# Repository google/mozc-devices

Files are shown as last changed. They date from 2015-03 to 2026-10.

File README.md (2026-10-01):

Circuit diagrams and firmware source code for Gboard DIY keyboards, previously
known as Google Japanese Input / Gboard April Fools.

This is not an officially supported Google product.

# Products

Please refer to the README in each directory for more details.

<table>
<tr>
<td>

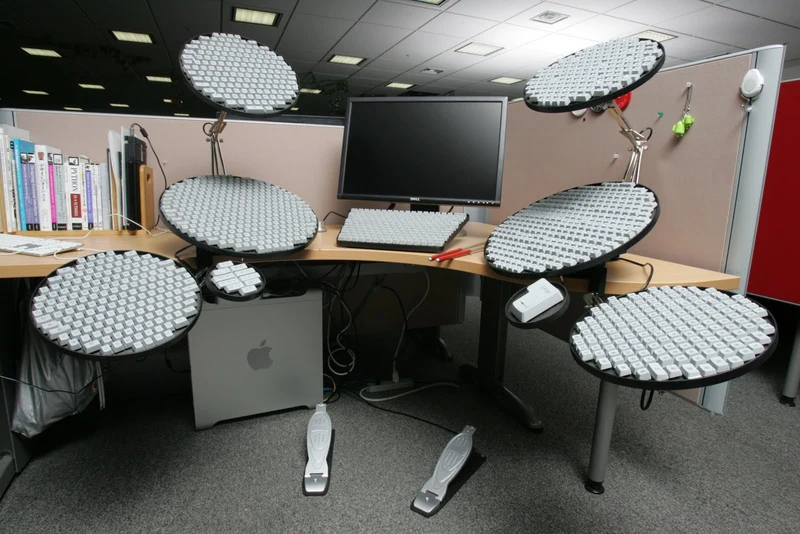
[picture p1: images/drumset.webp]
drumset


[Google 日本語入力 ドラムセットバージョン](https://archive.google/drumsetkeyboard/)<br>
[Google Japanese Input Drum set version](https://archive.google/drumsetkeyboard/)

変換の煩わしさを感じさせない思いどおりの日本語入力を提供します。

- [Announce](https://blog.google/intl/ja-jp/products/android-chrome-play/2010_04_google/)
- Release date: Apr 1, 2010
- Source: Not open source

</td>
<td>

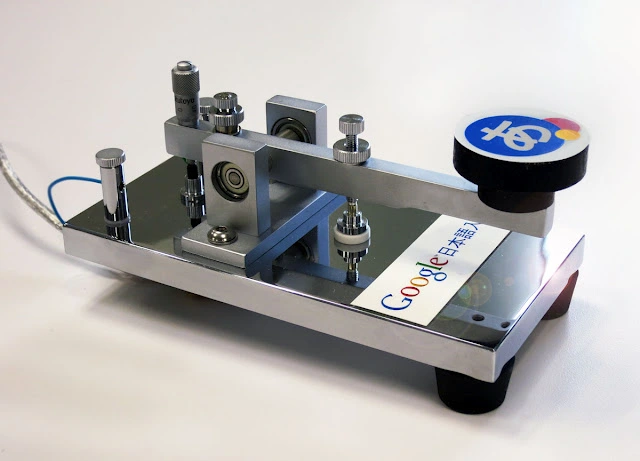
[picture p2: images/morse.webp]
morse


[Google 日本語入力 モールスバージョン](http://www.google.co.jp/ime/-.-.html)<br>
[Google Japanese Input Morse version](http://www.google.co.jp/ime/-.-.html)

モールス符号で思いどおりの日本語入力

- [Promotional video](https://www.youtube.com/watch?v=u5AYb778pwA)
- [Announce](https://japan.googleblog.com/2012/04/google.html)
- [Technical details](http://googledevjp.blogspot.jp/2012/06/google.html)
- Release date: Apr 1, 2012
- Source: [/third_party/mozc-morse](./third_party/mozc-morse)

</td>
</tr>
<tr>
<td>

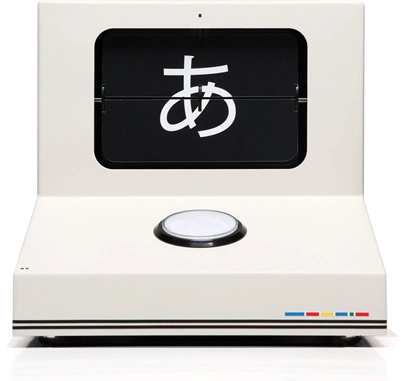
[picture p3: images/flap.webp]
flap


[Google 日本語入力 パタパタバージョン](http://www.google.co.jp/ime/patapata/)<br>
[Google Japanese Input Patapata version](http://www.google.co.jp/ime/patapata/)

もう、なにも覚える必要はありません。
押して離すだけの日本語入力。

- [Promotional video](https://www.youtube.com/watch?v=HzUDAaYMNsA)
- [Announce](https://japan.googleblog.com/2013/04/google-patapata.html)
- [Technical details](http://googledevjp.blogspot.jp/2013/10/google.html)
- Release date: Apr 1, 2013
- Source: [/third_party/mozc-flap](./third_party/mozc-flap)

</td>
<td>

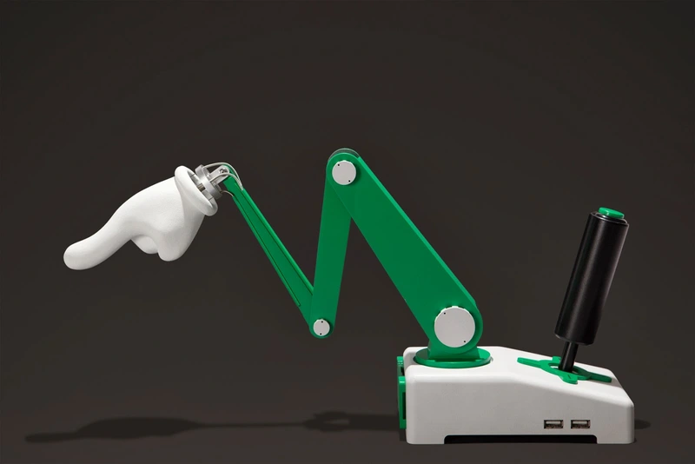
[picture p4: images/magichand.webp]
magichand


[Google 日本語入力 マジックハンドバージョン](https://archive.google/ime/m9/)<br>
[Google Japanese Input Magic hand version](https://archive.google/ime/m9/)

マジックハンドでらくらく入力

- [Promotional video](https://www.youtube.com/watch?v=0u1zoaJYAmw)
- [Announce](https://blog.google/intl/ja-jp/products/android-chrome-play/2014_04_m9/)
- Release date: Apr 1, 2014
- Source: Not open source

</td>
</tr>
<tr>
<td>

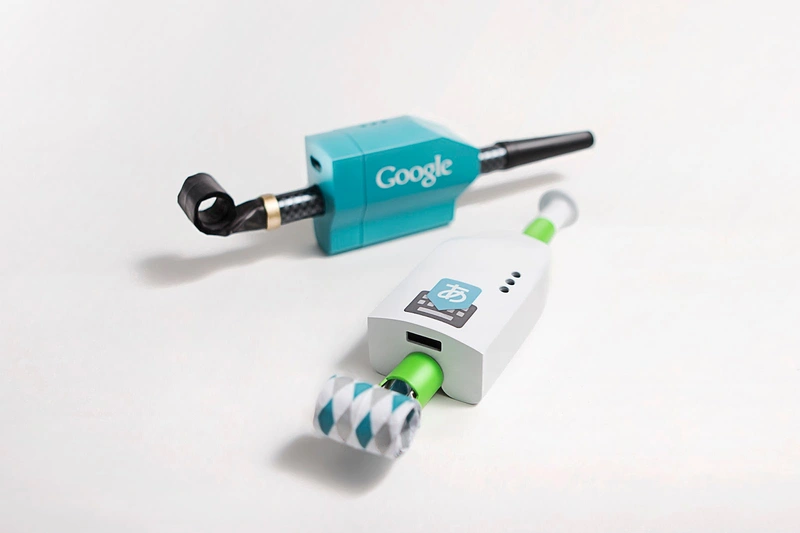
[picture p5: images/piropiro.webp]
piropiro


[Google 日本語入力 ピロピロバージョン](https://www.google.co.jp/ime/___o/)<br>
[Google Japanese Input Piropiro version](https://www.google.co.jp/ime/___o/)

もうキーはいらない

- [Promotional video](https://www.youtube.com/watch?v=gAgOnQqyDz0)
- [Announce](https://japan.googleblog.com/2015/04/piropiro.html)
- Release date: Apr 1, 2015
- Source: [/mozc-piropiro](./mozc-piropiro)

</td>
<td>

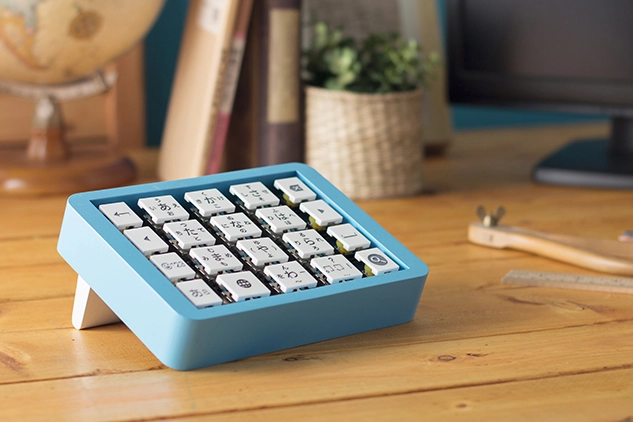
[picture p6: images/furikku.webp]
furikku


[Google 日本語入力 物理フリックバージョン](https://www.google.co.jp/ime/furikku/)<br>
[Google Japanese Input Physical Flick version](https://www.google.co.jp/ime/furikku/)

さわれるフリック

- [Promotional video](https://www.youtube.com/watch?v=5LI1PysAlkU)
- [Announce](https://japan.googleblog.com/2016/04/furikku.html)
- Release date: Apr 1, 2016
- Source: [/mozc-furikku](./mozc-furikku)

</td>
</tr>
<tr>
<td>

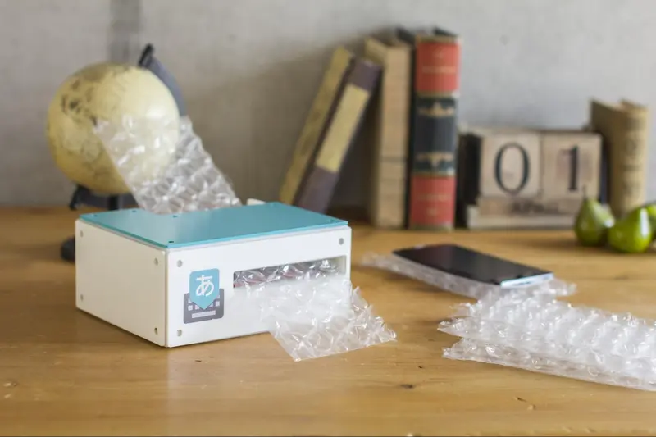
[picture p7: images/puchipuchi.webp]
puchipuchi


[日本語入力 プチプチバージョン](https://landing.google.co.jp/ime/ooooo/)<br>
[Google Japanese Input Puchi Puchi version](https://landing.google.co.jp/ime/ooooo/)

空気のように、軽やかな入力。

- [Promotional video](https://www.youtube.com/watch?v=RkJZDvHMyTA)
- [Announce](https://japan.googleblog.com/2017/04/ooooo.html)
- Release date: Apr 1, 2017
- Source: [/third_party/mozc-puchi](./third_party/mozc-puchi)

</td>
<td>

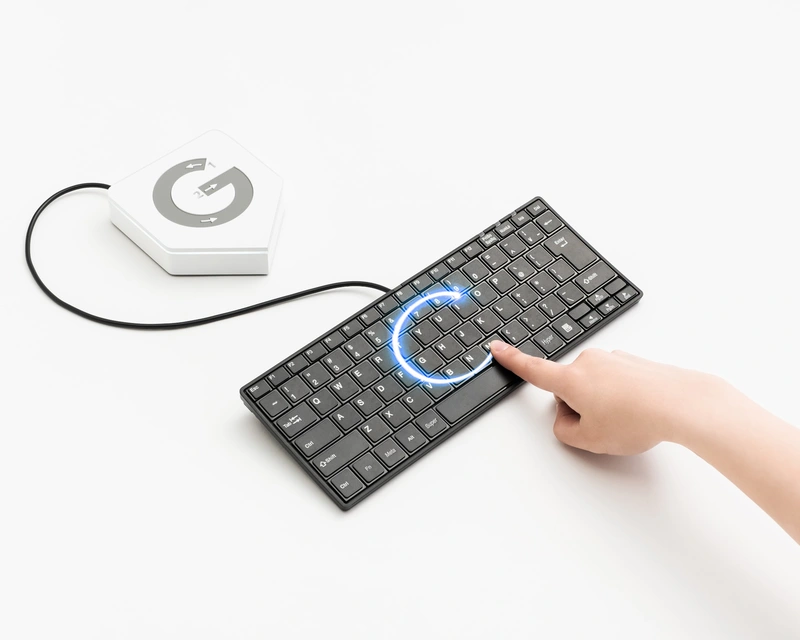
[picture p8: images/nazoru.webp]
nazoru


[Gboard 物理手書きバージョン](https://landing.google.co.jp/tegaki/)<br>
[Gboard Physical Handwriting version](https://landing.google.co.jp/tegaki/)

新しいタイプの手書き入力。

- [Promotional video](https://www.youtube.com/watch?v=guJnFY1R4I0)
- [Announce](https://japan.googleblog.com/2018/04/tegaki.html)
- [Technical details](https://developers-jp.googleblog.com/2018/04/tegaki.html)
- Release date: Apr 1, 2018
- Source: [/mozc-nazoru](./mozc-nazoru)

</td>
</tr>
<tr>
<td>

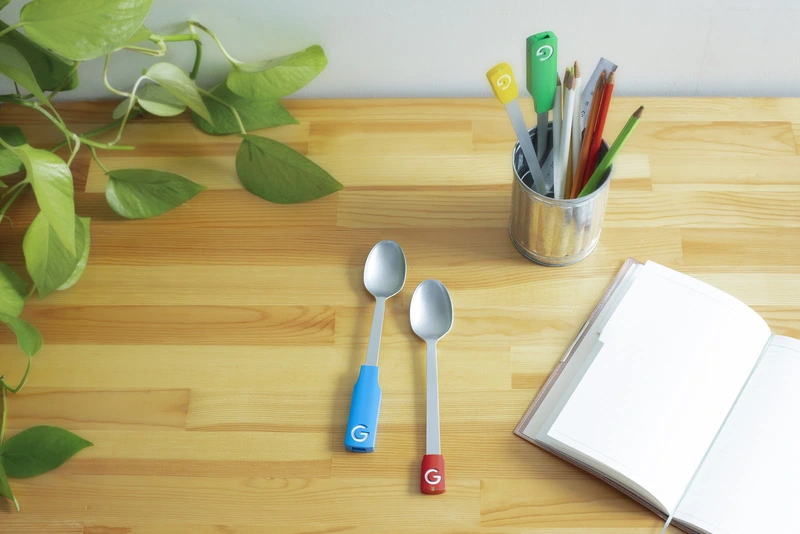
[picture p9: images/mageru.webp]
mageru


[Gboard スプーン曲げバージョン](https://landing.google.co.jp/---o/)<br>
[Gboard Spoon Bending version](https://landing.google.co.jp/---o/)

タネも仕掛けもない、柔軟な入力。

- [Promotional video](https://www.youtube.com/watch?v=DeJY5d14qKs)
- [Announce](https://japan.googleblog.com/2019/04/mageru.html)
- Release date: Apr 1, 2019
- Source:
  - [/mozc-mageru](./mozc-mageru) for firmware, schematics, and PCB layout.
  - [/third_party/mozc-mageru](./third_party/mozc-mageru) for 3D model.

</td>
<td>

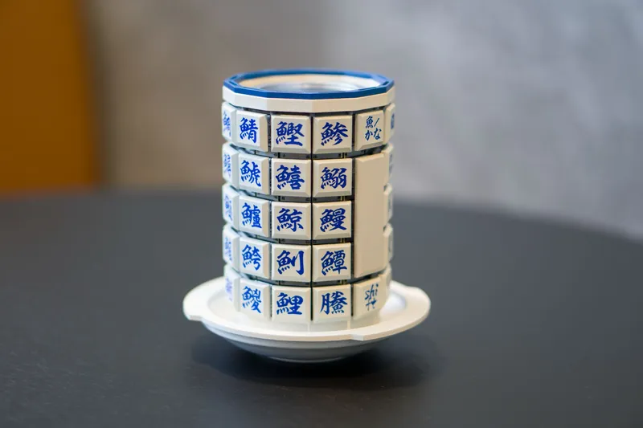
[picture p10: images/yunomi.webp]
yunomi


[Gboard 湯呑みバージョン](https://g.co/yunomi/)<br>
[Gboard yunomi version](https://g.co/yunomi/)

もう、おすしかない。

- [Promotional video](https://www.youtube.com/watch?v=20pC05yisRM)
- [Announce](https://japan.googleblog.com/2021/10/gboard.html)
- Release date: Oct 1, 2021
- Source: [/mozc-yunomi](./mozc-yunomi)

</td>
</tr>
<tr>
<td>

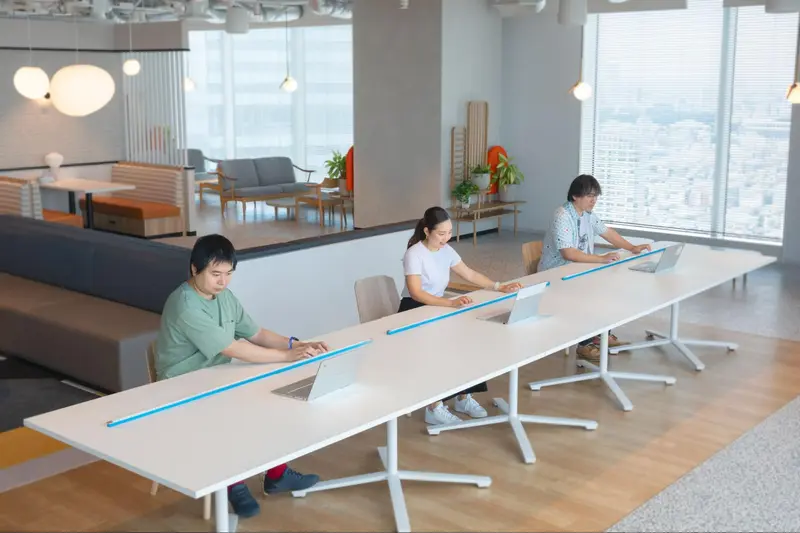
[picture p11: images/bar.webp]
bar


[Gboard 棒バージョン](https://g.co/____)<br>
[Gboard bar version](https://g.co/____)

キーの次はボーです。

- [Promotional video](https://www.youtube.com/watch?v=9G3DWHf1xX0)
- [Announce](https://japan.googleblog.com/2022/10/gboard-2022.html)
- Release date: Oct 1, 2022
- Source: [/mozc-bar](./mozc-bar)

</td>
<td>

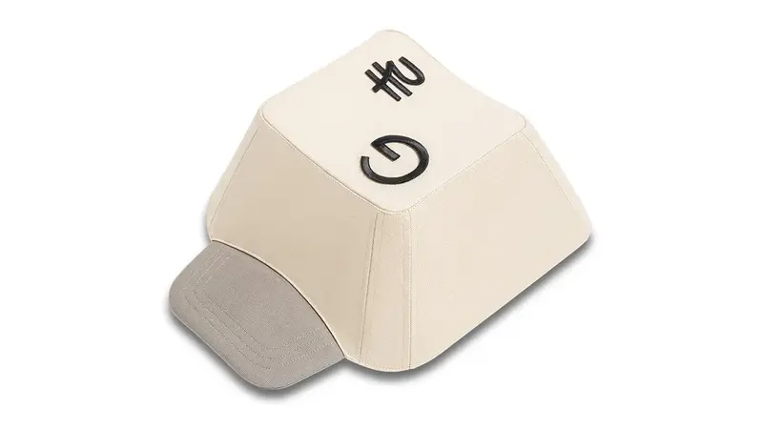
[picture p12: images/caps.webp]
caps


[Gboard 帽バージョン](https://g.co/CAPS)<br>
[Gboard CAPS version](https://g.co/CAPS)

入力は、帽険だ。

- [Promotional video](https://www.youtube.com/watch?v=6vib77CUxNM)
- [Announce](https://japan.googleblog.com/2023/10/caps.html)
- Release date: Oct 1, 2023
- Source: [/mozc-caps](./mozc-caps)

</td>
</tr>
<tr>
<td>

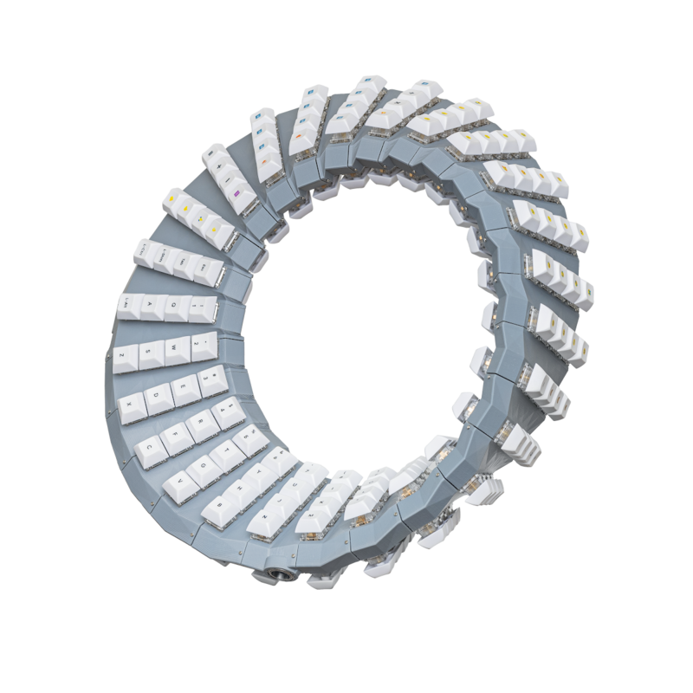
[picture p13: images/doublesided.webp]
double sided


[Gboard 両面バージョン](https://g.co/double-sided)<br>
[Gboard double sided version](https://g.co/double-sided)

表面かと思ったら裏面でした。

- [Promotional video](https://www.youtube.com/watch?v=EHqPrHTN1dU)
- [Announce](https://blog.google/intl/ja-jp/products/android-chrome-play/gboard-2024)
- Release date: Oct 1, 2024
- Source: [/mozc-doublesided](./mozc-doublesided)

</td>
<td>

dial

[Gboard ダイヤルバージョン](./mozc-dial/README_ja.md)<br>
[Gboard Dial Version](./mozc-dial)

まるくおさめました。

- [Promotional video](https://youtu.be/BgdWyD0cBx4)
- [Announce](https://blog.google/intl/ja-jp/products/android-chrome-play/gboard-2025)
- Release date: Oct 1, 2025
- Source: [/mozc-dial](./mozc-dial)

</td>
</tr>
<tr>
<td>

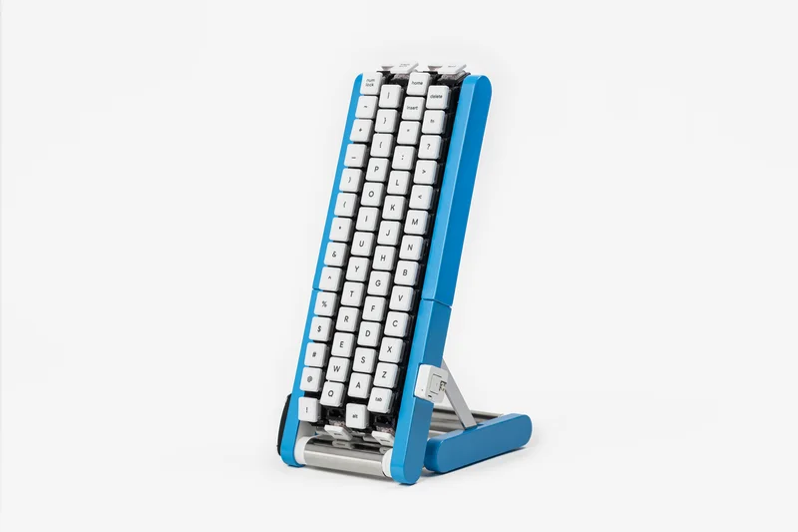
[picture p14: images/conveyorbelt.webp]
conveyorbelt


[Gboard くるくる バージョン](./mozc-conveyorbelt/README_ja.md)<br>
[Gboard Conveyor Belt version](./mozc-conveyorbelt)

流れるような文字入力を

- [Promotional video](https://www.youtube.com/watch?v=DAn34l_YrUM)
- [Announce](https://blog.google/intl/ja-jp/products/android-chrome-play/gboard-2026/)
- Release date: Oct 1, 2026
- Source: [/mozc-conveyorbelt](./mozc-conveyorbelt)

</td>
<td>
</td>
</tr>
</table>

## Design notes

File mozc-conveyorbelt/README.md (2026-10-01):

[Japanese version](./README_ja.md) is available.

# Gboard Conveyor Belt Version

This directory contains the design data and firmware for the Gboard Conveyor Belt Version, released on October 1, 2026.
The Gboard Conveyor Belt Version is not an official Google product.

Gboard conveyor belt version

## Contents

The directory structure is as follows:

- board/ : KiCad schematics and PCB layouts.
- firmware/ : Firmware source code and projects.
- stls/ : 3D printable STL files for the case and mechanisms.

## Let's build it

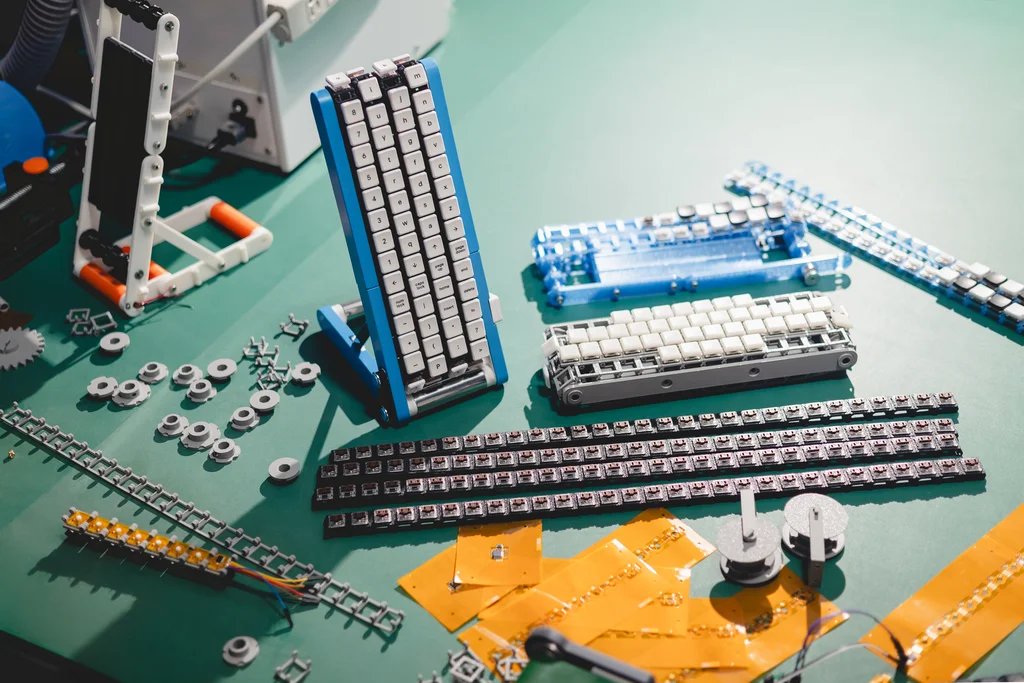
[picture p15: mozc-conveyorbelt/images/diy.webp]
Gboard DIY


This year again, we are releasing 3D printing model data, board data, and firmware.

[Click here for the build guide](./buildguide.md)

## There's also a Gboard that doesn't come to you

For those who are accustomed to moving their hands for text input, we also offer the standard version of Gboard.

It provides a comfortable input experience in conjunction with various Google services such as voice input and translation functions.

[Available on Google Play](https://play.google.com/store/apps/details?id=com.google.android.inputmethod.latin)<br>
[Available on the App Store](https://apps.apple.com/us/app/gboard-the-google-keyboard/id1091700242)

## [Other versions](https://github.com/google/mozc-devices)

## License

See [LICENSE](../LICENSE) file in this directory.

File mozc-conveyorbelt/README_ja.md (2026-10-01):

[English version](./README.md) is available.

# Gboard くるくる バージョン

このディレクトリは 2026 年 10 月 1 日にリリースされた Gboard くるくる バージョンの設計データとファームウェアを含んでいます。
Gboard くるくる バージョンは正式な Google 製品ではありません。

Gboard conveyor belt version

## 構成

ディレクトリ構成は以下の通りです：

- board/ : KiCad 回路図と基板レイアウトデータ
- firmware/ : ファームウェアのソースコードおよびプロジェクト
- stls/ : ケースや機構部品の 3D プリント用 STL ファイル

## 作ってみよう

Gboard DIY

今年も 3D プリント用モデルデータ、基板データ、ファームウェアを公開しています。

[ビルドガイドはこちら](./buildguide_ja.md)

## こないGboardもあります

いままでの手を動かす文字入力に慣れ親しんだ方には、通常版の Gboard もご用意しております。

音声入力や翻訳機能など Google の各種サービスと連携した快適な入力体験を提供します。

[Google Play で公開中](https://play.google.com/store/apps/details?id=com.google.android.inputmethod.latin&hl=ja)<br>
[App Store で公開中](https://apps.apple.com/jp/app/id1091700242)

## [その他のバージョン](https://github.com/google/mozc-devices)

## ライセンス

このディレクトリに置かれた [LICENSE](../LICENSE) ファイルを参照してください。

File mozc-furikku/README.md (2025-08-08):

Copyright 2016 Google Inc.

Licensed under the Apache License, Version 2.0 (the "License");
you may not use this file except in compliance with the License.
You may obtain a copy of the License at

    http://www.apache.org/licenses/LICENSE-2.0

Unless required by applicable law or agreed to in writing, software
distributed under the License is distributed on an "AS IS" BASIS,
WITHOUT WARRANTIES OR CONDITIONS OF ANY KIND, either express or implied.
See the License for the specific language governing permissions and
limitations under the License.

Summary
=====================================

Circuit diagram and firmware of Google Japanese Input physical flick version.

Files
=====================================

* README.md  -- this file
* arduino/flick/*  -- firmware source code (Arduino sketch)
* circuit.png  -- circuit diagram
* photo/*  -- for reference

Building your device
=====================================

## Electronic parts

* Arduino Nano * 1
* RN-42-I/RM * 1
* SJoys 2-axis joystick module (Sainsmart) * 12
* MCP3208 * 3
* 0.1uF ceramic capacitor * 4
* 470 ohm resistor * 1
* 1k ohm resistor * 1
* Connectors

## RN42 configuration

This step is required for the first time, or when changing the device's name.
See Microchip's documents for detail.

1. Run a terminal emulator and open the serial port for Arduino.
2. Type '!' to enter pass-through mode.
3. Type '$$$'.
4. Configure the module by these commands:

* * * * * *
    SU,115k
    SM,6
    SA,2
    S~,6
    SH,0000
    SN,MY_PHYSICAL_FLICK_KEYBOARD
    R,1
* * * * * *
MY\_PHYSICAL\_FLICK\_KEYBOARD is a device name that will appear when you scan
Bluetooth devices, and can be replaced by your preferred name.

The commands will configure the module as follows:

* 115200bps
* Pairing mode
* SSP "just works" mode
* SPP profile
* HID flag register = 0 (keyboard)

Using flick input
=====================================

## Power supply

When operating the device, supply power by USB cables to Arduino Nano.

## Bluetooth pairing

Using your device (e.g. Android phone), scan Bluetooth devices and you will
find MY\_PHYSICAL\_FLICK\_KEYBOARD (or the name you set up) in the available
device list.

After pairing, find the device in the "physical keyboard" section and choose
"English - U.S." keyboard layout for it.

## How to input

Switch the Japanese IME on the paired device to romaji input mode.
Characters will be input as flick or press a key.

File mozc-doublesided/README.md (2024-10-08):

# Gboard double sided version

This directory contains the firmware and hardware design for Gboard double sided
version, which was released on **Oct 1, 2024**.

This is not an officially supported Google product.

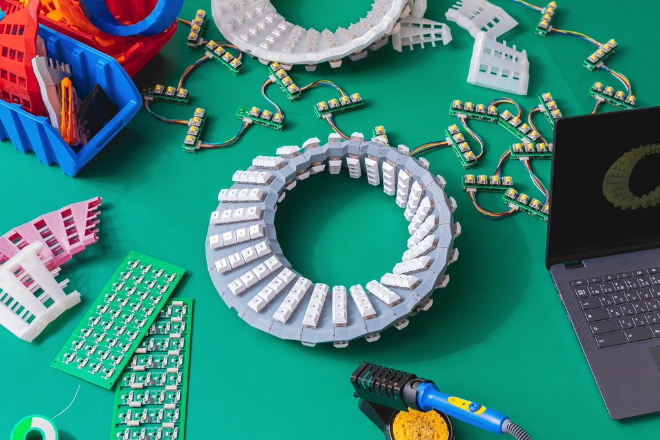
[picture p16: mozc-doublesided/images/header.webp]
Gboard double sided version


## Contents

The directory structure is as follows:

-   case/ : STL files for case
-   board/ : KiCad schematics and PCB layouts
-   firmware/ : Firmware resources for STM32CubeIDE
-   gerber/ : Gerber data for PCB production and assembly

## Building Gboard double-sided Version

### Parts

-   Assembled A Type Board: 26 boards (incl. 1 primary board) - See BOM below
-   Assembled B Type Board: 26 boards (incl. 1 primary board) - See BOM below
-   USB Board: 1 board - See BOM below
-   Cable A; JST ZH 1.5mm pitch 8pin 100mm forward double head: 25 units
-   Cable B; JST ZH 1.5mm pitch 7pin 100mm forward double head: 1 units
-   Pin Header; 1x4 pin 2.54mm pitch 12+mm height,
    ([sample](https://akizukidenshi.com/catalog/g/g101382/)): 52 headers.
-   3D printed case: 26 pcs
-   Self tapping screw (M2 10mm): 52 pcs
-   Key switch (Cherry MX or compatible): 208 pcs.
-   Key caps (For Cherry MX switch): 208 pcs.

#### A Type Board BOM

| Reference | Description | Qty | Note |
| --- | --- | --- | --- |
| R1-R2 | 0402(metric: 1005) Resistor 510 ohm | 2 | |
| R3-R4 | 0603(metric: 1608) Resistor 1K ohm  | 2 | Primary board only |
| J2-J3 | JST S8B-ZR | 2 | |
| J4 | JST S7B-ZR | 1 | Primary board only |
| U1 | STMicro STM32F042F4P6 | 1 | |
| SW1-SW4 | Kailh CPG151101S11-1 | 4 | |
| D1-D4 | OPSCO Optoelectronics SK6812MINI-E  | 4 | |
| D5-D8 | 0805(metric: 2012) Small Signal Switching Diode | 4 | |
| C1 | 0402(metric: 1005) Capacitor 0.1uF  | 1 | |

The parts that are only on the primary board are not included in the BOM file
(in `gerber/` directory), so make sure that you choose one board to be the
primary board and solder in the primary board specific parts.

#### B Type Board BOM

Reference | Description                                     | Qty | Note
--------- | ----------------------------------------------- | --- | ----
R2        | 0402(metric: 1005) Resistor 510 ohm             | 1   |
SW1-SW4   | Kailh CPG151101S11-1                            | 4   |
D1-D4     | OPSCO Optoelectronics SK6812MINI-E              | 4   |
D5-D8     | 0805(metric: 2012) Small Signal Switching Diode | 4   |

#### USB Board BOM

Reference | Description                          | Qty | Note
--------- | ------------------------------------ | --- | ----
U1        | 1A/3.3V Regulator AMS1117-3.3        | 1   |
R1-R2     | 0402(metric: 1005) Resistor 5.1K ohm | 2   |
R3-R4     | 0402(metric: 1005) Resistor 22 ohm   | 2   |
R5        | 0402(metric: 1005) Resistor 1.5K ohm | 1   |
J1        | JST S7B-ZR                           | 1   |
J2        | USB Type-C 16pin connector           | 1   |
C1        | 0402(metric: 1005) Capacitor 10uF    | 1   |
C2        | 0402(metric: 1005) Capacitor 2.2uF   | 1   |
C3-C4     | 0402(metric: 1005) Capacitor 47pF    | 2   |

### Hardware

#### Step 1: Prepare 3d printed parts

The `case/` directory of this repository has STL files for the case. The case
consists of 26 parts (case00.stl - case25.stl). Each part has a number engraved
on the inside. For example, when assembling, you will insert the protrusion of
case 0 into the hole of case 1.

We also provide a jig (`case/jig.stl`) for soldering between the A type boards
and B type boards. Please print this too.

#### Step 2: Prepare PCB

**PCB Production and Assembly**

First, you need to build 26 A type boards and 26 B type boards, and one USB
board. You may be able to use existing gerber data, BOM, and CPL (positions)
from `gerber/` directory.

Board Type | Gerber         | BOM                | CPL
---------- | -------------- | ------------------ | ------------------------
A          | main_panel.zip | main_panel_bom.csv | main_panel_positions.csv
B          | sub_panel.zip  | sub_panel_bom.csv  | sub_panel_positions.csv
USB        | usb.zip        | usb_bom.csv        | usb_positions.csv

Prepared board data for the A type board and the B type board contains 9 boards
in a panel. So, you need to produce 3 panels to build 27 (26 required + 1 spare)
boards. You also need one USB board.

**Firmware upload**

Next, let's burn the prebuilt firmware.

Connect the following 4 pads, SWDIO, SWCLK, GND, and +3.3V with ST-LINK. You can
use
[STM32CubeProgrammer](https://www.st.com/ja/development-tools/stm32cubeprog.html)
to configure the device and to burn the prebuilt firmware. There's no connector,
just holes in the PCB so make sure you keep a secure connection while
programming the device.

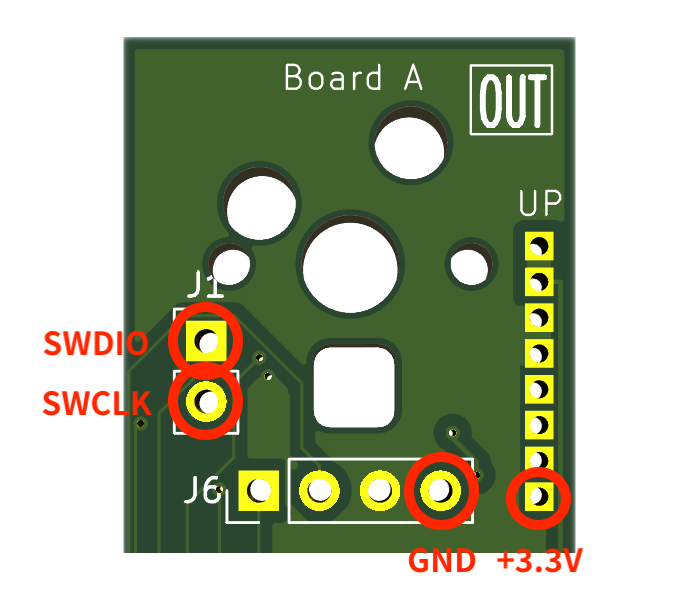
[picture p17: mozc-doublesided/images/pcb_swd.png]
Required SWD and power pins


Once the programmer establishes the connection with the A type board, you need
to write the `Option bytes`. Under the `User Configuration` section, you will
see the `BOOT_SEL` bit. You need to ensure the bit is unchecked before pushing
the `Apply` button.

Next, you will go to the `Erasing & Programming` section to burn the prebuilt
firmware, `firmware/prebuilt/mozc.elf`. Select the binary from the `Browse`
button, put `0x08000000` for the `Start address`, then press the `Start
Programming` button.

You need to burn the same settings and firmware into all the Boards A.

**Primary A Type Board Specific Modifications**

You need to choose one of the A type boards to be the primary A type board and
add three parts to it.

1.  J4 JST S7B-ZR connector header
2.  R3 0603 Resistor 1K ohm
3.  R4 0603 Resistor 1K ohm

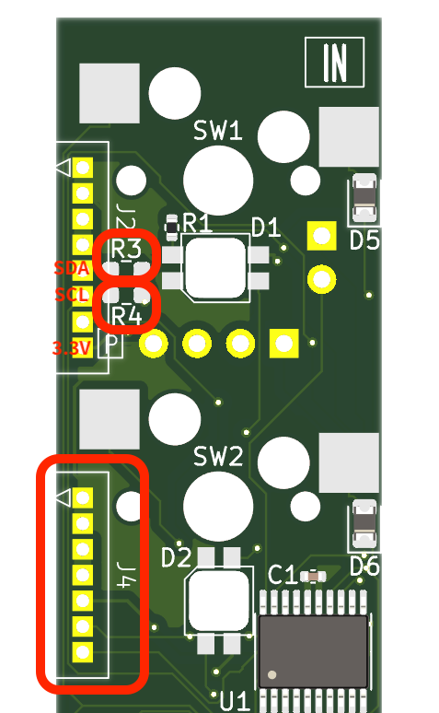
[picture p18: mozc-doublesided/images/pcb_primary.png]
Primary A Type Board Modifications Points


**Construct the A/B Type Board Pair Modules**

You need to prepare 26 pairs of the A type board and B type board. They should
be paired as the following picture shows. Each `P Connector` and each `S
connector` should be connected using the 1x4 pin headers respectively.

Make sure that the `IN` side of the A type board and B type board face each
other.

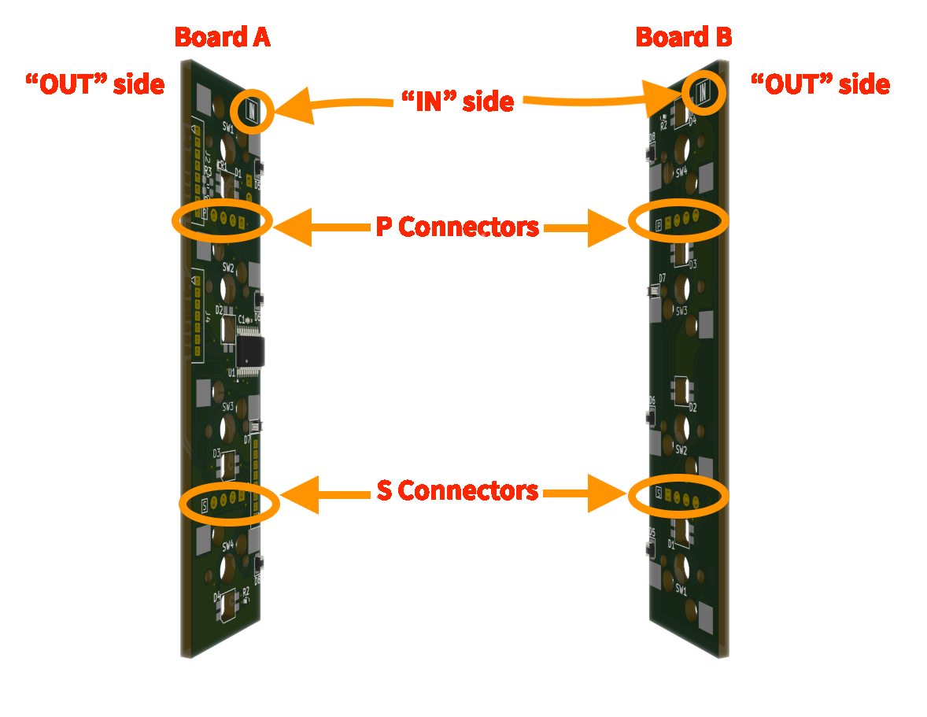
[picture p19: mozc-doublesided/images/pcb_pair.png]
Pairing A type board and B type boards


Also, the distance should be adjusted to fit the case. It will help to print the
included jig STL to hold both boards while soldering the pin headers.

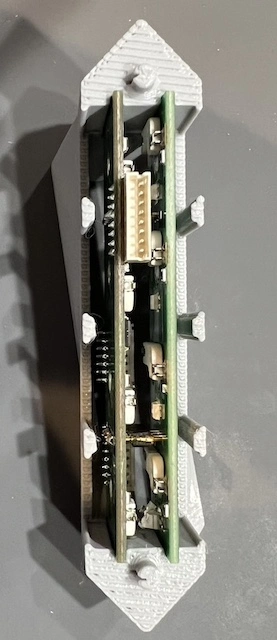
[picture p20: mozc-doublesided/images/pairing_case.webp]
Pairing with actual case

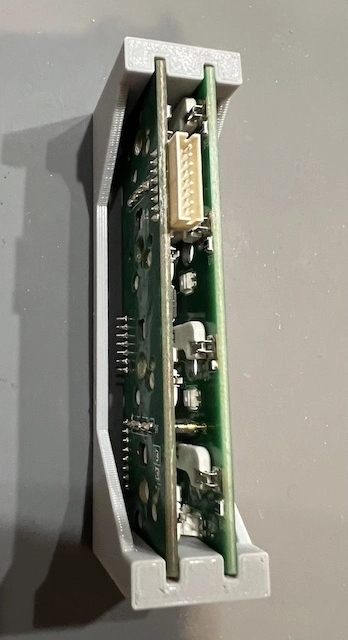
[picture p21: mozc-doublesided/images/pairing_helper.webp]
Pairing with helper case


#### Step 3: Insert PCB to case

**Primary A/B Pair Module**

Connect the primary module and the USB board.

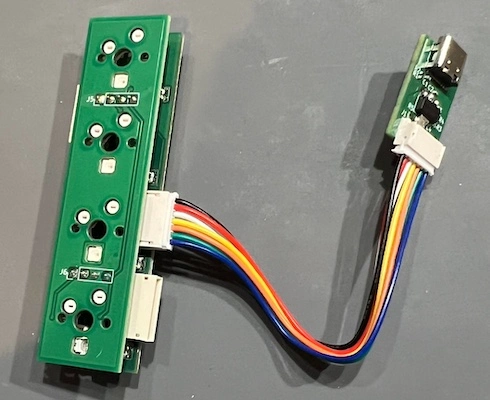
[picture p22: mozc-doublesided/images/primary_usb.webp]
Connect Primary and USB board


Insert the USB board into case 0.

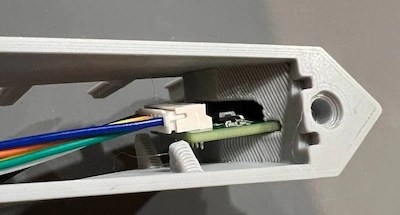
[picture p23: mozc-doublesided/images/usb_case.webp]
Insert USB board to the case


**All Pair Modules**

Insert each paired module into a case. You need to ensure the A type board is
always placed on the bottom side.

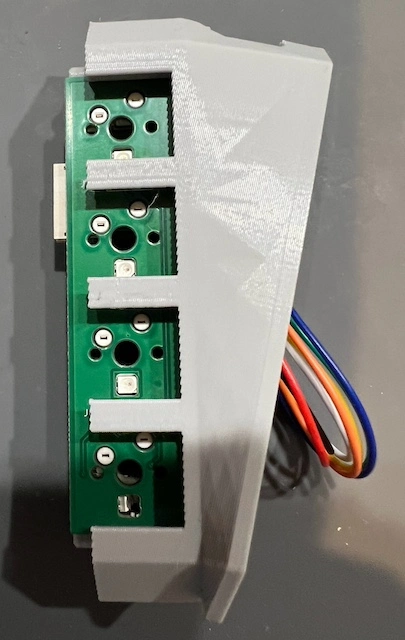
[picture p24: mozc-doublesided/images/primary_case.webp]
Insert the pair board into the case


#### Step 4: Connect the cases together

You need to connect all the `UP` socket and `DOWN` socket pairs. Please be
careful not to connect the same type of socket, i.e. `UP` and `UP`, or `DOWN`
and `DOWN` together. It will cause a short circuit and destroy the chips when
powered on. If you notice a smell or see smoke, disconnect the power
immediately. This may prevent damage to the boards.

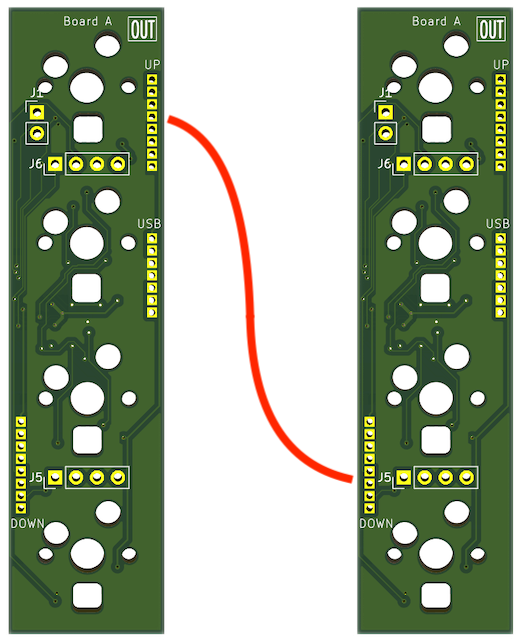
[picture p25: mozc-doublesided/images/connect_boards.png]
Connect boards


The below picture shows the connections. Please make sure that module 0 and
module 25 are not connected to each other.

Note that this picture is simplified and doesn't reflect the 3d structure of the
keyboard. So, module 25 will be placed upside down.

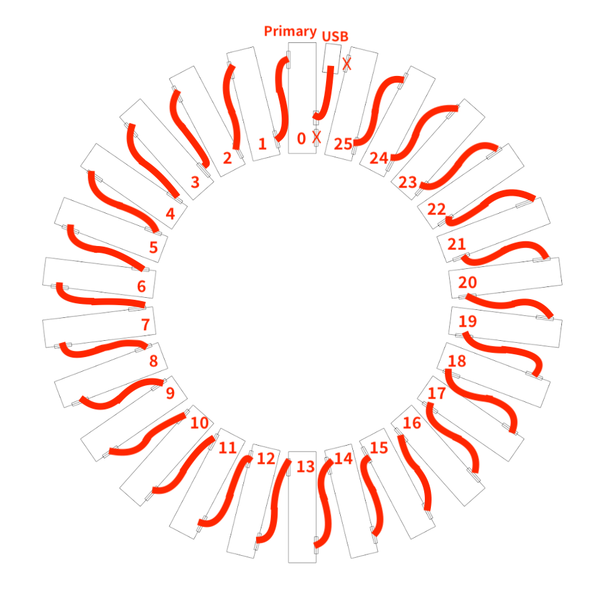
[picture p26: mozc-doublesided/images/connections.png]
Connections


You can use screws to keep the boards tightly connected.

### Firmware

#### Step 1: Environment setup

You need to install STMicroelectronics's official tools to develop STM32.

-   [STM32CubeIDE](https://www.st.com/en/development-tools/stm32cubeide.html) -
    Confirmed with 1.16.1.
-   [STM32CubeMX](https://www.st.com/en/development-tools/stm32cubemx.html) -
    Confirmed with 6.12.1.

Alternatively, you can use Visual Studio Code with the STM32 VS Code Extension,
STM32CubeMX, and STM32CubeCLT if your development environment is not on Windows.

-   [Visual Studio Code](https://code.visualstudio.com/) - Confirmed with
    1.93.0.
-   [STM32 VS Code Extension](https://marketplace.visualstudio.com/items?itemName=stmicroelectronics.stm32-vscode-extension) -
    Confirmed with 2.1.0.
-   [STM32CubeCLT](https://www.st.com/en/development-tools/stm32cubeclt.html) -
    Confirmed with 1.16.1. You will be asked to specify the path to the VS Code
    Extension. You may add `{ "STM32VSCodeExtension.cubeCLT.path":
    "/opt/ST/STM32CubeCLT_1.16.1" }` to `.vscode/settings.json`.

    You will need the
    [ST-LINK](https://www.st.com/ja/development-tools/st-link-v2.html) or
    something equivalent to upload the firmware.

#### Step 2: Compile and upload

**Steps for the STM32CubeIDE:**

1.  Launch STM32CubeIDE with `mozc-doublesided` directory as `workspace`.
2.  Start a project via `Start new project from STM32CubeMX file (.ioc)` to open
    a configuration dialog.
3.  Select `firmware/mozc-doublesided.ioc` as `STM32CubeMX .ioc file` and push
    `Finish` button to generated required resources.
4.  Apply patches. (See the following instructions)
5.  Set `Release` as the active project, from `Project > Build Configurations >
    Set Active > 2 Release`. `Debug` doesn't fit the available memory size.
6.  Build, from `Project > Build All`.

The built binary will be produced at `firmware/Release/firmware.elf`.

**Steps for the Visual Studio Code:**

1.  Open `firmware/mozc-doublesided.ioc` by STM32CubeMX and push the `GENERATE
    CODE` button. You may need to follow instructions if you are asked to
    install something required in the process.
2.  Launch VSCode and open the folder `firmware`.
3.  Apply patches. (See the following instructions)
4.  Select `Release` or `RelWithDebInfo` from the build presets. `Debug` doesn't
    fit the available memory size.
5.  `Build` from the status bar, or other user interfaces.

The built binary will be produced at `build/Release/firmware.elf`.

If you saw errors on linking the binary involving `STM32F042F6Px_FLASH.ld`, you
may need a patch to make it work with your installed toolchain.

Try `patch < STM32F042F6Px_FLASH.ld.diff`.

**Steps to apply patches:**

In the `firmware` directory, apply the `firmware.diff` patch to the generate
resources via the following command.

`$ patch -p1 < firmware.diff`

## License

See [LICENSE](../LICENSE) file in this directory.

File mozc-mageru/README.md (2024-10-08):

# Gboard Spoon Bending Version

This contains programs, schematics and board layouts for Gboard Spoon Bending Version, which was released on **Apr 1, 2019**.

This is not an officially supported Google product.

# Contents

Directory structure is as follows.

- wireless/
  - firmware/
    - Firmware for the wireless version. (coming soon)
  - board/
    - Schematic and PCB layout made by EAGLE.
- wired/
  - firmware/
    - Arduino sketch for the wired version.
- ../third_party/mozc-mageru/spoon_stl/
   - Spoon shape data for 3D printing.

# Wired Version

## The spoon

Print the spoon under /third_party/mozc-mageru/spoon_stl/ using a 3D printer.
This is an example design of a flexible spoon that has a slot to embed a
flex sensor into.
We have tried it with PLA, but it will probably work with ABS as well.

## Electronic circuit

- Arduino Micro
- 22k-ohm resistor
- Flex sensor: FS-L-0055-253-ST (Spectra Symbol)

```
    Arduino Micro

         5V ---[22k ohm]-------+
                               |
         A5 -------------------+
                               |
        GND ---[Flex sensor]---+
```

## How to use the firmware

1. Open the sketch on Arduino IDE.
2. Choose "Arduino/Genuino Micro" in the [Tools]-[Board] menu.
3. If you are making Japanse-hiragana version, add ```#define JAPANESE_``` to the first line of the sketch
4. Upload to board.

## Sensor calibration

1. Open Serial Monitor.
2. Send '!' once to disable key output.
3. (the home position, which decides when to commit a character)
   Bend the sensor slightly and send '0'. Make sure the LED turns off when the spoon is not bent by external force.
4. (the position for the first letter)
   Bend the sensor slightly a bit more and send '1'.
5. (the position for the last letter)
   Bend the sensor to the end and send '2'.
6. Send 'w' to save the configuration to EEPROM.
7. Send '!' again to enable key output, or reset the device.

# Wireless Version

Coming soon.

# License

```
Licensed under the Apache License, Version 2.0 (the "License"); you may
not use this file except in compliance with the License. You may obtain
a copy of the License at

    http://www.apache.org/licenses/LICENSE-2.0

Unless required by applicable law or agreed to in writing, software
distributed under the License is distributed on an "AS IS" BASIS,
WITHOUT WARRANTIES OR CONDITIONS OF ANY KIND, either express or implied.
See the License for the specific language governing permissions and
limitations under the License.
```

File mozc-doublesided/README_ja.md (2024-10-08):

# Gboard 両面バージョン

このディレクトリは 2024 年 10 月 1 日にリリースされた Gboard 両面バージョンの設計データとファームウエアを含んでいます。

Gboard 両面バージョンは正式な Google 製品ではありません。

Gboard double sided version

## 内容

このディレクトリには以下の物が含まれています。

-   case/ : ケース用のSTLファイル
-   board/ : KiCad用の回路図と基板のレイアウトデータ
-   firmware/ : STM32CubeIDE向けファームウェア開発リソース一式
-   gerber/ : 基板製造用ガーバーデータと組み立て用の配置情報

## Gboard 両面バージョンの制作

### 部品

-   組み立て済みAタイプ基板: 26個（プライマリ基板1枚を含む） - 下記の部品表を参照
-   組み立て済みBタイプ基板: 26個（プライマリ基板1枚を含む） - 下記の部品表を参照
-   USB基板: 1個 - 下記の部品表を参照
-   ケーブルA（JST ZH 1.5mmピッチ 8ピン 100mm長 ストレート結線 両面メス）: 25個
-   ケーブルB（JST ZH 1.5mmピッチ 7ピン 100mm長 ストレート結線 両面メス）: 1個
-   ピンヘッダ（2.54mmピッチ 1x4ピン 12mm以上の高さ,
    [参考](https://akizukidenshi.com/catalog/g/g101382/)): 52個
-   3D プリントしたケース部品 : 26種類1つずつ
-   セルフタッピングビス(M2): 52本
-   キースイッチ(Cherry MXもしくは相当品): 208個
-   キーキャップ(Cherry MXスイッチ用): 208個

#### Aタイプ基板 部品表

参照名     | 内容                                 | 数   | 備考
------- | ---------------------------------- | --- | ---------
R1-R2   | 0402(1005) 抵抗 510 Ω                | 2   |
R3-R4   | 0603(1608) 抵抗 1K Ω                 | 2   | プライマリ基板のみ
J2-J3   | JST S8B-ZR                         | 2   |
J4      | JST S7B-ZR                         | 1   | プライマリ基板のみ
U1      | STMicro STM32F042F4P6              | 1   |
SW1-SW4 | Kailh CPG151101S11-1               | 4   |
D1-D4   | OPSCO Optoelectronics SK6812MINI-E | 4   |
D5-D8   | 0805(2012) 小信号用スイッチングダイオード         | 4   |
C1      | 0402(1005) コンデンサ 0.1uF             | 1   |

プライマリ基板のみの部品は基板組立データには含まれていないため、別途手作業で組み立てるために調達して下さい。

#### Bタイプ基板 部品表

参照名     | 内容                                 | 数   | 備考
------- | ---------------------------------- | --- | ---
R2      | 0402(1005) 抵抗 510 Ω                | 1   |
SW1-SW4 | Kailh CPG151101S11-1               | 4   |
D1-D4   | OPSCO Optoelectronics SK6812MINI-E | 4   |
D5-D8   | 0805(2012) 小信号用スイッチングダイオード         | 4   |

#### USB基板 部品表

参照名   | 内容                         | 数   | 備考
----- | -------------------------- | --- | ---
U1    | 1A/3.3V レギュレータ AMS1117-3.3 | 1   |
R1-R2 | 0402(1005) 抵抗 5.1K Ω       | 2   |
R3-R4 | 0402(1005) 抵抗 22 Ω         | 2   |
R5    | 0402(1005) 抵抗 1.5K Ω       | 1   |
J1    | JST S7B-ZR                 | 1   |
J2    | USB Type-C 16ピン コネクタ       | 1   |
C1    | 0402(1005) コンデンサ 10uF      | 1   |
C2    | 0402(1005) コンデンサ 2.2uF     | 1   |
C3-C4 | 0402(1005) コンデンサ 47pF      | 2   |

### ハードウェア

#### ステップ1: 3Dプリント用パーツの準備

`case/` ディレクトリにはケース用のSTLファイルがあります。 ケースは26個のパーツからなります (parts00.stl -
parts25.stl)。 それぞれのパーツの内側にはパーツ番号が刻印されています。 例えばパーツ0の突起をパーツ1に差し込む形で組み立てる事になります。

また、基板AタイプとBタイプをはんだ付けするための治具が `case/jig.stl` も用意してありますので、これも印刷しておきます。

#### ステップ2: 基板の準備

**基板の製造と組立**

まず、Aタイプ、Bタイプそれぞれの基板を26枚ずつ、USB基板を1枚作る必要があります。 `gerber/`
ディレクトリにあるガーバーデータ、BOMデータ、CPLデータを参考にして下さい。

基板タイプ | ガーバー           | BOM                | CPL
----- | -------------- | ------------------ | ------------------------
Aタイプ  | main_panel.zip | main_panel_bom.csv | main_panel_positions.csv
Bタイプ  | sub_panel.zip  | sub_panel_bom.csv  | sub_panel_positions.csv
USB   | usb.zip        | usb_bom.csv        | usb_positions.csv

Aタイプ、Bタイプ基板向けのデータは9個の基板がパネル化されたデータになっています。
このパネル化されたデータで3枚製造すると、27枚（必要な26枚と予備1枚）の基板が得られます。 USB基板は単体で1枚だけ必要です。

**ファームウェア書き込み**

次にファームウェアを書き込みます。

図のSWDIO、SWCLK、GND、そして+3.3Vの端子をST-LINKと繋ぎます。
[STM32CubeProgrammer](https://www.st.com/ja/development-tools/stm32cubeprog.html)
を使って設定やファームウェアの書き込みを行えます。 コネクタ等は用意されていない生の端子なので、きちんと接触するように注意しながら書き込みます。

必要となるSWDと電源関連のピン

Aタイプ基板との接続が確立したら、まず`Option bytes`を書き込みます。 `User
Configuration`の項に`BOOT_SEL`があるので、そのチェックを外して`Apply`ボタンを押して設定を更新します。

次に`Erasing & Programming`の項からファームウェアを書き込みます。
`Browse`ボタンを押して`firmware/prebuilt/mozc.elf`を選びます。 `Start
address`には`0x08000000`を指定し、`Start Programming`ボタンを押します。

同様にして全てのAタイプ基板に設定とファームウェアを書き込みます。

**プライマリAタイプ基板固有の実装**

以下の3つの部品をプライマリ基板にのみ実装します。

1.  J4 JST S7B-ZR コネクタ ヘッダ端子
2.  R3 0603(1608) 抵抗 1K Ω
3.  R4 0603(1608) 抵抗 1K o

プライマリAタイプ基板変更箇所

**A/Bボードペアモジュールの作成**

26対のAタイプ基板、Bタイプ基板のペアモジュールを作成する必要があります。 下図のように、`P Connector`と`S
connector`それぞれ同じコネクタ同士を1x4のピンヘッダで連結します。

この最、`IN`と書かれた基板面がそれぞれ内側を向くように注意しましょう。

AタイプとBタイプの基板を連結する

また、基板の距離がケースにフィットするよう適切に調整されている必要があります。 この作業用の特別なケースを3Dプリントして用いると効率的に作業できます。
実際のケースを使って確認しながら作業する事も可能です。

実際のケースを使って
作業用ケースを使って

#### ステップ3: 基板をケースに入れる

**プライマリモジュール固有の作業**

まず、プライマリモジュールとUSB基板をケーブルで接続します。

プライマリモジュールとUSB基板の接続

次にUSB基板を0番のケースに格納します。

USB基板をケースに格納

**全てのモジュール共通の作業**

全てのペアモジュールを0から25番のケースにそれぞれ格納します。 Aタイプ基板が常に下側になるよう気をつけます。

ペアモジュールをケースに格納

#### ステップ4: ケース同士を連結する

`UP`端子と`DOWN`端子の対をケーブルで接続していきます。 同じ端子同士を誤って接続しないよう注意して下さい。
電源を入れた時にショートによりチップが焼け焦げる事になります。 （匂いや煙に気づいたら直ぐに電源を抜けば壊れずに済むことも多いです）

基板の接続

次の全体図を参考にしてください。 最初のモジュール0と最後のモジュール25は接続されていない事に注意します。

また、この図は簡単のために本来発生する「ねじれ」を考慮した図になっていません。 実際に組み立てた際にはモジュール25は上下逆さの向きになります。

連結

ネジを使って各ボード間をしっかり固定してください。

### ファームウェア

#### ステップ1: 開発環境の構築

STMicroelectronics社公式のSTM32開発ツールが必要になるので、以下からインストールします。

-   [STM32CubeIDE](https://www.st.com/en/development-tools/stm32cubeide.html) -
    1.16.1にて確認
-   [STM32CubeMX](https://www.st.com/en/development-tools/stm32cubemx.html) -
    6.12.1にて確認

また、Windows以外の環境では、Visual Studio CodeにSTM32 VS Code Extensionをインストールする事でも開発できます。
STM32CubeMXとSTM32CubeCLTを別途公式からインストールする必要があります。

-   [Visual Studio Code](https://code.visualstudio.com/) - 1.93.0にて確認
-   [STM32 VS Code Extension](https://marketplace.visualstudio.com/items?itemName=stmicroelectronics.stm32-vscode-extension) -
    2.1.0にて確認
-   [STM32CubeCLT](https://www.st.com/en/development-tools/stm32cubeclt.html) -
    1.16.1にて確認 VS Code ExtensionではCLTのパスを設定するよう指示がでるかもしれません。
    その際には以下を参考に`.vscode/settings.json`へ設定を書いて下さい。 `{
    "STM32VSCodeExtension.cubeCLT.path": "/opt/ST/STM32CubeCLT_1.16.1" }`

また、書き込みには[ST-LINK](https://www.st.com/ja/development-tools/st-link-v2.html)などのデバイスが必要になります。

#### ステップ2: コンパイルと書き込み

**STM32CubeIDEの場合**

1.  STM32CubeIDEを起動し、`mozc-doublesided`ディレクトリを`workspace`として指定します。
2.  `Start new project from STM32CubeMX file (.ioc)`から設定ダイアログを開きます。
3.  `STM32CubeMX .ioc
    file`として`firmware/mozc-doublesided.ioc`を選び、`Finish`ボタンを押して必要なリソースを生成します。
4.  パッチをあてます（後述）
5.  `Project > Build Configurations > Set Active > 2 Release`から
    アクティブプロジェクトを`Release`に指定します。 `Debug`ではプログラムが大きくなりメモリに入り切りません。
6.  `Project > Build All`からビルドします。

ファームウェアは`firmware/Release/firmware.elf`として生成されます。

**Visual Studio Codeの場合**

1.  STM32CubeMXから`firmware/mozc-doublesided.ioc`を開き、`GENERATE CODE`を押します。
    追加で何かインストールを促された場合には指示に従ってください。
2.  Codeを起動し、`firmware`を開きます。
3.  パッチをあてます（後述）
4.  ビルドプリセット設定から`Release`か`RelWithDebInfo`を選びます。
    `Debug`ではプログラムが大きくなりメモリに入り切りません。
5.  ステータスバーから`Build`を押します。他のUIからビルドする方法もありますが、ここでは触れません。

ファームウェアは`build/Release/firmware.elf`として生成されます。

もしリンク時に`STM32F042F6Px_FLASH.ld`が原因でエラーが出ていたら、該当ファイルに修正を加える必要があります。

パッチを用意したので`patch < STM32F042F6Px_FLASH.ld.diff`をお試し下さい。

**パッチ手順**

`firmware`ディレクトリにて、以下のコマンドで生成されたファイルに`firmware.diff`をパッチとして適用して下さい。

`$ patch -p1 < firmware.diff`

## ライセンス

このディレクトリに置かれた[LICENSE](../LICENSE)ファイルを参照してください。

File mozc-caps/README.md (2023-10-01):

# Gboard CAPS version

This directory contains the firmware and hardware design for Gboard CAPS
version, which was released on **Oct 1, 2023**.

This is not an officially supported Google product.

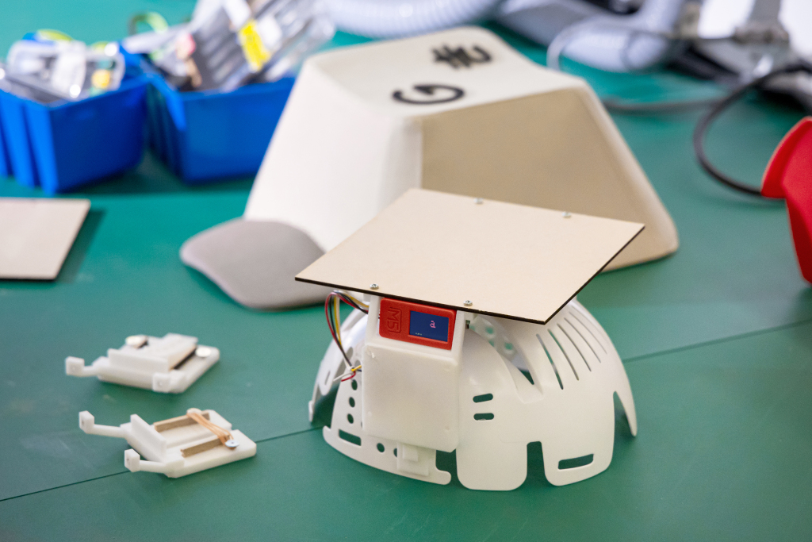
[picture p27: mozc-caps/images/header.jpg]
Gboard CAPS version


## Contents

The directory structure is as follows:

- hardware/ : STL files for mechanical parts.
- firmware/ : Arduino sketch.

## Building Gboard CAPS Version

### Parts

- M5StickC Plus
- SS-10GL13 micro switch
- [INC-100 bump cap insert](https://www.midori-helmet.jp/pickup/inc-100/)
- [Grove connector cable](https://akizukidenshi.com/catalog/g/gC-16938/)
- M3x10mm screw x 8
- M2x8mm screw x 2
- rubber band x 4
- hot glue
- heat shrink tubing
- 160mm x 160mm x T2.5mm MDF board (or substitute a 3D printed part; see next
  section)

### Hardware

#### Step 1: Prepare required parts

3D printed parts:

- [bump cap insert mount](./hardware/bump_cap_insert_mount.stl) x 2
  \
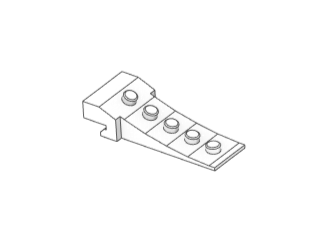
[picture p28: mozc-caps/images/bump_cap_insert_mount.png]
bump cap insert mount
  
- [sliding plate](./hardware/sliding_plate.stl) x 2
  \
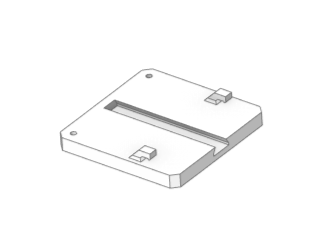
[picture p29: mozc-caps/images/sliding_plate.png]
sliding plate
  
- [top plate angle bracket mount](./hardware/top_plate_angle_bracket_mount.stl)
  x 2
  \
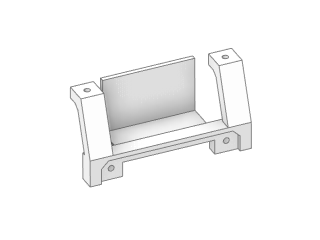
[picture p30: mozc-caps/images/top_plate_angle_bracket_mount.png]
top plate angle bracket mount
  
- [switch mount](./hardware/switch_mount.stl) x 1
  \
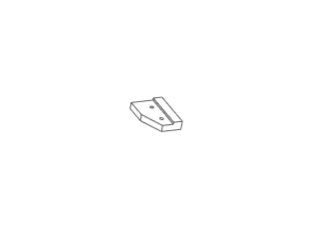
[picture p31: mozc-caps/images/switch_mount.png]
switch mount
  

Other parts:

- top plate: made of 160mm x 160mm x T2.5mm MDF board
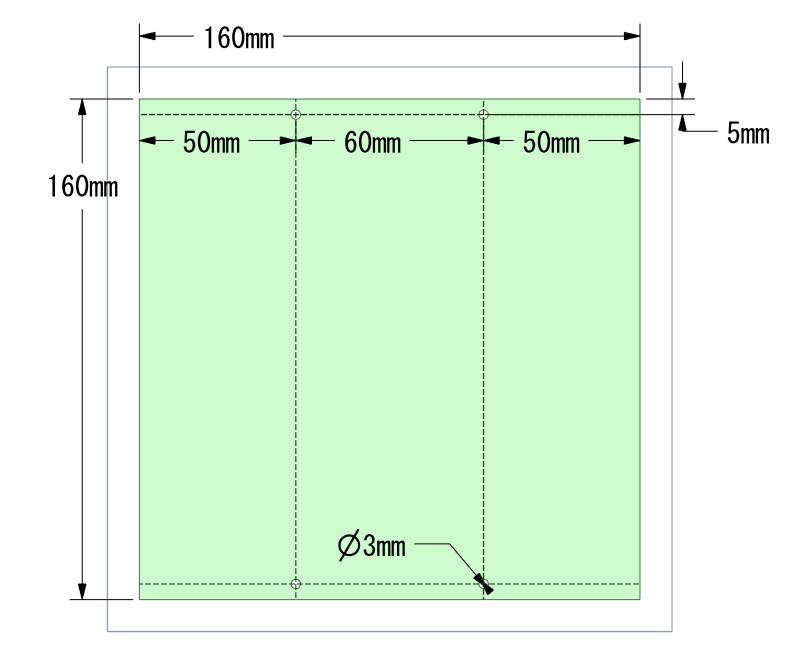
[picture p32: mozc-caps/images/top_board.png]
top plate
   \
  Alternatively, you can 3D print this
  part ([top_plate.stl](./hardware/top_plate.stl))

#### Step 2: Wiring

Connect the NO and the C terminals of the micro switch to the black and yellow
wires of the Grove cable, in any order. (These will be connected to port G33 and
GND of M5StickC Plus.)
\
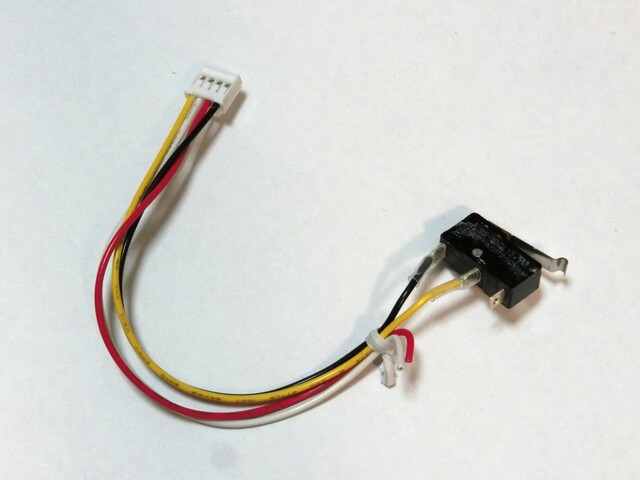
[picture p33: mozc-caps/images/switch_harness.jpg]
switch with wire harness


#### Step 3: Build

1. Put 2 rubber bands across the two latches on the sliding plates.
   \
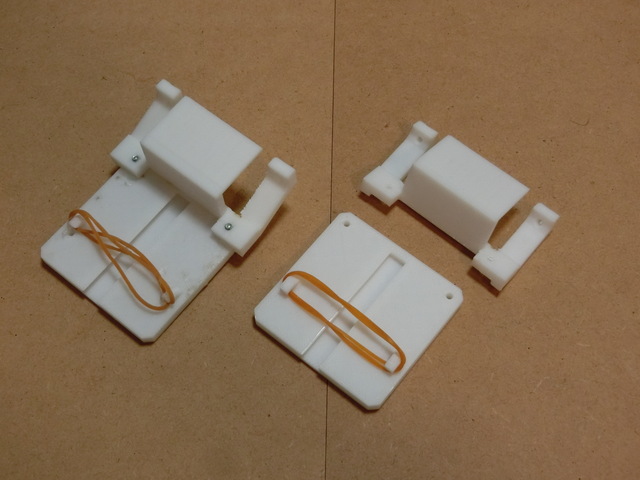
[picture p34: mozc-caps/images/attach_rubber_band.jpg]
   

1. Attach one of the top plate angle bracket mounts to one of the sliding plates
   and fasten using M3 screws. Repeat for the other set.
   \
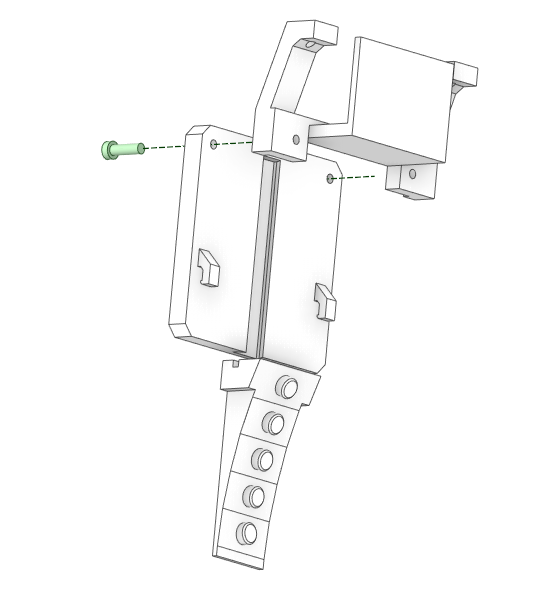
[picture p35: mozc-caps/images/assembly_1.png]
outer_rail to top_plate_holder
   

1. Fasten the angle bracket mount and sliding plate assemblies to the top plate
   using M3 screws \
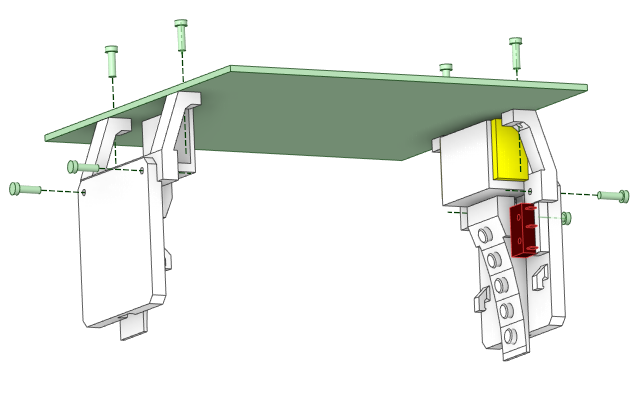
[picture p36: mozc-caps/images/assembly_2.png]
top_plate_holder to top_plate 1
   
   \
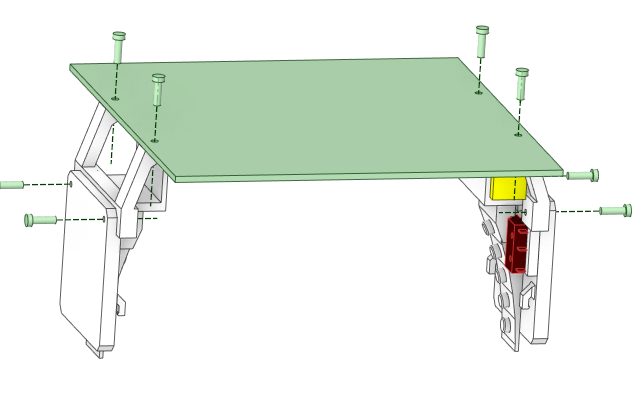
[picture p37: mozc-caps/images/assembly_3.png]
top_plate_holder to top_plate 2
   

1. Screw the micro switch to the switch mount.
   \
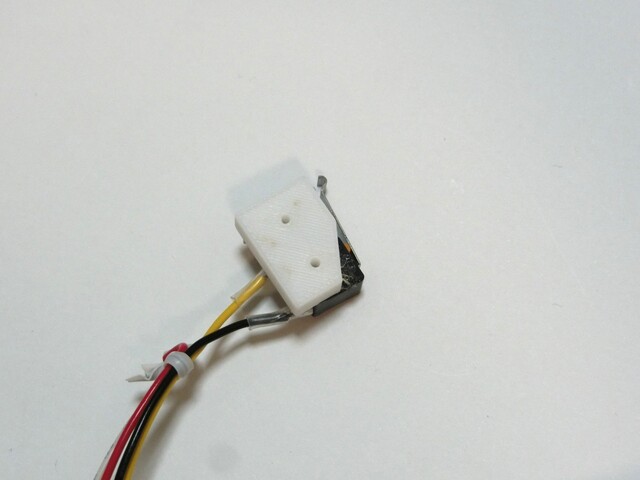
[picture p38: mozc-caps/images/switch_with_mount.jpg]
micro switch screwed on to a mount
   

1. Glue the switch mount to one of the sliding plates. Check that the switch can
   be pressed by testing using one of the bump cap insert mounts.
   \
   a

1. Attach the mounts to the left and right side of the cap, and adhere using hot
   glue. \
   a

1. Combine the two parts by attaching the sliding plates to the rails on the
   bump cap insert mounts.

1. Attach M5StickC Plus and connect the other side of the Grove connector that
   is attached to the micro switch.

### Firmware

#### Step 1: Environment setup

- Arduino IDE
- Libraries
  - [Madgwick library](https://github.com/arduino-libraries/MadgwickAHRS)
    - You can install from Arduino IDE's Library Manager.
  - [ESP32 BLE Keyboard library](https://github.com/T-vK/ESP32-BLE-Keyboard)
    - You can download zip file from github and install from Sketch -> Include
      Library -> Add .ZIP Library menu in Arduino IDE.
  - [IMU Library](https://github.com/yamaguchi-am/m5stack-examples)
    - Download
      [imu.h](https://github.com/yamaguchi-am/m5stack-examples/blob/main/imu/imu.h)
      and
      [imu.cpp](https://github.com/yamaguchi-am/m5stack-examples/blob/main/imu/imu.cpp)
      from this repository and put them into firmware/ directory.

#### Step 2: Compile and upload

- Compile and upload the mozc-caps.ino firmware to the M5StickC Plus using
  Arduino IDE.

#### Step 3: Calibration

- IMU (gyro sensor) calibration
  - After powering on the M5StickC Plus, the firmware will run calibration for
    the IMU.
  - While the display shows "calibrating" message, keep the device still.
  - You can also trigger the calibration process by long-pressing Button A.
- Setting the origin direction
  - When Button A is pressed, the origin direction is set to the current
    orientation of the device.

#### Step 4: Connect

Connect the keyboard via Bluetooth to a PC or other device that has Google
Japanese Input/Gboard installed.

Note: This keyboard keeps sending keycodes even before you press the key. It is
for showing a preview of the selected character to be input on the connected
device.

## License

```
Licensed under the Apache License, Version 2.0 (the "License"); you may
not use this file except in compliance with the License. You may obtain
a copy of the License at

    http://www.apache.org/licenses/LICENSE-2.0

Unless required by applicable law or agreed to in writing, software
distributed under the License is distributed on an "AS IS" BASIS,
WITHOUT WARRANTIES OR CONDITIONS OF ANY KIND, either express or implied.
See the License for the specific language governing permissions and
limitations under the License.
```

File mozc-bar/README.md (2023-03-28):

# Gboard Bar version

This directory contains programs, schematics and board layouts for Gboard Bar version,
which was released on **Oct 1, 2022**.

This is not an officially supported Google product.

Gboard Bar version

## Contents

The directory structure is as follows:

- board/ : KiCad schematics and PCB layouts.
- case/ : STL file for case.
- firmware/ : Arduino sketch.

## Building Gboard Bar Version

### Parts

- [Cherry MX (or compatible) key](https://shop.yushakobo.jp/collections/all-switches/cherry-mx-%E4%BA%92%E6%8F%9B-%E3%82%B9%E3%82%A4%E3%83%83%E3%83%81) x 101
- [Stabilizer](https://shop.yushakobo.jp/collections/all-keyboard-parts/products/a0500st?variant=37665699463329) 2u x 7
- [Stabilizer](https://shop.yushakobo.jp/collections/all-keyboard-parts/products/a0500st?variant=37665699463329) 6.25u x 1
- [74HC165](https://akizukidenshi.com/catalog/g/gI-14679/) x 16
- [Resistor 100kOhm](https://akizukidenshi.com/catalog/g/gR-25104/) x 16
- [Resistor network 100kOhm](https://akizukidenshi.com/catalog/g/gR-14228/) x 16
- [Capacitor 0.1uF](https://akizukidenshi.com/catalog/g/gP-10147/) x 16
- 2 row 3 column right angle 2.54mm pin headers x 16 ([Cut from this](https://akizukidenshi.com/catalog/g/gC-10903/))
- 2 row 3 column right angle 2.54mm pin header sockets x 16 ([Cut from this](https://akizukidenshi.com/catalog/g/gC-05756/))
- 20 mm width x 10 mm height extruded aluminium frame 2313.75mm in length (needed length may vary slightly based on 3D printing size variance)
- [M3 6mm slim head screw](https://jp.misumi-ec.com/vona2/detail/221000546066) x 16
- [M3 5mm Spacer](https://akizukidenshi.com/catalog/g/gP-07471/) x 16
- [M3 nut](https://akizukidenshi.com/catalog/g/gP-07468/) x 16
- Keycap (US) x 1set
- If building the wired version.
  - ProMicro x 1
  - Pin header 12pin x 2
- If building the wireless version.
  - M5StickC (or M5StickC PLUS) x 1
  - Right angle pin header 8pin x 1

#### Aluminium Frame

These for making frame:

- [HFSFIN5-1020](https://jp.misumi-ec.com/vona2/detail/110302374340/)
  - Multiple extruded aluminium frames can be connected together using [straight line connectors](https://jp.misumi-ec.com/vona2/detail/110302248430). For example, you may choose to order three 0.8m-ish frames instead of a single 2.4m frame.
  - However, the bottom holes of the cases cannot be used for fastening them to the frame. Additional machining would be needed. (e.g. dig some hole to the frame, or use glue instead, etc.)
- [AFS-1020-4](https://jp.misumi-ec.com/vona2/detail/221005476984/)
  - [NHG-04-3 square nuts](https://jp.misumi-ec.com/vona2/detail/221005480709/) and M3 flat-headed screws can be used for fastening each module to the frame.
  - However, parts for connecting these frames are not available. Purchasing a 2.4m-length frame may be problematic.
  - We have not actually tried this yet.

### PCBs

We need the following quantities of each kind of PCB:

PCBs

- Controller x 1
- Key switch Type A x 8
- Key switch Type B x 3
- Key switch Type C x 1
- Key switch Type D x 1
- Key switch Type E x 1
- Key switch Type F x 1
- Key switch Type G x 1

### Case

The following quantities of each type of 3D print case:

- case/left-tip.stl x 1
- case/typeA.stl x 8
- case/typeB.stl x 3
- case/typeC.stl x 1
- case/typeD.stl x 1
- case/typeE.stl x 1
- case/typeF.stl x 1
- case/typeG.stl x 1
- case/controller.stl x 1
- case/right-tip.stl x 1

### Steps to build

#### Step 1

Solder 74HC165, resistors, resistor networks, capacitors, connectors and keyswitches to keyswitch PCBs.

#### Step 2

Add stabilizer and keycaps.

Here is the default keymap:

keymap

#### Step 3

Solder pin header and/or pro micro to controller PCB.

Wired version (Use ProMicro):

promicro

Wireless version (Use M5StickC):

stickc before
stickc after

#### Step 4

Attach each PCB to 3D printed case using M3 bolt and spacer.

add spacer to PCB

attach PCB to case

#### Step 5

Thread the aluminium frame through the square holes of the 3D printed cases to join them together.

#### Step 6

Install firmware using the Arduino IDE.

NOTE: For the wireless version (M5Stack), an additional library is needed:
[ESP32 BLE Keyboard library](https://github.com/T-vK/ESP32-BLE-Keyboard)

#### Step 7

Connect the keyboard to a PC or other device that has Google Japanese
Input/Gboard installed.

## License

```
Licensed under the Apache License, Version 2.0 (the "License"); you may
not use this file except in compliance with the License. You may obtain
a copy of the License at

    http://www.apache.org/licenses/LICENSE-2.0

Unless required by applicable law or agreed to in writing, software
distributed under the License is distributed on an "AS IS" BASIS,
WITHOUT WARRANTIES OR CONDITIONS OF ANY KIND, either express or implied.
See the License for the specific language governing permissions and
limitations under the License.
```

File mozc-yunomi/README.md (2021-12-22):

# Gboard Yunomi version

This contains programs, schematics and board layouts for Gboard Yunomi version,
which was released on **Oct 1, 2021**.

This is not an officially supported Google product.

## Contents

The directory structure is as follows:

-   firmware/ : Arduino sketch.
-   board/ : KiCad schematics and PCB layouts.
-   jig.stl : A jig for building the keyboards.
-   ../third_party/mozc-yunomi/keyswitches.pretty : Footprint data for the key
    switches.

## Building Gboard Yunomi Version

device

**We also have the Pro Micro version of the device, which is easier to build. Please refer to [the Pro Micro README](./README_promicro.md) if you want to build one with Pro Micro.**

### Parts

-   Kailh choc key x60
-   Diode (1N4148) x60
-   ATMega32U4-AU (QFP)
-   Resistor 10kOhm
-   Resistor 22Ohm x2
-   Capacitor 0.1uF
-   Capacitor 1uF x2
-   Capacitor 22pF x2
-   Crystal 16MHz (HC-49)
-   USB-C connector breakout (4pin)

### PCBs

We need two types of PCBs to build this project.

pcbs

#### Key-PCB

key-pcb

File location: board/key

Shape: Rectangular.

Components: Diodes and key switches.

Number of PCBs required: 12

#### Base-PCB:

base-pcb

File location: board/base

Shape: Dodecagonal

Component2: ATMega32u4.

### Steps to build

#### Step 1

Solder diodes D1 to D5 onto the twelve Key-PCBs at the silk-screened locations.

*IMPORTANT:* Diodes on six of the Key-PCB should be placed in the opposite
direction.

For six of the PCBs, we can solder diodes as indicated by the silk-screen. For
the other six PCBs, we need to solder the diodes in the opposite direction.

#### Step 2

Solder key-switches to each Key-PCB. Note that the diodes need to be placed on
the opposite side of the Key-PCB to the key-switches, as shown by the
silk-screen.

#### Step 3

Create a cylindrical shape by combining the 12 Key-PCBs.

There are six connection points between each pair of Key-PCBs. Connect adjacent
pairs of boards by soldering the tin-plated wires (see the picture).

However, only connect J11 and J12 between the first and last Key-PCB, instead of
all six locations.

connect

connect2

connect3

If you have a 3D printer, you may print and use jig.stl to help with this step.

#### Step 4

Solder all parts for Base-PCB.

#### Step 5

Connect Base-PCB to the cylinder made in Step 3.

connect4

#### Step 6

Install the
[Arduino caterina bootloader](https://github.com/arduino/ArduinoCore-avr/blob/master/bootloaders/caterina/Caterina-Leonardo.hex)
using AVRISP or other ISP tool.

#### Step 7

Install firmware using the Arduino IDE.

#### Step 8

Connect the keyboard to a PC or other device that has Google Japanese
Input/Gboard installed.

## License

```
Licensed under the Apache License, Version 2.0 (the "License"); you may
not use this file except in compliance with the License. You may obtain
a copy of the License at

    http://www.apache.org/licenses/LICENSE-2.0

Unless required by applicable law or agreed to in writing, software
distributed under the License is distributed on an "AS IS" BASIS,
WITHOUT WARRANTIES OR CONDITIONS OF ANY KIND, either express or implied.
See the License for the specific language governing permissions and
limitations under the License.
```

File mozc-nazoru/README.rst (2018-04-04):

Gboard Physical Handwriting Version
===================================



Gboard Physical Handwriting Version is a device which translates your
scribble on your keyboard into a character. You can make your own Gboard
Physical Handwriting Version by printing your own printed circuit board
(PCB). Also, you can train your own model to recognize a customized set
of characters. This repository provides circuit diagram, the board
layout and software to recognize your stroke over the keyboard as a
character.

Software Usage
--------------

Install and Try
~~~~~~~~~~~~~~~~

Please make sure your local environemnt has packages as follows.

For Ubuntu/Debian:

.. code:: shell

  $ sudo apt install libffi-dev libcairo2 # For Ubuntu/Debian

For macOS:

.. code:: shell

  $ brew install cairo  # For macOS

After that, you can try nazoru-input after installing it from pip.

.. code:: shell

   $ pip install nazoru-input
   $ nazoru-input

Using ``nazoru-input``, You can make your own machine into an
input device which accepts scribbles on the connected keyboard and send
characters via bluetooth. At the beginning, this script scans
connected keyboards and starts listening to inputs from one of the
keyboards. Then it translates a sequence of keydowns into a predicted
character considering pressed timings, and send the character to the
target device paired by bluetooth.

If you want to try it for development, you can download the source from
github and use ``-e`` option.

.. code:: shell

   $ sudo apt install libffi-dev libcairo2 # For Ubuntu/Debian
   $ git clone https://github.com/google/mozc-devices.git
   $ cd mozc-devices/mozc-nazoru
   $ pip install -e .
   $ nazoru-input

Training Model
~~~~~~~~~~~~~~

.. code:: shell

   $ curl -LO https://github.com/google/mozc-devices/raw/master/mozc-nazoru/data/strokes.zip
   $ nazoru-training ./strokes.zip

We have a script to generate a trained model which recognizes input
characters from scribbles. This script renders input stroke data into
images to extract useful features for prediction considering position of
the key and timing of keyboard events. Rendered images are fed into the
neural network model and the optimizer tunes the model to fit the data.
Once the training is done, the script outputs the trained graph, which
you can use for your own device. In the case where you install
``nazoru-training`` from pip, you can find ``strokes.zip`` at here:
https://github.com/google/mozc-devices/blob/master/mozc-nazoru/data/strokes.zip

You can change some configurations by passing command line flags (e.g.
path to the input/output files, hyper-parameters). Run
``nazoru-training --help`` for details.

Hardware Setup
--------------

Printed Circuit Board
~~~~~~~~~~~~~~~~~~~~~
Gboard Physical Handwriting Version uses Raspberry Pi Zero for the
keyboard input recognition and RN42 module for Bluetooth connection to
your laptop. You can check the wiring at ``board/schematic.png``. Also,
the original CAD data in EAGLE format is available
(``board/nazoru-stack.sch`` and ``board/nazoru-stack.brd``). The board
has non-connected pads and connectors for SPI and I2C. The connector
itself should be compatible with other Raspberry Pi, but we tested it
only on Raspberry Pi Zero W.



Raspberry Pi Setup
~~~~~~~~~~~~~~~~~~

**Step 0 - Prepare your Raspberry Pi**

Please prepare your Raspberry Pi, SD card initialized by RASPBIAN
image, and RN42 module. Connect your Raspberry Pi with RN42 as the
schematic shows. Please make sure you can have access to the internet
and also it has enough disk space to install packages on the following
steps.

**Step 1 - Setup UART to RN42**

If you try it on Raspberry Pi Zero W or Raspberry Pi 3, you need to
have additional settings for the serial communication because they
equipped a wireless module connected by the UART. See details at `an
official document
<https://www.raspberrypi.org/documentation/configuration/uart.md>`_.
In short, you need to add ``enable_uart=1`` to ``/boot/config.txt`` on
your Raspberry Pi.

**Step 2 - Initial setup for RN42**

You need to write your initial setup to RN42. At first, install screen
and open ``/dev/serial0`` for configuration.

.. code:: shell

  $ sudo apt install screen
  $ sudo screen /dev/serial0 115200

After that, please type the following commands. Note that you need to
type ENTER after input commands. For example, please type ``$$$``
and ENTER to execute ``$$$`` command.

1. ``$$$`` : Get into the command mode. The green LED will blink
   faster.
2. ``+`` : You can see what you type.
3. ``SD,0540`` : Set the device class to keyboard.
4. ``S~,6`` : Set the profile to HID.
5. ``SH,0200`` : Set the HID flag to keyboard.
6. ``SN,nazoru-input`` : Set the device name as nazoru-input. You
   can name it as you want.
7. ``R,1`` : Reboot RN42.

You can quit the screen by ``C-a k``.

**Step 3 - Download and install nazoru-input**

We provide a service file at ``data/nazoru.service`` to launch
``nazoru-input`` when booting. You can install it by uncomment
``data_files`` entry in ``setup.py``. Also, before installing this
package, We'd strongly recommend you to install some  package from apt
repository as follows, so that you can install pre-built packages.

.. code:: shell

  $ sudo apt install git python-pip python-numpy python-cairocffi \
    python-h5py python-imaging python-scipy libblas-dev liblapack-dev \
    python-dev libatlas-base-dev gfortran python-setuptools \
    python-html5lib
  $ sudo pip install http://ci.tensorflow.org/view/Nightly/job/nightly-pi-zero/219/artifact/output-artifacts/tensorflow-1.6.0-cp27-none-any.whl
  $ git clone https://github.com/google/mozc-devices
  $ cd mozc-devices/mozc-nazoru
  $ vi setup.py  # Remove '#' for data_files to install nazoru.service.
  $ sudo pip install . # If you want to develop nazoru-input, please use 'sudo pip install -e .' instead.

**Step 4 - Enjoy!**

.. code:: shell

  $ sudo nazoru-input # If you miss sudo, nazoru-input may use a DummyBluetooth object.

Training Data Format
--------------------

We are providing the raw training data at ``data/strokes.zip``. Once you
uncompress the zip file, you will get a ``.ndjson`` file which contains
all entries (we call them **strokes**) we have used for training.

Each stroke entry contains the following field:

+----------+-----------+-------------------------------------------+
| Key      | Type      | Description                               |
+==========+===========+===========================================+
| id       | integer   | A unique identifier across all strokes.   |
+----------+-----------+-------------------------------------------+
| writer   | string    | A unique identifier of writer.            |
+----------+-----------+-------------------------------------------+
| kana     | string    | Label of the character drawn.             |
+----------+-----------+-------------------------------------------+
| events   | list      | List of keyboard events.                  |
+----------+-----------+-------------------------------------------+

Each event is a 3-tuple of (``key``, ``event type``, ``time``). ``key``
describes the key on which the event happened. ``event type`` describes
what type of event happened. It should be "down" (keydown) or "up"
(keyup). ``time`` describes the consumed time until the event is fired
in millisecond.

For example, the entry below denotes a stoke of "ほ
(\\u307b)" accompanied with a sequence of keyboard events
starting from the keydown event on "t" and ending at the keyup event on
"l" which was fired 1.005 seconds later after it started recording.

.. code:: json

    {
      "id": 5788999721418752,
      "writer": "ffb0dac6b8be3faa81da320e29a2ba72",
      "kana": "\u307b",
      "events": [
        ["t", "down", 0],
        ["g", "down", 40],
        ...
        ["l", "down", 966],
        ["l", "up", 1005]
      ]
    }

You can also prepare your own dataset in ``.ndjson`` format and rebuild
the model on it. The list of kanas to recognize is in
``src/nazoru/lib.py``. You can update that if you want to modify the set
of characters.

Network Structure
-----------------

Data Preprocessing
~~~~~~~~~~~~~~~~~~

Each stroke entry is rendered to a square image before any training
runs. The script (``nazoru-training``) renders strokes in various ways
to extract useful features. Our default settings extract 10 features
from each stroke entry: 8 directional features and 2 temporal features
on 16x16 square canvas; this means that the input shape is 16x16x10 by
default.

Convolutional Network
~~~~~~~~~~~~~~~~~~~~~

Rendered inputs are fed into a convolutional neural network designed for
this task. Body structure looks like:

-  Convolutional layer (kernel size: 3x3, filter size: 32, stride: 2,
   activation: Relu)
-  Separatable convolutional layer (kernel size: 3x3, filter size: 64,
   stride: 1, activation: Relu)
-  Separatable convolutional layer (kernel size: 3x3, filter size: 128,
   stride: 2, activation: Relu)
-  Separatable convolutional layer (kernel size: 3x3, filter size: 128,
   stride: 1, activation: Relu)

For more details about the separatable convolutional layers, please
refer to `MobileNet <https://arxiv.org/abs/1704.04861>`__ architecture.

Authors
-------

Machine Learning:
Shuhei Iitsuka <tushuhei@google.com>

Hardwares, system setups:
Makoto Shimazu <shimazu@google.com>

License
-------

Licensed under the Apache License, Version 2.0 (the "License"); you may
not use this file except in compliance with the License. You may obtain
a copy of the License at

    http://www.apache.org/licenses/LICENSE-2.0

Unless required by applicable law or agreed to in writing, software
distributed under the License is distributed on an "AS IS" BASIS,
WITHOUT WARRANTIES OR CONDITIONS OF ANY KIND, either express or implied.
See the License for the specific language governing permissions and
limitations under the License.

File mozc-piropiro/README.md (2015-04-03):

Copyright 2015 Google Inc.

Licensed under the Apache License, Version 2.0 (the "License");
you may not use this file except in compliance with the License.
You may obtain a copy of the License at

    http://www.apache.org/licenses/LICENSE-2.0

Unless required by applicable law or agreed to in writing, software
distributed under the License is distributed on an "AS IS" BASIS,
WITHOUT WARRANTIES OR CONDITIONS OF ANY KIND, either express or implied.
See the License for the specific language governing permissions and
limitations under the License.

 Summary
=====================================

Mechanical design, circuit diagram and firmware of Google Japanese Input
piropiro version.

 Files
=====================================

* arduino/piropiro/piropiro.ino -- firmware source code (Arduino sketch)
* stl/* -- 3D shape data of mechanical parts
* README.txt  -- this file
* assembly.png -- mechanical assembly instruction
* circuit.png -- circuit diagram
* example.jpg -- photograph of an example device

 Building your device
=====================================

## Mechanical parts

Output all mechanical parts under stl/ directory with a 3D printer.
Additionally, you need these parts.

* M2x4 scerws  x7
* M2 washer (inside diameter=2.2mm, outside diameter=5.8mm)  x1
* A party horn  x1

## Electronic parts

* Arduino Nano
    Some other models of Arduino (e.g. Arduino Uno) can be used
    if required function is available.
* RN-42-EK or a compatible evaluation kit
    RN-42 can be used instead if wired appropriately.
* GP2Y0E02A distance sensor
* 1/8W Resistors
    * 1k
    * 470
* Breadboard and jump wires

## Assembly

See the circuit diagram and mechanical assembly instruction images.

Also refer the example device in the photo.

## RN42 module configuration

This step is required for the first time, or when changing the device's name.
Note that you should not connect Arduino Nano when you configure RN-42-EK via
USB, because signal from Arduino Nano overrides the TxD signal on RN-42-EK.
See Microchip's documents for detail.

1. Connect RN-42-EK to your PC by USB.
2. Run a terminal emulator and open the serial port for RN-42-EK.
3. Type '$$$'. Make sure 'CMD' is returned from RN-42-EK and the green LED on
   RN-42-EK blinks fast.
4. Configure the module by these commands:

* * * * * *
    SU,115k
    SM,6
    SA,2
    S~,6
    SH,0000
    SN,MY_PIROPIRO_KEYBOARD
    R,1
* * * * * *
MY\_PIROPIRO\_KEYBOARD is a device name that will appear when you scan Bluetooth
devices, and can be replaced by your preferred name.

The commands will configure the module as follows:

* 115200bps
* Pairing mode
* SSP "just works" mode
* SPP profile
* HID flag register = 0 (keyboard)

 Using piropiro input
=====================================

## Power supply

When operating the device, supply power by USB cables to both RN-42-EK and
Arduino Nano. You can alternatively supply 3.3V power to RN-42-EK from Arduino's
3.3V pin, but this requires a modification on RN-42-EK to disconnect the
regulator's output pin on it from the circuit.

## Sensor adjustment

1. Attach the device to your party horn. The sensor should be positioned about
40mm apart from the rolled paper tube.
2. Turn on Arduino Nano and adjust the optical axis of the sensor. The LED on
Arduino board is lit while the sensor is collectly sensing the tip of the
paper tube between 50mm -- 350mm.

## Bluetooth pairing

Using your device (e.g. Android phone), scan Bluetooth devices and you will
find MY\_PIROPIRO\_KEYBOARD (or the name you set up) in the available device
list.

## How to input

Switch the Japanese IME on the paired device to romaji input mode.
Characters will be input as you blow the horn.
The length of the horn chooses the vowel.
In order to switch to the next column (consonant), quickly shrink the horn and blow it again.

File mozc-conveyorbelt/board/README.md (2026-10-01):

# Board Assembly Guide

Coming soon.

PCB

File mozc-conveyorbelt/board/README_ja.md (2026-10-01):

# 基板組立ガイド

今後公開予定。

PCB

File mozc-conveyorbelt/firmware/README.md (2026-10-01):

# Firmware Development Guide

For the entire keyboard assembly, please refer to the
[Build Guide](../buildguide.md).

## File List

-   `prebuilt/` : Pre-built firmware
-   `keymap.h` : Keymap definitions
-   `main.c` : Source file for the main chip
-   `makefile` : Build configuration
-   `switches.h` / `switches.c` : Source files for key switch and shift register
    control
-   `chlib/` : Common library (automatically fetched during build)

## Pre-built Firmware

Pre-built firmware (`mozc.bin`) is located under `prebuilt/`, so you can use it
directly if no modifications are needed.

Press and hold `SW4` (BOOT switch) on the board while connecting the USB cable
to enter bootloader mode, and flash using
[ch559flasher](https://github.com/toyoshim/ch559flasher):

```sh
ch559flasher -w prebuilt/mozc.bin
ch559flasher -b
```

If flashing does not work (e.g. device is not recognized, USB driver setup is
required) or installing the tool is difficult, please flash using the official
WCH development tool
([WCHISPTool](http://www.wch.cn/downloads/WCHISPTool_Setup_exe.html)).

## Guide to Developing Your Own Firmware

### Build Environment Setup

Firmware is compiled with [SDCC](https://sdcc.sourceforge.net/) and flashed with
[ch559flasher](https://github.com/toyoshim/ch559flasher).

-   **Debian / Ubuntu**:

    ```sh
    sudo apt install sdcc binutils
    ```
-   **Windows**:

    ```powershell
    winget install sdcc
    ```

Manual installation of ch559flasher (requires Rust / Cargo):

```sh
cargo install --git https://github.com/toyoshim/ch559flasher.git
```

*   If not installed, `make program` will also attempt to fetch it
    automatically.

### Build and Flash

Running `make` automatically clones the required library (`chlib`) and builds
the firmware. If `ch559flasher` is not installed, running `make program` will
attempt to fetch it automatically.

```sh
# Build
make

# Flash (execute while USB is connected with SW4 held down)
make program

# Flash and run
make run
```

### Standard Output

Debug output is emitted from UART0 (TXD: P0.3) of the CH559L at 115200bps. You
can inspect logs by connecting a serial converter to the `TXD` land on the
board.

### Customizing the Keymap

To modify the key layout, edit the `keymap` array in `keymap.h`. Each key entry
is assigned a HID Usage ID and a Shift flag.

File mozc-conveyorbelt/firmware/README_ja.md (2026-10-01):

# ファームウェア開発ガイド

キーボードの組み立て全体については[ビルドガイド](../buildguide_ja.md)を参照してください。

## ファイル一覧

-   `prebuilt/` : 事前にビルドしたファームウェア
-   `keymap.h` : キーマップ定義
-   `main.c` : メインチップ用のソースファイル
-   `makefile` : ビルド設定
-   `switches.h` / `switches.c` : キースイッチおよびシフトレジスタ制御用ソースファイル
-   `chlib/` : 共通ライブラリ（ビルド時に自動取得）

## 事前にビルドしたファームウェア

`prebuilt/` 以下に事前にビルドしたファームウェア（`mozc.bin`）を収めていますので、変更が不要の場合はこれをそのまま用いることができます。

基板上の `SW4`（BOOT スイッチ）を押しながら USB
ケーブルを接続してブートローダーモードに入り、[ch559flasher](https://github.com/toyoshim/ch559flasher)
を用いて書き込みます。

```sh
ch559flasher -w prebuilt/mozc.bin
ch559flasher -b
```

書き込みがうまくいかない場合（デバイスが認識されない、USB ドライバの設定が必要な場合など）やツールの導入が難しい場合は、WCH
公式の開発ツール（[WCHISPTool](http://www.wch.cn/downloads/WCHISPTool_Setup_exe.html)）を使用して書き込んでください。

## 独自のファームウェア開発の手引き

### ビルド環境の準備

ファームウェアのコンパイルには [SDCC](https://sdcc.sourceforge.net/) を、書き込みには
[ch559flasher](https://github.com/toyoshim/ch559flasher) を使用します。

-   **Debian / Ubuntu**:

    ```sh
    sudo apt install sdcc binutils
    ```
-   **Windows**:

    ```powershell
    winget install sdcc
    ```

ch559flasher の手動インストール（要 Rust / Cargo）：

```sh
cargo install --git https://github.com/toyoshim/ch559flasher.git
```

※ 未インストールの場合は `make program` 実行時にも自動取得を試みます。

### ビルドと書き込み

`make` を実行すると、必要なライブラリ（`chlib`）が自動的にクローンされ、ビルドが行われます。`ch559flasher` が未インストールの場合は
`make program` 実行時に自動取得を試みます。

```sh
# ビルド
make

# 書き込み（SW4 を押しながら USB を接続した状態で実行）
make program

# 書き込みと実行
make run
```

### 標準出力について

CH559L の UART0（TXD: P0.3）から、速度 115200bps でデバッグ用の標準出力が出力されています。基板上の `TXD`
ランドにシリアル変換器を接続することでログを確認できます。

### キーマップの変更について

キーマップを変更したい場合は、`keymap.h` 内の `keymap` 配列を編集してください。各キーには HID Usage ID と Shift
フラグが割り当てられています。

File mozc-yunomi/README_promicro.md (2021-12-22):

# Gboard Yunomi version with Pro Micro

This is an instruction to build the Gboard Yunomi version with Pro Micro.
For the general information about the Gboard Yunomi version, please refer to [the project README](./README.md).

### Parts

-   Kailh choc key x60
-   Diode (1N4148) x60
-   Pro Micro x1

### PCBs

We need two types of PCBs to build this project.

pcbs

#### Key-PCB

key-pcb

File location: board/key

Shape: Rectangular

Components to be soldered: Diodes and key switches

Number of PCBs required: 12

#### Base-PCB:

base-pcb

File location: board/base-promicro

Shape: Dodecagonal

Components to be soldered: Pro Micro

Number of PCBs required: 1

### Steps to build

#### Step 1

Solder diodes D1 to D5 onto the twelve Key-PCBs at the silk-screened locations.

*IMPORTANT:* Diodes on six of the Key-PCBs should be placed in the opposite
direction.

In other words, you can solder diodes as indicated by the silk-screen for six of them, and you need to solder diodes in the opposite direction for the rest six.

#### Step 2

Solder key-switches to each Key-PCB. Note that the diodes need to be placed on
the opposite side of the Key-PCB to the key-switches, as shown by the
silk-screen.

#### Step 3

Create a cylindrical shape by combining the 12 Key-PCBs.

There are six connection points between each pair of Key-PCBs. Connect adjacent
pairs of boards by soldering the tin-plated wires (see the picture).

However, only connect J11 and J12 between the first and last Key-PCB, instead of
all six locations.

connect

connect2

connect3

If you have a 3D printer, you may print and use jig.stl to help with this step.

#### Step 4

Solder a Pro Micro to the Base-PCB.

#### Step 5

Connect Base-PCB to the cylinder made in Step 3.

connect4

#### Step 6

Install [firmware](./firmware/firmware.ino) using the Arduino IDE. Note that you need to uncomment the line 2 (`#define PRO_MICRO`) to make it work with the Pro Micro version.

#### Step 7 (Optional)

Print and mount the platform (./platform_promicro.stl).

platform

#### Step 8

Connect the keyboard to a PC or other device that has Google Japanese
Input/Gboard installed. Enjoy!

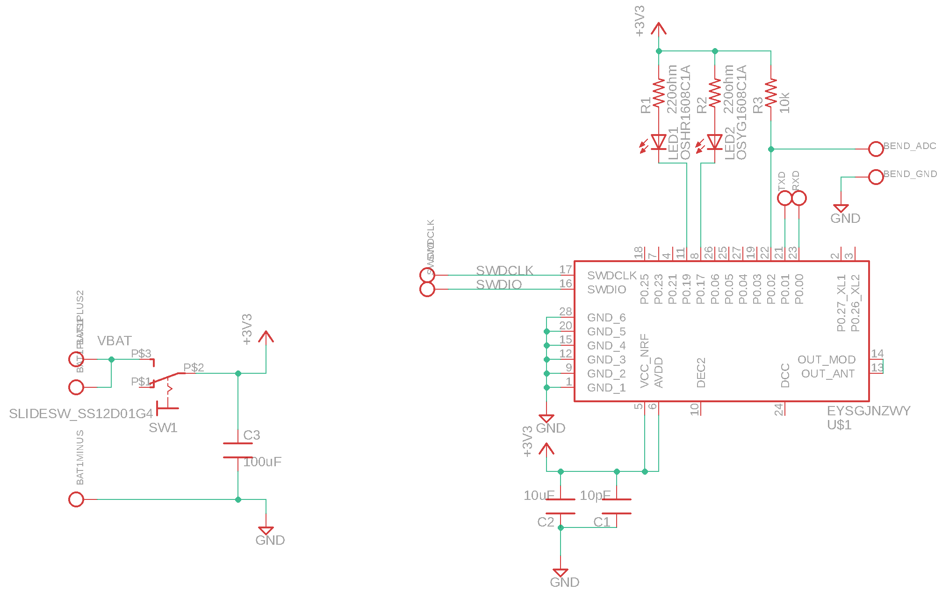
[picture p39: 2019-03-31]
mozc-mageru/wireless/board/schematic.png

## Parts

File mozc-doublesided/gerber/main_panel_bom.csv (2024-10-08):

Designator | Footprint | Quantity | Value | LCSC Part #
C1_9, C1_8, C1_7, C1_6, C1_5, C1_4, C1_3, C1_2, C1 | 0402 | 9 | 0.1u
CUT1_9, CUT1_8, CUT1_7, CUT1_6, CUT1_5, CUT1_4, CUT1_3, CUT1_2, CUT1, CUT2_9, CUT2_8, CUT2_7, CUT2_6, CUT2_5, CUT2_4, CUT2_3, CUT2_2, CUT2 | CUT | 18 | CUT
D1_9, D1_8, D1_7, D1_6, D1_5, D1_4, D1_3, D1_2, D1, D2_9, D2_8, D2_7, D2_6, D2_5, D2_4, D2_3, D2_2, D2, D3_9, D3_8, D3_7, D3_6, D3_5, D3_4, D3_3, D3_2, D3, D4_9, D4_8, D4_7, D4_6, D4_5, D4_4, D4_3, D4_2, D4 | SK6812MINIe (Reverse) | 36 | SK6812MINIe | C5149201
D5_9, D5_8, D5_7, D5_6, D5_5, D5_4, D5_3, D5_2, D5, D6_9, D6_8, D6_7, D6_6, D6_5, D6_4, D6_3, D6_2, D6, D7_9, D7_8, D7_7, D7_6, D7_5, D7_4, D7_3, D7_2, D7, D8_9, D8_8, D8_7, D8_6, D8_5, D8_4, D8_3, D8_2, D8 | 0805 | 36 | D | C109001
J2_9, J2_8, J2_7, J2_6, J2_5, J2_4, J2_3, J2_2, J2 | JST_S8B_ZR | 9 | Conn_Upstream | C2845571
J3_9, J3_8, J3_7, J3_6, J3_5, J3_4, J3_3, J3_2, J3 | JST_S8B_ZR | 9 | Conn_Downstream | C2845571
R1_9, R1_8, R1_7, R1_6, R1_5, R1_4, R1_3, R1_2, R1, R2_9, R2_8, R2_7, R2_6, R2_5, R2_4, R2_3, R2_2, R2 | 0402 | 18 | 510
SW1_9, SW1_8, SW1_7, SW1_6, SW1_5, SW1_4, SW1_3, SW1_2, SW1, SW2_9, SW2_8, SW2_7, SW2_6, SW2_5, SW2_4, SW2_3, SW2_2, SW2, SW3_9, SW3_8, SW3_7, SW3_6, SW3_5, SW3_4, SW3_3, SW3_2, SW3, SW4_9, SW4_8, SW4_7, SW4_6, SW4_5, SW4_4, SW4_3, SW4_2, SW4 | Keyswitch | 36 | SW_Push | C5184526
U1_9, U1_8, U1_7, U1_6, U1_5, U1_4, U1_3, U1_2, U1 | TSSOP-20_4.4x6.5mm_P0.65mm | 9 | STM32F042F4Px | C81002

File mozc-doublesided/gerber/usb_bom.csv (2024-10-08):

Designator | Footprint | Quantity | Value | LCSC Part #
C1 | 0402 | 1 | 10u
C2 | 0402 | 1 | 2.2u
C3, C4 | 0402 | 2 | 47p
J1 | JST_S7B_ZR | 1 | JST_ZH_7P | C160734
J2 | USB_C_Receptacle_XKB_U262-16XN-4BVC11 | 1 | USB
R1, R2 | 0402 | 2 | 5.1K
R3, R4 | 0402 | 2 | 22
R5 | 0402 | 1 | 1.5K
U1 | SOT-223-3_TabPin2 | 1 | AMS1117-3.3 | C347222

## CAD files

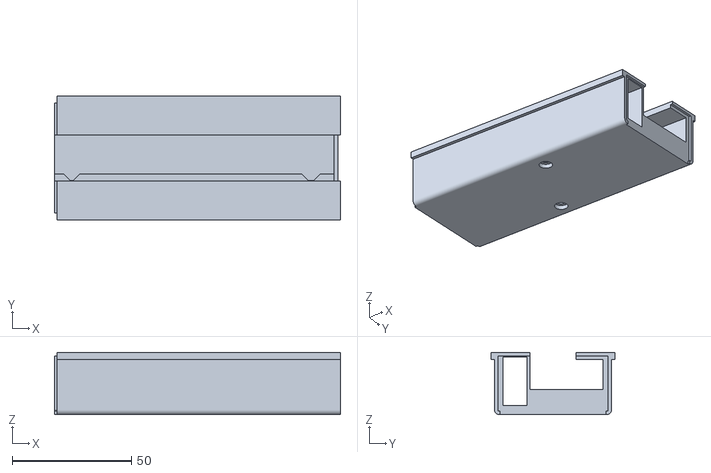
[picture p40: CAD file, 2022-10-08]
mozc-bar/case/typeD.stl
119.8 x 52.0 x 26.0

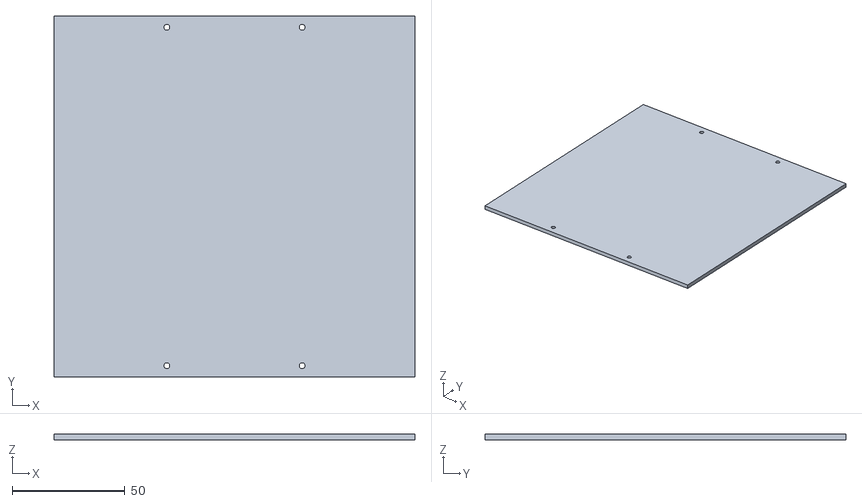
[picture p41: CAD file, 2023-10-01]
mozc-caps/hardware/top_plate.stl
160.0 x 160.0 x 2.50

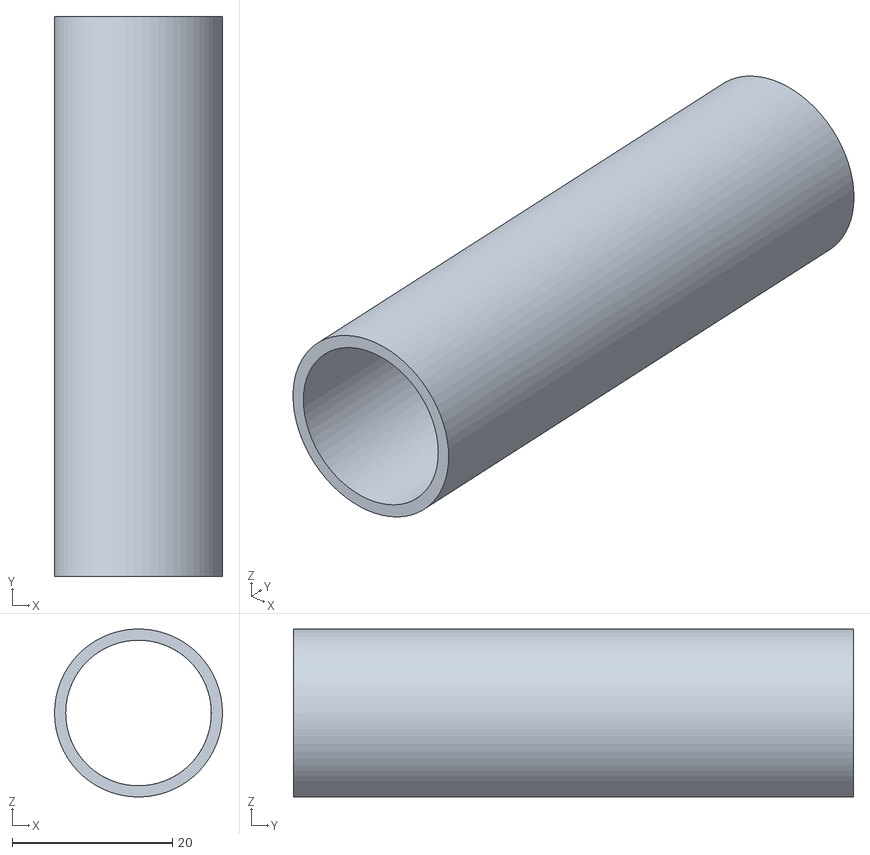
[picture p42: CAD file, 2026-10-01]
mozc-conveyorbelt/stls/BottomTube.stl
21.0 x 70.0 x 21.0

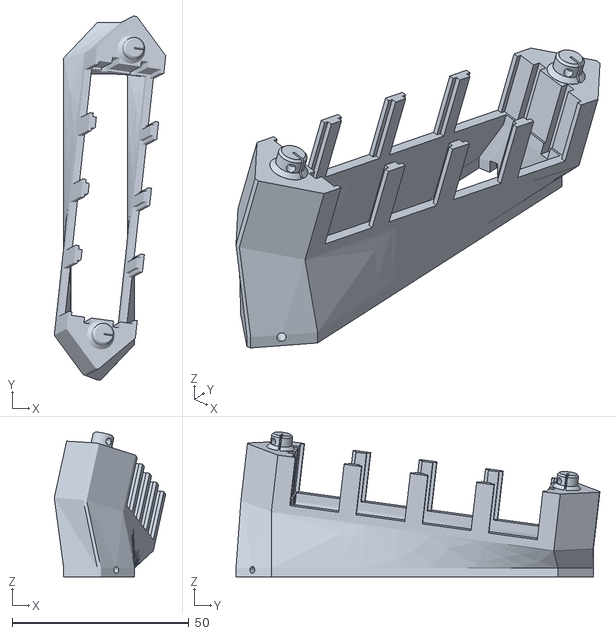
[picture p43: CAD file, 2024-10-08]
mozc-doublesided/case/case18.stl
31.5 x 102.8 x 41.0

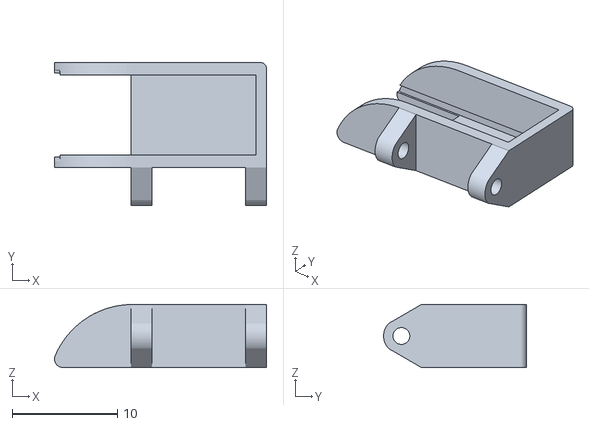
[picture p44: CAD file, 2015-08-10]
mozc-piropiro/stl/sensor_bracket.stl
20.2 x 13.6 x 6.00

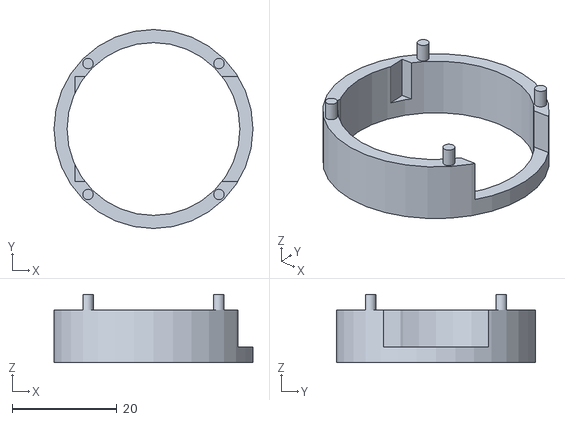
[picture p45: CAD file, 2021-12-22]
mozc-yunomi/platform_promicro.stl
38.0 x 38.0 x 13.0

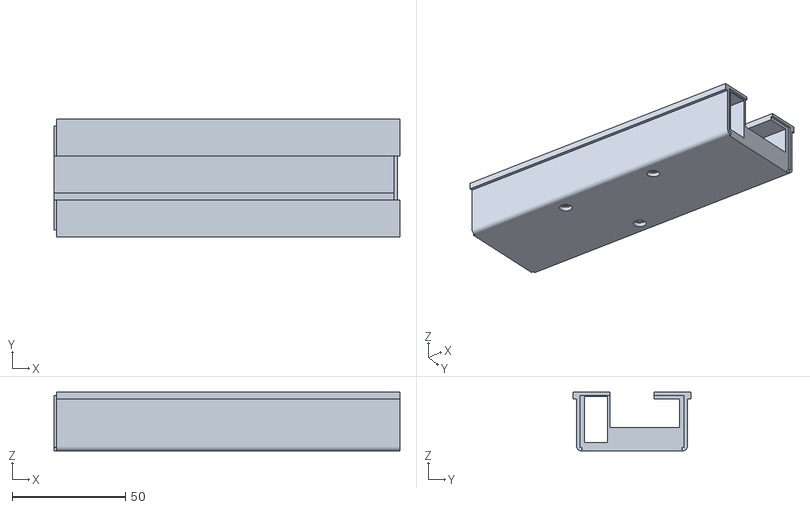
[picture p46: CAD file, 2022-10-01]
mozc-bar/case/typeA.stl
153.0 x 52.0 x 26.0

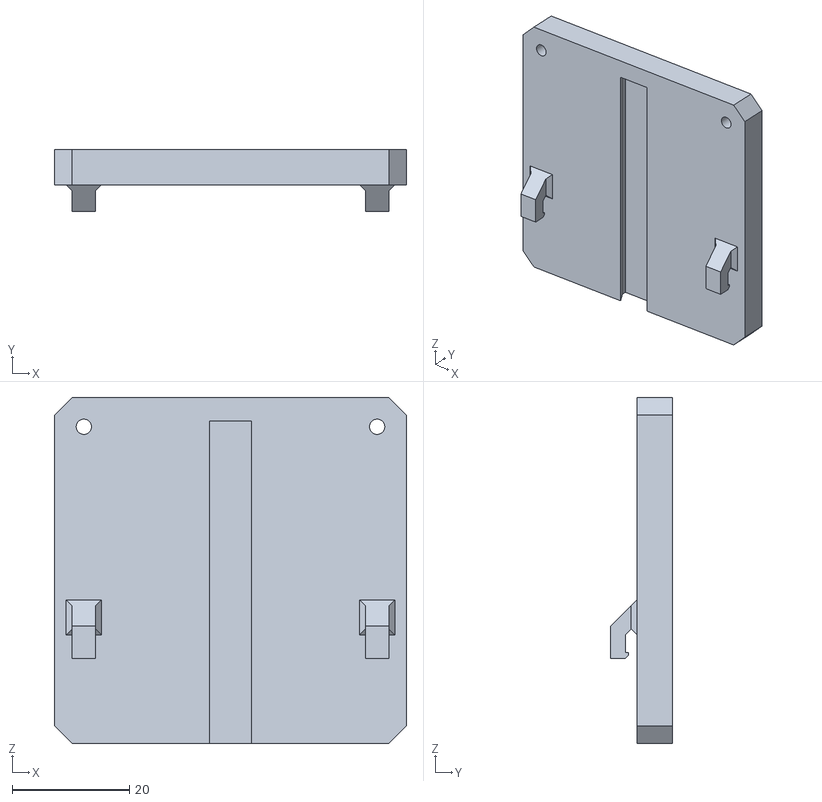
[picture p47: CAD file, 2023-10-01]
mozc-caps/hardware/sliding_plate.stl
60.0 x 10.5 x 59.0

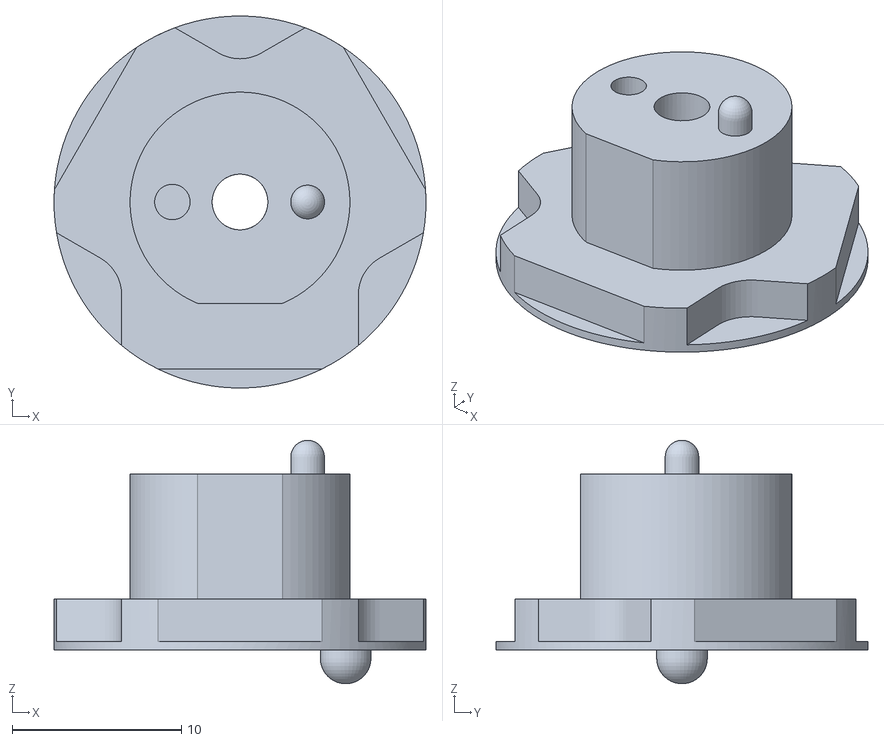
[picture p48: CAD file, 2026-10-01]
mozc-conveyorbelt/stls/SprocketB.stl
22.0 x 22.0 x 14.4

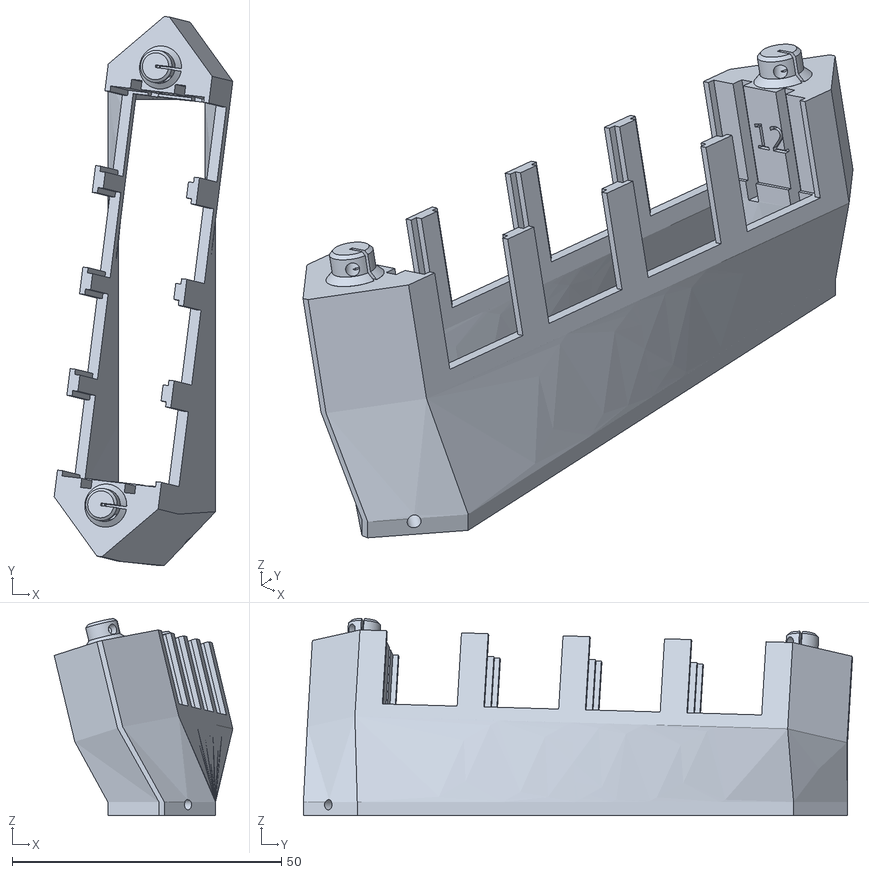
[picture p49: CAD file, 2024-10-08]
mozc-doublesided/case/case12.stl
33.2 x 102.0 x 36.6

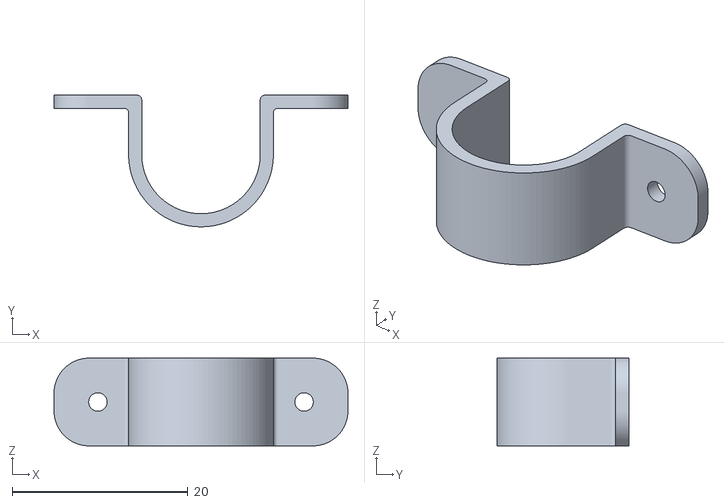
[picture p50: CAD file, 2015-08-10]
mozc-piropiro/stl/holder2.stl
33.5 x 15.0 x 10.0

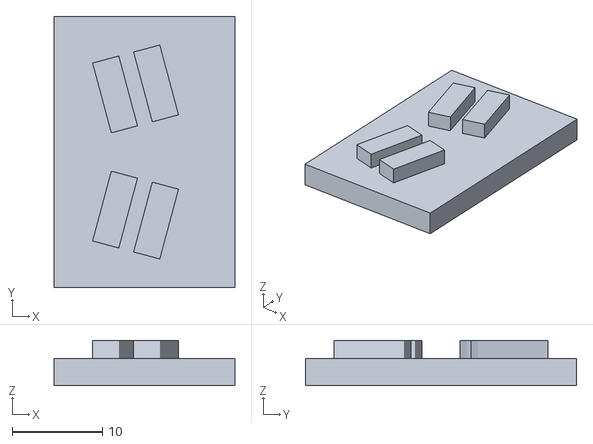
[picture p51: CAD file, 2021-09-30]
mozc-yunomi/jig.stl
20.0 x 30.0 x 5.00

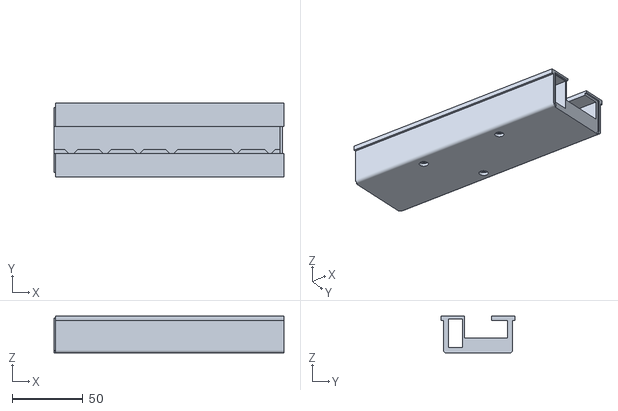
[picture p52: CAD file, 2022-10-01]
mozc-bar/case/typeF.stl
162.5 x 52.0 x 26.0

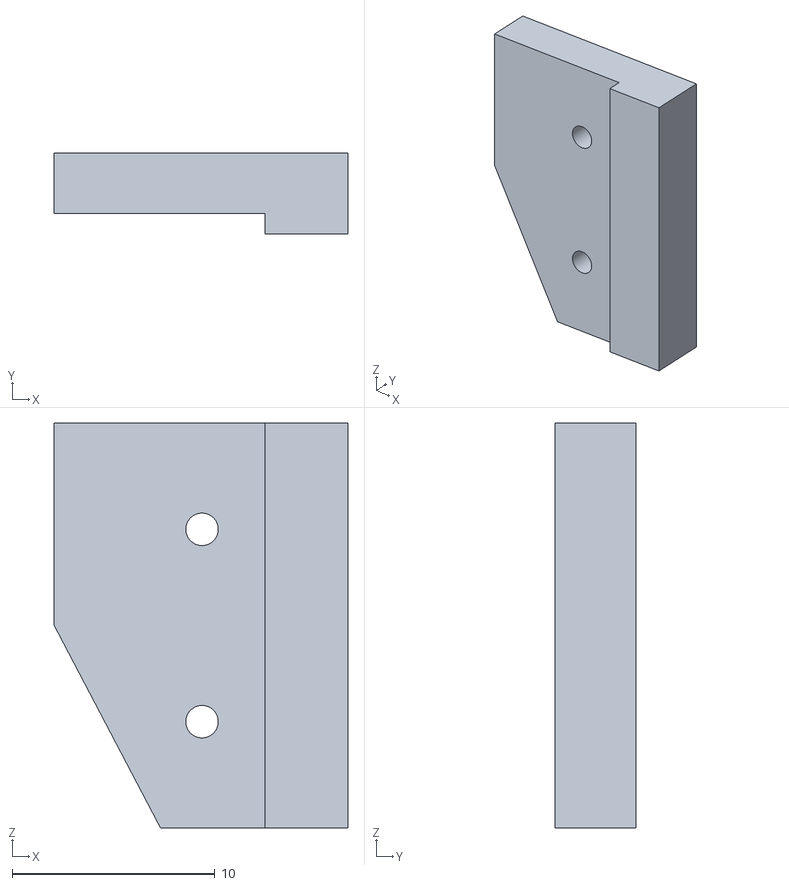
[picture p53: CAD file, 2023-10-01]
mozc-caps/hardware/switch_mount.stl
14.5 x 4.00 x 20.0

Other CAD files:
mozc-conveyorbelt/stls/BaseCoverR.stl
mozc-doublesided/case/case15.stl
mozc-piropiro/stl/arm.stl
mozc-bar/case/typeE.stl
mozc-bar/case/controller.stl
mozc-bar/case/left-tip.stl
mozc-bar/case/right-tip.stl
mozc-bar/case/typeB.stl
mozc-bar/case/typeC.stl
mozc-bar/case/typeG.stl
mozc-caps/hardware/bump_cap_insert_mount.stl
mozc-caps/hardware/top_plate_angle_bracket_mount.stl
mozc-conveyorbelt/stls/BaseCoverL.stl
mozc-conveyorbelt/stls/Base_Roller.stl
mozc-conveyorbelt/stls/Base_Side.stl
mozc-conveyorbelt/stls/Belt.stl
mozc-conveyorbelt/stls/BottomTubePlate.stl
mozc-conveyorbelt/stls/Box.stl
mozc-conveyorbelt/stls/Cover_BottomL.stl
mozc-conveyorbelt/stls/Cover_Top.stl
mozc-conveyorbelt/stls/Cover_wAtom.stl
mozc-conveyorbelt/stls/MotorSupport.stl
mozc-conveyorbelt/stls/SidePlate_Bottom.stl
mozc-conveyorbelt/stls/SidePlate_Top.stl
mozc-conveyorbelt/stls/SprocketA.stl
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

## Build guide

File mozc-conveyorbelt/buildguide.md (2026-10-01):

# Build Guide

Gboard DIY

[Overview of the project](./README.md)

## File List

- `stls/` : 3D model files (STL) for the case and mechanisms
- [`board/`](./board/README.md) : Documentation for electronics and wiring (Coming soon)
- [`firmware/`](./firmware/README.md) : Firmware development resources
- `firmware/prebuilt/` : Pre-built firmware binaries

## Editions

There are two editions of this keyboard:
- **Moving Keys Edition**: A motorized conveyor belt edition where the keys physically circulate.
- **Bluetooth Connection Edition**: A functional Bluetooth keyboard edition (Coming soon).

The instructions below describe how to build the **Moving Keys Edition**.

## Moving Keys Edition

### Bill of Materials (BOM)

#### 3D Printed Parts

| Preview | Part Name | File | Qty | Notes |
| :-: | :--- | :--- | :-: | :--- |
| Base_Roller | Base_Roller | [`Base_Roller.stl`](./stls/Base_Roller.stl) | 2 | Base roller |
| Base_Side | Base_Side | [`Base_Side.stl`](./stls/Base_Side.stl) | 2 | Base side frame (L/R) |
| BaseCoverL | BaseCoverL | [`BaseCoverL.stl`](./stls/BaseCoverL.stl) | 1 | Base left cover |
| BaseCoverR | BaseCoverR | [`BaseCoverR.stl`](./stls/BaseCoverR.stl) | 1 | Base right cover |
| BottomTube | BottomTube | [`BottomTube.stl`](./stls/BottomTube.stl) | 3 | OD 21mm / ID 18mm / L 70mm pipe can also be used |
| BottomTubePlate | BottomTubePlate | [`BottomTubePlate.stl`](./stls/BottomTubePlate.stl) | 1 | Bottom tube support plate |
| Box | Box | [`Box.stl`](./stls/Box.stl) | 1 | Main enclosure box |
| Cover_BottomL | Cover_BottomL | [`Cover_BottomL.stl`](./stls/Cover_BottomL.stl) | 1 | Lower left cover |
| Cover_Top | Cover_Top | [`Cover_Top.stl`](./stls/Cover_Top.stl) | 2 | Upper side cover (common for L/R) |
| Cover_wAtom | Cover_wAtom | [`Cover_wAtom.stl`](./stls/Cover_wAtom.stl) | 1 | Lower side cover with slot for ATOMS3 Lite |
| MotorSupport | MotorSupport | [`MotorSupport.stl`](./stls/MotorSupport.stl) | 1 | Motor and driver support bracket |
| SidePlate_Bottom | SidePlate_Bottom | [`SidePlate_Bottom.stl`](./stls/SidePlate_Bottom.stl) | 2 | Lower inner side plate |
| SidePlate_Top | SidePlate_Top | [`SidePlate_Top.stl`](./stls/SidePlate_Top.stl) | 2 | Upper inner side plate |
| SprocketA | SprocketA | [`SprocketA.stl`](./stls/SprocketA.stl) | 4 | Sprocket A (protrusions on one side only) |
| SprocketB | SprocketB | [`SprocketB.stl`](./stls/SprocketB.stl) | 6 | Sprocket B (protrusions on both sides at the same angle) |
| SprocketC | SprocketC | [`SprocketC.stl`](./stls/SprocketC.stl) | 6 | Sprocket C (protrusions on both sides at offset angles) |
| Stay | Stay | [`Stay.stl`](./stls/Stay.stl) | 2 | t2mm 12×110mm |
| Belt | Belt | [`Belt.stl`](./stls/Belt.stl) | 116 | Conveyor belt link (29 pcs × 4 columns) |

#### Mechanical Parts & Fasteners

| Part Name | Qty | Notes / Reference Links |
| :--- | :-: | :--- |
| 3mm L105mm Shaft | 2 | [Reference](https://www.amazon.co.jp/dp/B0DS8YLN65) (Cut to 105mm) |
| Insert Nut M4 x 4mm x 5mm | 14 | [Reference 1](https://www.amazon.co.jp/dp/B0DJ8C9PJN) / [Reference 2](https://www.amazon.co.jp/dp/B0FFGZKGJC) |
| Insert Nut M2.5 x 3.5mm x 3.5mm | 8 | [Reference](https://www.amazon.co.jp/dp/B0FVD9XB56) |
| Hex Socket Set Screw M2.5 x 4mm | 4 | [Reference](https://www.amazon.co.jp/dp/B0F4Q98MY7) |
| Hex Socket Head Cap Screw M4 x 8mm | 12 | [Reference](https://www.amazon.co.jp/dp/B0DDWLZYRK) |
| Hex Socket Head Cap Screw M4 x 6mm | 2 | [Reference](https://www.amazon.co.jp/dp/B002A5KK76) |
| Hex Socket Head Cap Screw M2.5 x 8mm | 4 | [Reference](https://www.amazon.co.jp/dp/B0FLYCZ4R2) |
| Timing Pulley 2GT (6mm belt width, 20T, 3mm bore) | 2 | [Reference](https://www.amazon.co.jp/dp/B09Y1N3WXT) |
| Timing Belt 2GT (6mm width, 110mm length) | 1 | [Reference](https://www.amazon.co.jp/dp/B0CNT721G6) |
| Bearing 623ZZ (ID 3mm, OD 10mm, W 4mm) | 4 | [Reference](https://www.amazon.co.jp/dp/B0G6ZG3Z8F) |
| Bearing MR63ZZ (ID 3mm, OD 6mm, W 2.5mm) | 1 | [Reference](https://www.amazon.co.jp/dp/B0CFZQRL8C) |
| 3mm Shaft Collar (OD 8mm, W 4mm) | 3 | [Reference](https://www.amazon.co.jp/dp/B0CQNYN2N6) |

#### Electronic Parts

| Part Name | Qty | Notes / Reference Links |
| :--- | :-: | :--- |
| Motor Driver DRV8833 | 1 | [Reference](https://www.amazon.co.jp/dp/B098Q24ZV9) |
| DC6V N20 Metal Gear Motor (3mm shaft, 150RPM) | 1 | [Reference](https://www.amazon.co.jp/dp/B0FZFKGC6F) |
| ATOMS3 Lite | 1 | [Reference](https://www.switch-science.com/products/8778) |
| 2.54mm Pin Header 4P | 1 | [Reference](https://www.amazon.co.jp/dp/B0829W3T8Q) |
| 2.54mm Pin Header 5P | 1 | |
| 220μF Electrolytic Capacitor | 1 | [Reference](https://www.amazon.co.jp/dp/B07D3P2NFY) |
| 0.1μF Ceramic Capacitor | 1 | [Reference](https://www.amazon.co.jp/dp/B079YJ78VS) |
| Kailh Low Profile Switch (Choc V1) | 116 | [Reference](https://shop.yushakobo.jp/collections/all-switches/products/pg1350) |
| Kailh Low Profile Keycap (Choc V1) | 116 | [Reference](https://shop.yushakobo.jp/collections/choc-v1-keycaps/products/pg1350cap-blank) |

### Assembly

#### Step 1: Prepare 3D-Printed Parts and Install Insert Nuts

1. Print all 18 types of 3D-printed parts (157 pieces in total) listed in the BOM above. Note that `BottomTube` (3 pcs) can also be substituted with an off-the-shelf pipe (OD 21mm, ID 18mm, length 70mm).
2. Using a soldering iron, press the M4 heat-set insert nuts (14 pcs) into `Base_Side` (1 pc × 2), `Base_Roller` (2 pcs × 2), and `Box` (4 pcs × 2).

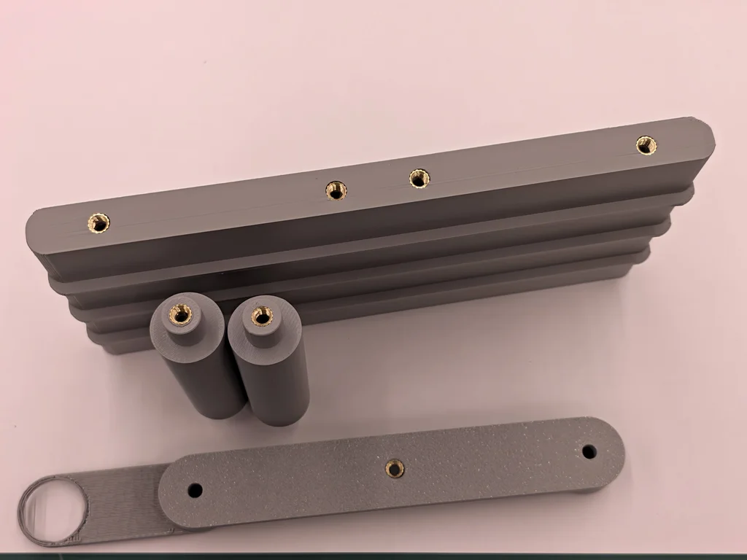
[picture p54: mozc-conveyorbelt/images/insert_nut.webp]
M4 Insert Nuts


3. Press the M2.5 heat-set insert nuts (8 pcs) into `MotorSupport` (2 pcs), `BottomTubePlate` (2 pcs), and the side of the boss on `SprocketA` (1 pc × 4).

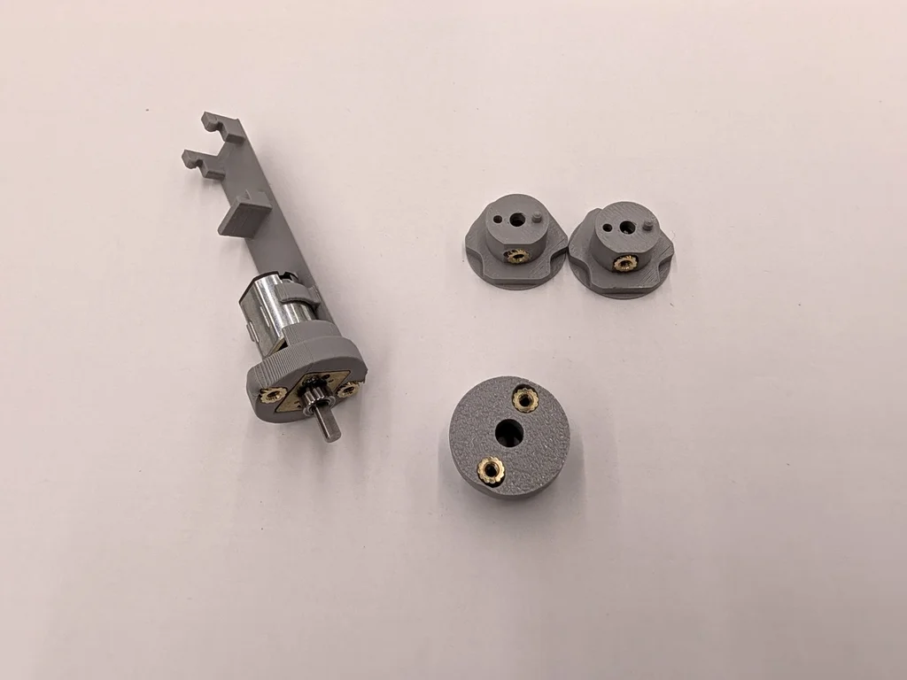
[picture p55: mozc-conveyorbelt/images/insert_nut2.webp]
M2.5 Insert Nuts


#### Step 2: Assemble the Base

1. Attach the DC6V N20 metal gear motor (150RPM) and the `DRV8833` motor driver module to `MotorSupport`.
2. Assemble the base section by combining `BottomTube` (3 pcs), `Base_Roller` (2 pcs), `Base_Side` (2 pcs), `BottomTubePlate` (1 pc), and `MotorSupport` (1 pc), and secure them with M4 hex socket head cap screws. Route the power cable through the hole in `BottomTubePlate` and inside `BottomTube`.

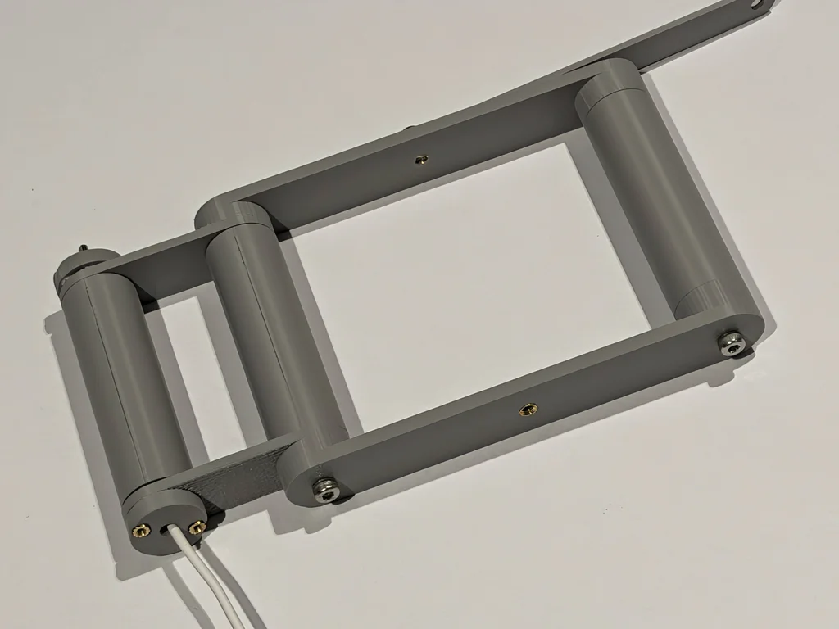
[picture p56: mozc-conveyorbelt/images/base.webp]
Base Assembly


#### Step 3: Assemble Shafts and Sprockets

1. Onto each of the two 3mm shafts (105mm length), slide the sprockets in the order **`SprocketA`, `SprocketB`, `SprocketC`, `SprocketB`, `SprocketC`, `SprocketB`, `SprocketC`, `SprocketA`** (8 sprockets per shaft, 16 in total), and slide `623ZZ` bearings onto both ends of each shaft (4 pcs in total). Secure both ends of one shaft and one end of the other shaft using the 3mm shaft collars (3 pcs in total).
2. Secure `SprocketA` to the shafts using the M2.5 × 4mm hex socket set screws (4 pcs).

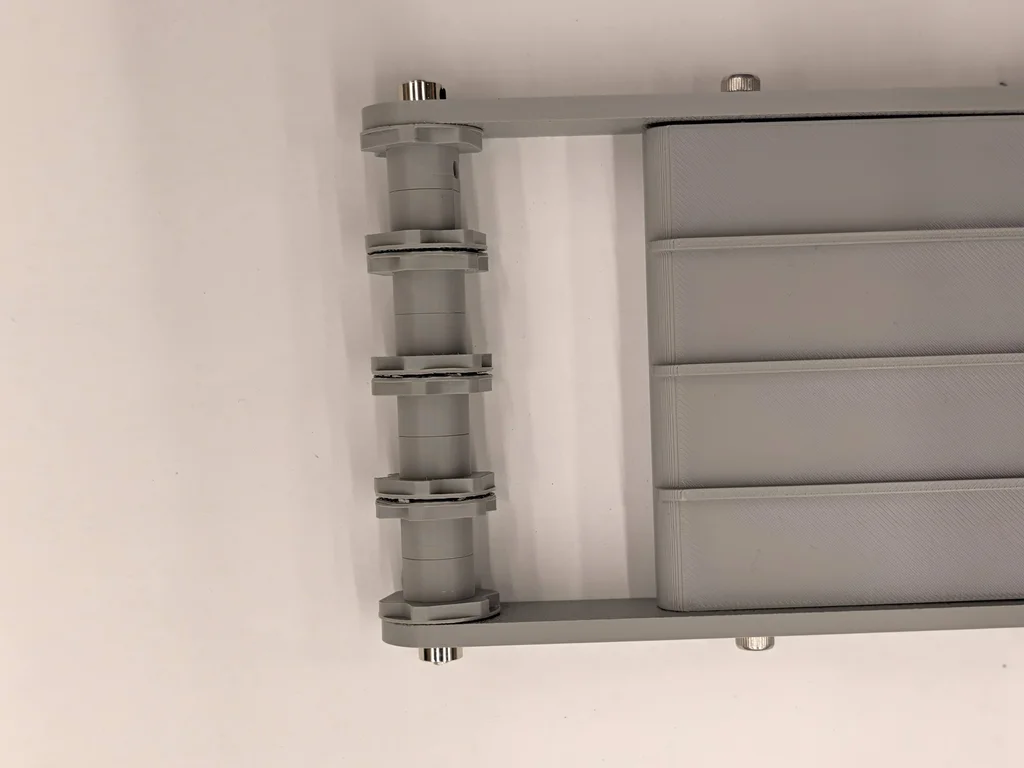
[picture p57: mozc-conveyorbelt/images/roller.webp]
Sprocket and Roller Assembly


#### Step 4: Assemble Frame and Drive Mechanism

1. Place the main `Box` enclosure in the center and fasten `SidePlate_Bottom`, `SidePlate_Top`, and the reinforcing `Stay` plates (2 pcs) using the hex socket head cap screws (M4 × 8mm, M4 × 6mm, and M2.5 × 8mm), clamping the shafts between the side plates.
2. Attach the 2GT timing pulleys (20T, 2 pcs in total) onto the 3mm shaft of the motor and the remaining end of the drive shaft (the end without a shaft collar).
3. Loop the 2GT timing belt (6mm width, 110mm length) around the motor pulley and the drive shaft pulley.
4. Connect the conveyor belt links `Belt` (29 pcs × 4 columns = 116 pcs) into 4 loops, mount the low-profile switches and keycaps onto them, and wrap the belt assemblies around the rollers.

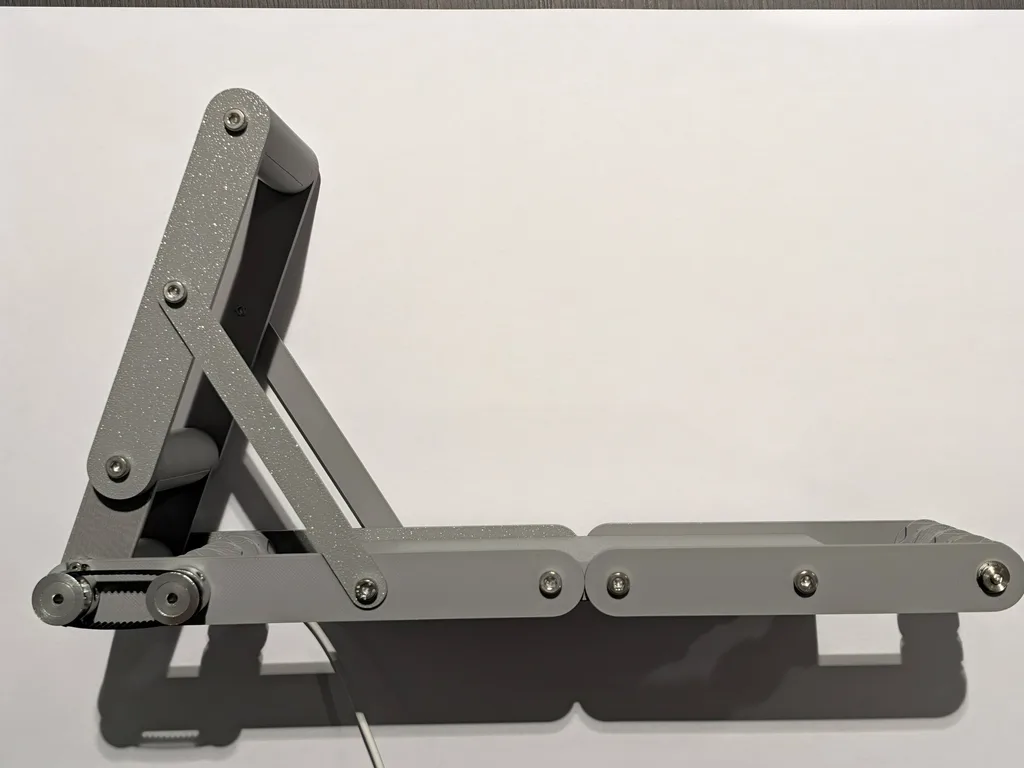
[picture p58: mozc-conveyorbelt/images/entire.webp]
Frame and Drive Mechanism Assembly


#### Step 5: Mount the Electronics

1. Mount the `ATOMS3 Lite` controller into the dedicated slot on `Cover_wAtom`, and wire it to the `DRV8833` driver and capacitors (220μF electrolytic capacitor and 0.1μF ceramic capacitor).

#### Step 6: Attach Outer Covers

1. Attach the outer covers (`BaseCoverL`, `BaseCoverR`, `Cover_BottomL`, `Cover_wAtom`, and `Cover_Top` × 2) to the sides and secure them with screws to complete the assembly.

## Bluetooth Connection Edition

Coming soon.

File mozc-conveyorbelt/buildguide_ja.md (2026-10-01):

# ビルドガイド

Gboard DIY

[プロジェクトの概要はこちら](./README_ja.md)

## ファイル一覧

- `stls/` : ケース・機構用 3D モデル (STL)
- [`board/`](./board/README_ja.md) : 回路・電子部品に関するドキュメント（今後公開予定）
- [`firmware/`](./firmware/README_ja.md) : ファームウェア開発リソース一式
- `firmware/prebuilt/` : コンパイル済みファームウェアバイナリ

## モデル

本キーボードには以下の2種類のモデルがあります。
- **キーが流れるモデル**: モーターでコンベアベルトが回転し、キーが流れるモデル
- **Bluetooth接続モデル**: Bluetooth接続で文字入力が可能なモデル（今後公開予定）

以下では、**キーが流れるモデル**の組み立て方を説明します。

## キーが流れるモデル

### 必要な部品 (BOM)

#### 3Dプリント品

| プレビュー | 部品名 | ファイル | 数量 | 備考 |
| :-: | :--- | :--- | :-: | :--- |
| Base_Roller | Base_Roller | [`Base_Roller.stl`](./stls/Base_Roller.stl) | 2 | ベース部回転ローラー |
| Base_Side | Base_Side | [`Base_Side.stl`](./stls/Base_Side.stl) | 2 | ベース部左右メインサイドフレーム |
| BaseCoverL | BaseCoverL | [`BaseCoverL.stl`](./stls/BaseCoverL.stl) | 1 | ベース部 左側面カバー |
| BaseCoverR | BaseCoverR | [`BaseCoverR.stl`](./stls/BaseCoverR.stl) | 1 | ベース部 右側面カバー |
| BottomTube | BottomTube | [`BottomTube.stl`](./stls/BottomTube.stl) | 3 | 外径21mm 内径18mm L70mm のパイプも可 |
| BottomTubePlate | BottomTubePlate | [`BottomTubePlate.stl`](./stls/BottomTubePlate.stl) | 1 | 下部チューブ軸受・保持プレート |
| Box | Box | [`Box.stl`](./stls/Box.stl) | 1 | メイン筐体 |
| Cover_BottomL | Cover_BottomL | [`Cover_BottomL.stl`](./stls/Cover_BottomL.stl) | 1 | 下部左側面カバー |
| Cover_Top | Cover_Top | [`Cover_Top.stl`](./stls/Cover_Top.stl) | 2 | 上部側面カバー（左右共通） |
| Cover_wAtom | Cover_wAtom | [`Cover_wAtom.stl`](./stls/Cover_wAtom.stl) | 1 | ATOMS3 Lite 取付用スロット付きカバー |
| MotorSupport | MotorSupport | [`MotorSupport.stl`](./stls/MotorSupport.stl) | 1 | モーター＆ドライバー保持ブラケット |
| SidePlate_Bottom | SidePlate_Bottom | [`SidePlate_Bottom.stl`](./stls/SidePlate_Bottom.stl) | 2 | 下部インナーサイドプレート |
| SidePlate_Top | SidePlate_Top | [`SidePlate_Top.stl`](./stls/SidePlate_Top.stl) | 2 | 上部インナーサイドプレート |
| SprocketA | SprocketA | [`SprocketA.stl`](./stls/SprocketA.stl) | 4 | スプロケットA（片面にのみ突起あり） |
| SprocketB | SprocketB | [`SprocketB.stl`](./stls/SprocketB.stl) | 6 | スプロケットB（両面に突起があり、両面の突起の角度が同じ） |
| SprocketC | SprocketC | [`SprocketC.stl`](./stls/SprocketC.stl) | 6 | スプロケットC（両面に突起があり、両面の突起の角度がずれている） |
| Stay | Stay | [`Stay.stl`](./stls/Stay.stl) | 2 | t2mm 12×110mm |
| Belt | Belt | [`Belt.stl`](./stls/Belt.stl) | 116 | コンベアベルトのコマ（29個×4列） |

#### 機械部品・ねじ類

| 品名 | 数量 | 備考・参考リンク |
| :--- | :-: | :--- |
| 3mm L105mm シャフト | 2 | [参考リンク](https://www.amazon.co.jp/dp/B0DS8YLN65)（こちらを105mmにカット） |
| Insert Nut M4 x 4mm x 5mm | 14 | [参考リンク1](https://www.amazon.co.jp/dp/B0DJ8C9PJN) / [参考リンク2](https://www.amazon.co.jp/dp/B0FFGZKGJC) |
| Insert Nut M2.5 x 3.5mm x 3.5mm | 8 | [参考リンク](https://www.amazon.co.jp/dp/B0FVD9XB56) |
| 六角穴付イモネジ M2.5 x 4mm | 4 | [参考リンク](https://www.amazon.co.jp/dp/B0F4Q98MY7) |
| 六角穴付きボルト M4 x 8mm | 12 | [参考リンク](https://www.amazon.co.jp/dp/B0DDWLZYRK) |
| 六角穴付きボルト M4 x 6mm | 2 | [参考リンク](https://www.amazon.co.jp/dp/B002A5KK76) |
| 六角穴付きボルト M2.5 x 8mm | 4 | [参考リンク](https://www.amazon.co.jp/dp/B0FLYCZ4R2) |
| タイミングプーリー 2GT ベルト幅6mm 20T 穴径3mm | 2 | [参考リンク](https://www.amazon.co.jp/dp/B09Y1N3WXT) |
| タイミングベルト 2GT 幅6mm 長さ110mm | 1 | [参考リンク](https://www.amazon.co.jp/dp/B0CNT721G6) |
| ベアリング 623ZZ 内径3mm 外径10mm 幅4mm | 4 | [参考リンク](https://www.amazon.co.jp/dp/B0G6ZG3Z8F) |
| ベアリング MR63ZZ 内径3mm 外径6mm 幅2.5mm | 1 | [参考リンク](https://www.amazon.co.jp/dp/B0CFZQRL8C) |
| 3mmシャフトカラー 8mm外径 4mm幅 | 3 | [参考リンク](https://www.amazon.co.jp/dp/B0CQNYN2N6) |

#### 電子部品

| 品名 | 数量 | 備考・参考リンク |
| :--- | :-: | :--- |
| モータードライバー DRV8833 | 1 | [参考リンク](https://www.amazon.co.jp/dp/B098Q24ZV9) |
| DC6V N20メタルギアードモーター 3mmシャフト 150RPM | 1 | [参考リンク](https://www.amazon.co.jp/dp/B0FZFKGC6F) |
| ATOMS3 Lite | 1 | [参考リンク](https://www.switch-science.com/products/8778) |
| 2.54mm ピンヘッダ 4P | 1 | [参考リンク](https://www.amazon.co.jp/dp/B0829W3T8Q) |
| 2.54mm ピンヘッダ 5P | 1 | |
| 220μF 電解コンデンサ | 1 | [参考リンク](https://www.amazon.co.jp/dp/B07D3P2NFY) |
| 0.1μF セラミックコンデンサ | 1 | [参考リンク](https://www.amazon.co.jp/dp/B079YJ78VS) |
| ロープロファイルスイッチ (Kailh Choc V1) | 116 | [参考リンク](https://shop.yushakobo.jp/collections/all-switches/products/pg1350) |
| ロープロファイルキーキャップ (Kailh Choc V1) | 116 | [参考リンク](https://shop.yushakobo.jp/collections/choc-v1-keycaps/products/pg1350cap-blank) |

### 組み立て

#### Step 1: 3Dプリント部品の準備とインサートナットの圧入

1. 上記部品表の 3D プリント部品（全18種・計157個）を出力します。`BottomTube`（3個）は外径 21mm・内径 18mm・長さ 70mm のパイプで代用することも可能です。
2. はんだごて等を使用して、M4 インサートナット（14個）を `Base_Side`（1箇所×2個）、`Base_Roller`（両端2箇所×2個）、および `Box`（両側面4箇所×2面）に熱圧入します。

M4インサートナットの圧入

3. M2.5 インサートナット（8個）を `MotorSupport`（2箇所）、`BottomTubePlate`（2箇所）、および `SprocketA` のボス側面（1箇所×4個）に熱圧入します。

M2.5インサートナットの圧入

#### Step 2: ベースの組み立て

1. `MotorSupport` に DC6V N20 メタルギアードモーター（150RPM）とモータードライバー `DRV8833` を取り付けます。
2. `BottomTube`（3個）、`Base_Roller`（2個）、`Base_Side`（2個）、`BottomTubePlate`（1個）、および `MotorSupport`（1個）を組み合わせてベース部を組み立て、M4 六角穴付きボルトで固定します。電源ケーブルは `BottomTubePlate` の穴から `BottomTube` の内部を通して配線します。

ベースの組み立て

#### Step 3: シャフト・スプロケットの組み立て

1. 3mm シャフト（長さ 105mm、2本）のそれぞれに、スプロケットを **`SprocketA`、`SprocketB`、`SprocketC`、`SprocketB`、`SprocketC`、`SprocketB`、`SprocketC`、`SprocketA`** の順（1本あたり8個、2本で計16個）に通し、両端に `623ZZ` ベアリングを通します（計4個）。1本は両端、もう1本は片方を 3mm シャフトカラーで止めます（計3個）。
2. `SprocketA` のボス穴に六角穴付イモネジ（M2.5 × 4mm、4個）を締め込み、シャフトに固定します。

スプロケット・ローラーの組み立て

#### Step 4: フレーム・駆動機構の組み立て

1. メイン筐体 `Box` を中央に配置し、シャフトを挟み込むようにして `SidePlate_Bottom`、`SidePlate_Top`、および連結補強用の `Stay`（2個）を六角穴付きボルト（M4 × 8mm、M4 × 6mm、M2.5 × 8mm）で締結します。
2. モーターの 3mm 軸と、シャフトの残りの端（シャフトカラーを付けていない側）に 2GT タイミングプーリー（20T、計2個）を取り付けます。
3. モーター側のプーリーと駆動シャフト側のプーリーに 2GT タイミングベルト（幅 6mm、長さ 110mm）を掛けます。
4. コンベアベルトのコマ `Belt`（29個×4列＝116個）を4本の輪にしてロープロファイルスイッチとキーキャップを取り付け、ローラー群に巻き付けます。

フレーム・駆動機構の組み立て

#### Step 5: 電装系の組み付け

1. `Cover_wAtom` の専用スロットに `ATOMS3 Lite` を装着し、`DRV8833` およびコンデンサ（220μF 電解コンデンサ、0.1μF セラミックコンデンサ）を配線します。

#### Step 6: 外装カバーの取り付け

1. 外装カバー（`BaseCoverL`、`BaseCoverR`、`Cover_BottomL`、`Cover_wAtom`、`Cover_Top` × 2）を側面から取り付け、ボルトで固定して完成です。

## Bluetooth接続モデル

今後公開予定。

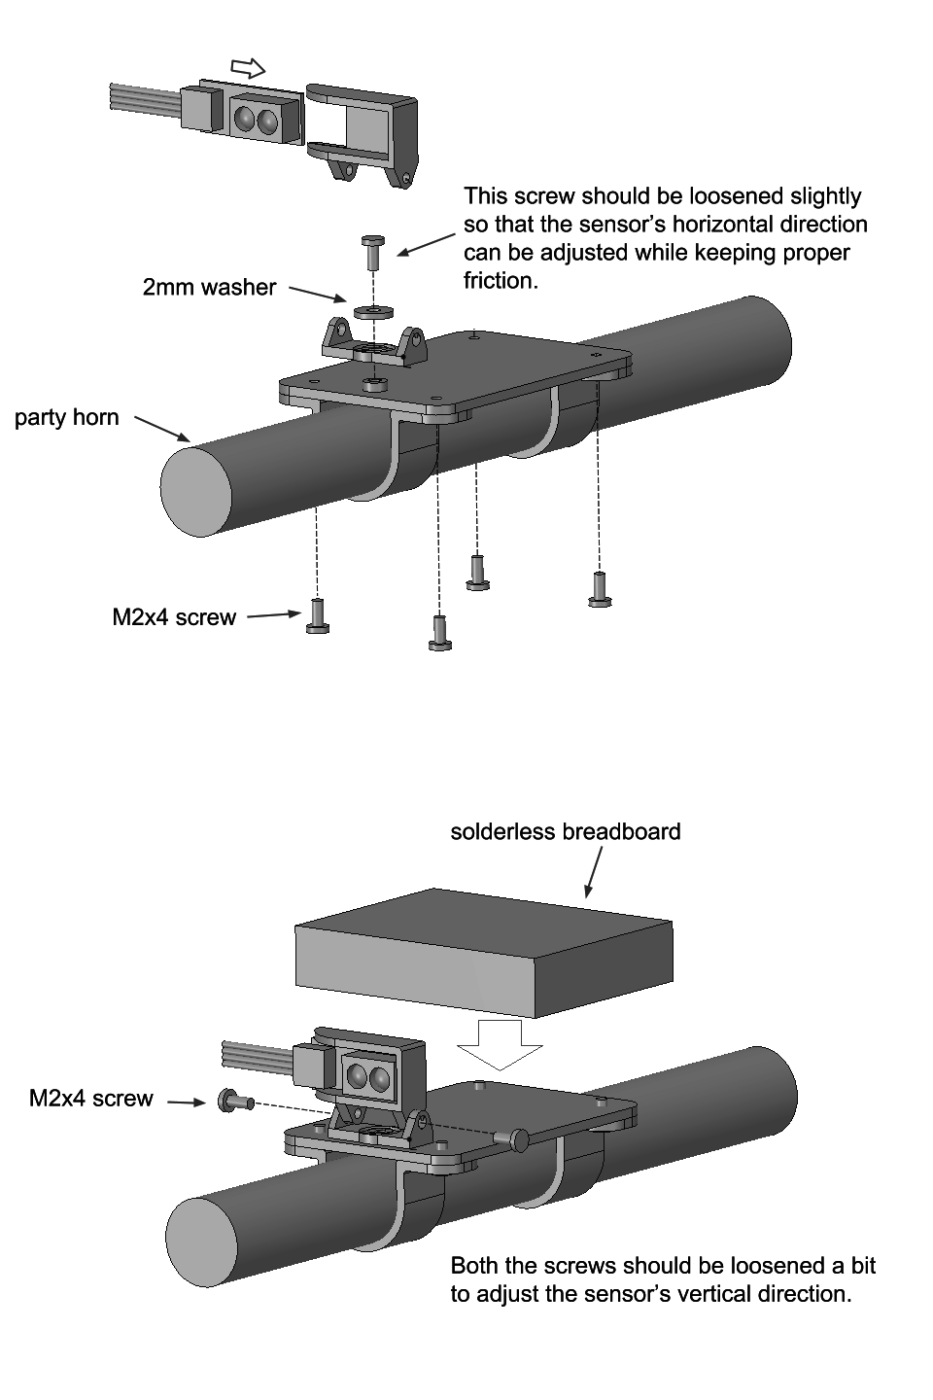
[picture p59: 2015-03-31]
mozc-piropiro/assembly.png

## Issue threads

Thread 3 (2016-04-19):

Missing STL files for Furikku

protestContest, 2016-04-19:
This project looks awesome, and I'd love to build one just like it. Are there any plans to publish sources for the housing or the key tops?

ikeji, 2024-10-03:
Unfortunetly we don't have a plan to release this file. Thanks!

Closed 2024-10-03.

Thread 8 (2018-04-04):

UnicodeDecodeError in installation

tushuhei, 2018-04-04:
I encountered UnicodeDecodeError in installation. We may want to read README.rst specifying its encoding.

$ python3 setup.py
Traceback (most recent call last):
  File "setup.py", line 32, in <module>
    long_description=read_file('README.rst'),
  File "setup.py", line 23, in read_file
    return f.read().strip()
  File "/usr/lib/python3.5/encodings/ascii.py", line 26, in decode
    return codecs.ascii_decode(input, self.errors)[0]
UnicodeDecodeError: 'ascii' codec can't decode byte 0xe3 in position 6988: ordinal not in range(128)

Closed 2018-04-04.

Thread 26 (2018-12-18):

I'd like to use on chrome OS

Og-Amayokoy, 2018-12-18:
When is support chrome os?

tushuhei, 2018-12-21:
Hi there,
Thank you for reaching out to us. This repository is a collection of several devices related to Which device you would like to use on Chrome OS?

Yokoyama-Go, 2018-12-24:
Google input [Tegaki](https://landing.google.co.jp/tegaki/) is.
I'd like to use tablet mode too.

My device is Chrombook Asus c 101pa. Version 72.0.3626.30 (Official Build) dev (32-bit)

makotoshimazu, 2019-01-10:
Thanks for reaching out to us.
The [demo](https://landing.google.co.jp/tegaki/#demo) is working well on my Chromebook. What did you try on your Chromebook?

Yokoyama-Go, 2019-01-11:
I'm afraid but, I would like to use on usual input like this GitHub issue page, google search box.
Could you develop and make available Google Tegaki input on [Google input tools extension](https://chrome.google.com/webstore/detail/google-input-tools/mclkkofklkfljcocdinagocijmpgbhab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)?

makotoshimazu, 2019-03-05:
So sorry for my very slow response. I completely missed your response.

Thanks for asking, but actually, Physica Handwriting Version is one of our product release for **the event on April 1st**. We don't have any furthur plans except for the demo.

Closed 2019-03-05.

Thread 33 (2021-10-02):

Gboard 湯呑みバージョンについて

edama2, 2021-10-02:
USB-C connector breakoutはどこに接続するんでしょうか？
湯呑みの外装パーツと動画に出てくる専用茶托ドックは3Dデータで公開されるのでしょうか？

ikeji, 2021-12-23:
外装ではないのですが、promicroバージョンでおつかいいただける高台を公開しました。
https://github.com/google/mozc-devices/blob/master/mozc-yunomi/platform_promicro.stl

Closed 2024-10-03.

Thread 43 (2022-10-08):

ケースの3Dモデルに基板のモデルが混在している

sthairno, 2022-10-08:
mozc-barのケースのうち、TypeDのSTLファイルにのみ基板のモデルが混ざっています。

https://github.com/google/mozc-devices/blob/41ac20b478abf2290628bdd20b6066d89c77b12e/mozc-bar/case/typeD.stl

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

yamaguchi-am, 2022-10-08:
ご報告いただき、ありがとうございます。
commit 0e098eb にて修正しました。

Closed 2022-10-08.

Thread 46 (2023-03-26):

Gboard 棒バージョンのPCBとCASE準備数量及びアルミフレーム寸法ミスについて。

Sakoda1066, 2023-03-26:
README.mdのPCB及びcaseの準備数が、キーマッピングと一致せず、typeAを9個、typeBを2個準備するよう書かれていますが、正しくはtypeAを8個、typeBを3個だと思います。また、準備するアルミフレーム寸法も間違えた個数に準拠した寸法となっているため、キーマッピング通り組み立てると(typeA幅-typeB幅=76mm?)長いです。

ikeji, 2023-03-28:
修正しました。ご指摘感謝致します。

Closed 2023-03-28.

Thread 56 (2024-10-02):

Update nazoru-input PyPI package

mak448a, 2024-10-02:
This project is awesome! Could you update the pypi version so that we can have a one line pip install command to install nazoru input's latest version? Thanks Google Japan! 👍🏻

tushuhei, 2024-10-04:
Thanks for your comment! Just uploaded the latest version at https://pypi.org/project/nazoru-input/0.1.2/

Closed 2024-10-04.

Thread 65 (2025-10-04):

Could you share the dial key-to-letter mapping?

Amcc1860, 2025-10-04:
I really like the Mozc Dial project! I’m trying to 3D print my own keycaps with letters on them (using two-color printing), but the STL files don’t seem to show which key corresponds to which letter.

Could you share the full mapping of keys/positions to letters? It would help a lot for customizing the prints.

Thanks a lot!

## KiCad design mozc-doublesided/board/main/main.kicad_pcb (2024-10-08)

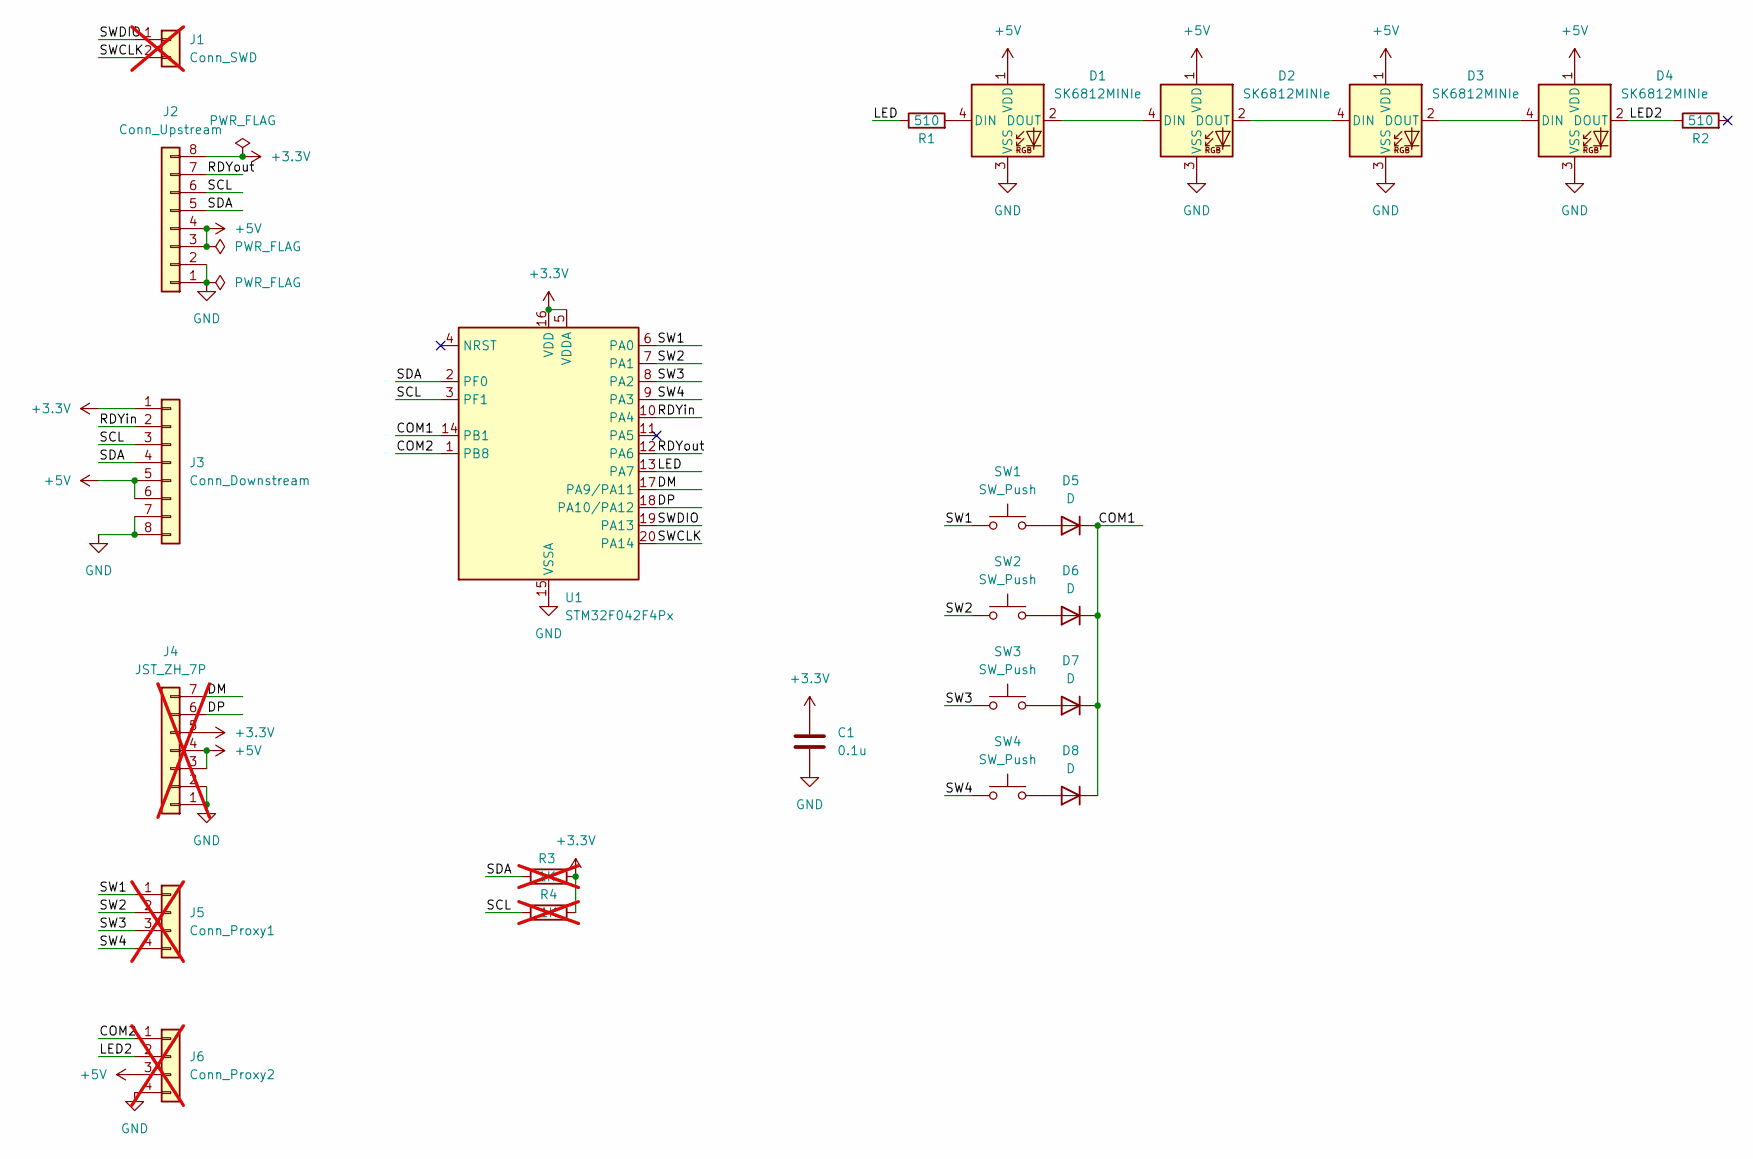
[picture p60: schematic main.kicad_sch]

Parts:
C1: 0.1u; C_0402_1005Metric
D1, D2, D3, D4: SK6812MINIe; SK6812MINIe (Reverse); MPN C5149201
D5, D6, D7, D8: D; D_0805_2012Metric; MPN C109001
J1: Conn_SWD; PinHeader_1x02_P2.54mm_Vertical; not fitted
J2: Conn_Upstream; JST_S8B_ZR; MPN C2845571
J3: Conn_Downstream; JST_S8B_ZR; MPN C2845571
J4: JST_ZH_7P; JST_S7B_ZR; MPN C160734; not fitted
J5: Conn_Proxy1; PinHeader_1x04_P2.54mm_Vertical; not fitted
J6: Conn_Proxy2; PinHeader_1x04_P2.54mm_Vertical; not fitted
R1, R2: 510; R_0402_1005Metric
R3, R4: 1K; R_0603_1608Metric_Pad0.98x0.95mm_HandSolder; not fitted
SW1, SW2, SW3, SW4: SW_Push; Keyswitch; MPN C5184526
U1: STM32F042F4Px; TSSOP-20_4.4x6.5mm_P0.65mm; MPN C81002

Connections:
+3.3V: C1.1, J2.8, J3.1, J4.5, R3.2, R4.2, U1.5 (VDDA), U1.16 (VDD)
+5V: D1.1 (VDD), D2.1 (VDD), D3.1 (VDD), D4.1 (VDD), J2.3, J2.4, J3.5, J3.6, J4.3, J4.4, J6.3
/COM1: D5.1 (K), D6.1 (K), D7.1 (K), D8.1 (K), U1.14 (PB1)
/COM2: J6.1, U1.1 (PB8)
/DM: J4.7, U1.17 (PA9/PA11)
/DP: J4.6, U1.18 (PA10/PA12)
/LED: R1.1, U1.13 (PA7)
/LED2: D4.2 (DOUT), J6.2, R2.1
/RDYin: J3.2, U1.10 (PA4)
/RDYout: J2.7, U1.12 (PA6)
/SCL: J2.6, J3.3, R4.1, U1.3 (PF1)
/SDA: J2.5, J3.4, R3.1, U1.2 (PF0)
/SW1: J5.1, SW1.1, U1.6 (PA0)
/SW2: J5.2, SW2.1, U1.7 (PA1)
/SW3: J5.3, SW3.1, U1.8 (PA2)
/SW4: J5.4, SW4.1, U1.9 (PA3)
/SWCLK: J1.2, U1.20 (PA14)
/SWDIO: J1.1, U1.19 (PA13)
GND: C1.2, D1.3 (VSS), D2.3 (VSS), D3.3 (VSS), D4.3 (VSS), J2.1, J2.2, J3.7, J3.8, J4.1, J4.2, J6.4, U1.15 (VSSA)
unnamed: D1.4 (DIN), R1.2
unnamed: D1.2 (DOUT), D2.4 (DIN)
unnamed: D2.2 (DOUT), D3.4 (DIN)
unnamed: D3.2 (DOUT), D4.4 (DIN)
unnamed: D5.2 (A), SW1.2
unnamed: D6.2 (A), SW2.2
unnamed: D7.2 (A), SW3.2
unnamed: D8.2 (A), SW4.2

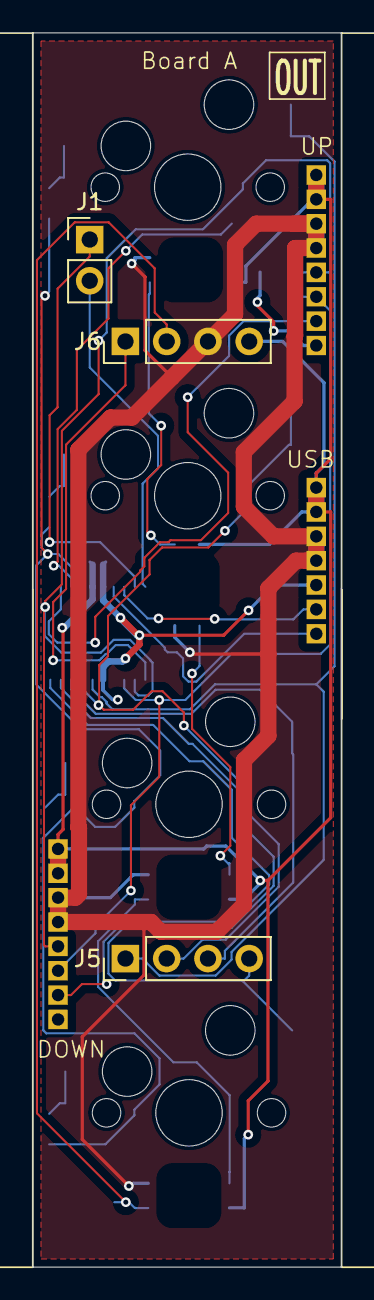
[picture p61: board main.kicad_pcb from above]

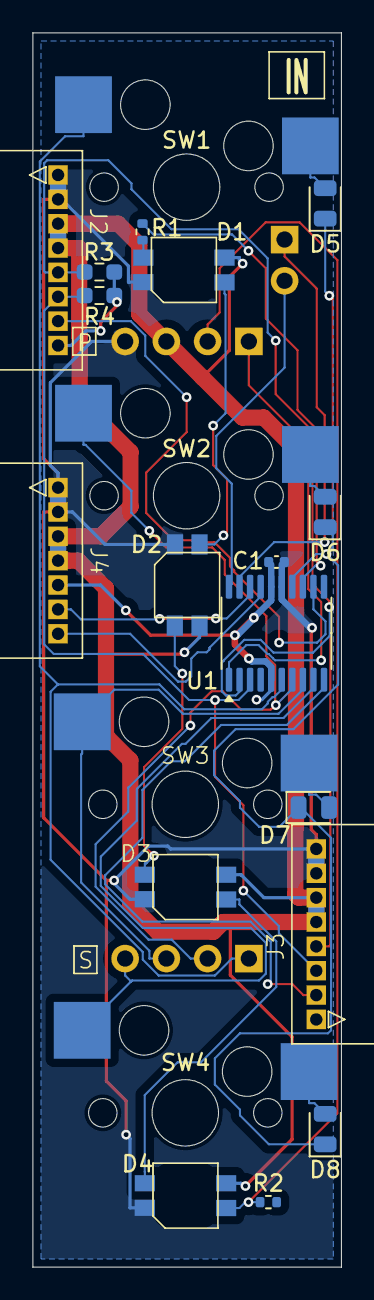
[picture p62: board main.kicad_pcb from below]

Board: 4 copper layers, 19.0 x 76.0 mm, 26 parts (21 on the bottom side), 27 nets.

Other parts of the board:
CUT1, CUT2: CUT

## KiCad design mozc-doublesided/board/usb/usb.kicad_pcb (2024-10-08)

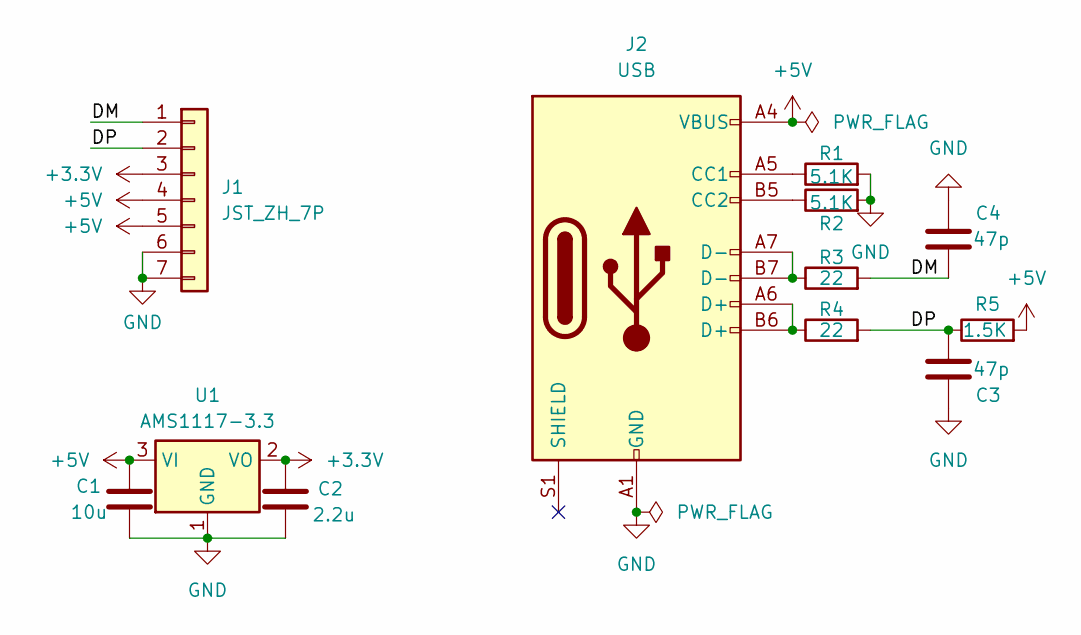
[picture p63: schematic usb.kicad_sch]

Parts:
C1: 10u; C_0402_1005Metric
C2: 2.2u; C_0402_1005Metric
C3, C4: 47p; C_0402_1005Metric
J1: JST_ZH_7P; JST_S7B_ZR; MPN C160734
J2: USB; USB_C_Receptacle_XKB_U262-16XN-4BVC11; MPN C5178539
R1, R2: 5.1K; R_0402_1005Metric
R3, R4: 22; R_0402_1005Metric
R5: 1.5K; R_0402_1005Metric
U1: AMS1117-3.3; SOT-223-3_TabPin2; MPN C347222

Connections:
+3.3V: C2.2, J1.3, U1.2 (VO)
+5V: C1.2, J1.4, J1.5, J2.A4 (VBUS), J2.A9 (VBUS), J2.B4 (VBUS), J2.B9 (VBUS), R5.2, U1.3 (VI)
/DM: C4.2, J1.1, R3.2
/DP: C3.1, J1.2, R4.2, R5.1
GND: C1.1, C2.1, C3.2, C4.1, J1.6, J1.7, J2.A1 (GND), J2.A12 (GND), J2.B1 (GND), J2.B12 (GND), R1.2, R2.2, U1.1 (GND)
unnamed: J2.A5 (CC1), R1.1
unnamed: J2.B5 (CC2), R2.1
unnamed: J2.A6 (D+), J2.B6 (D+), R4.1
unnamed: J2.A7 (D-), J2.B7 (D-), R3.1

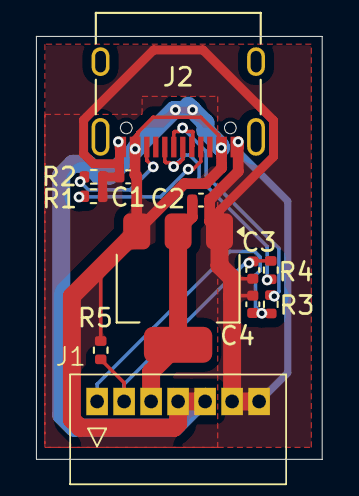
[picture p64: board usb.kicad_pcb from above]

Board: 2 copper layers, 15.9 x 23.5 mm, 12 parts (0 on the bottom side), 9 nets.

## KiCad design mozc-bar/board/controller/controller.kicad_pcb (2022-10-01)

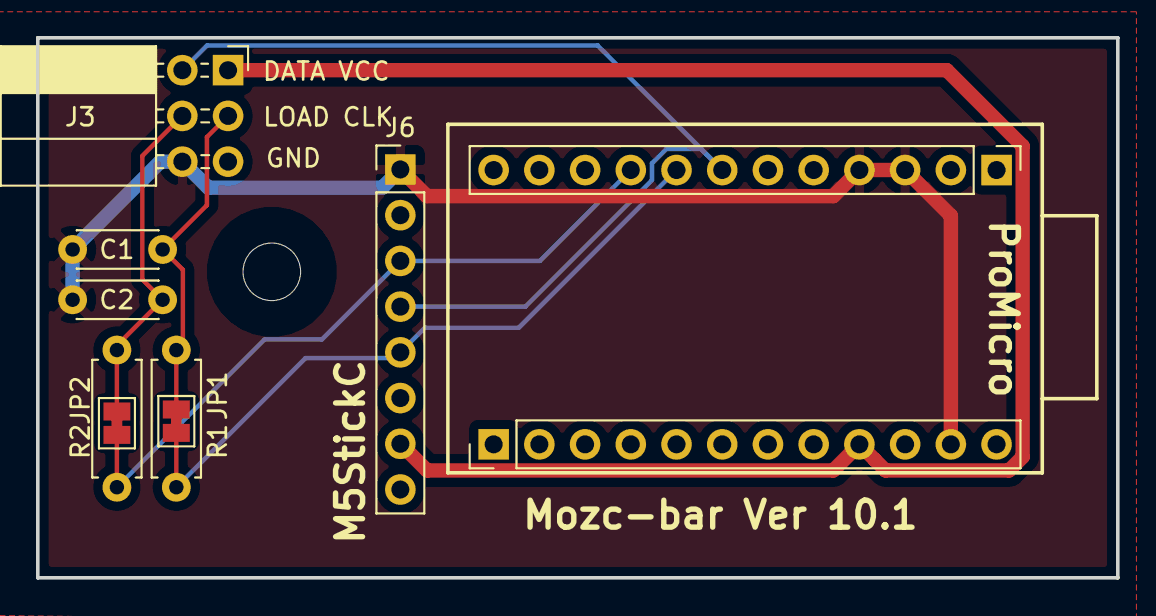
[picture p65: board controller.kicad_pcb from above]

Board: 2 copper layers, 60.0 x 30.0 mm, 10 parts (0 on the bottom side), 7 nets.

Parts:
C1, C2: C; C_Disc_D4.3mm_W1.9mm_P5.00mm
J1, J2: Conn_01x12_Female; PinHeader_1x12_P2.54mm_Vertical
J3: Conn_01x06; PinSocket_2x03_P2.54mm_Horizontal
J6: Conn_01x08_Male; PinHeader_1x08_P2.54mm_Vertical
JP1, JP2: Jumper; SolderJumper-2_P1.3mm_Bridged_Pad1.0x1.5mm
R1, R2: R; R_Axial_DIN0207_L6.3mm_D2.5mm_P7.62mm_Horizontal

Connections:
/CLK_OUT: J1.8, J6.5, JP1.2, R1.1
/CLK_OUT_BUF: C1.1, J3.3, JP1.1, R1.2
/DATA_IN: J1.7, J3.2, J6.4
/LOAD_OUT: J1.9, J6.3, JP2.2, R2.1
/LOAD_OUT_BUF: C2.1, J3.4, JP2.1, R2.2
GND: C1.2, C2.2, J1.3, J1.4, J2.11, J3.6, J6.1
VCC: J2.9, J3.1, J6.7

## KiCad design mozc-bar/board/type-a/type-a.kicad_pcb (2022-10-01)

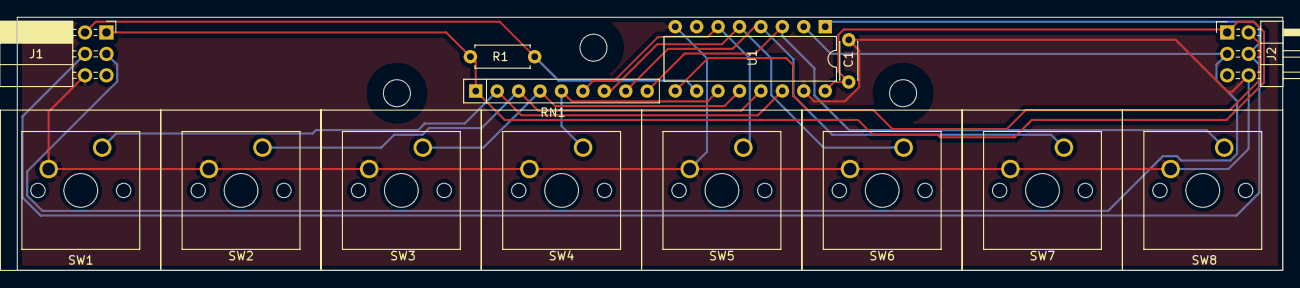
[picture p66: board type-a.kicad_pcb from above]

Board: 2 copper layers, 150.0 x 30.0 mm, 17 parts (0 on the bottom side), 14 nets.

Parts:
C1: C; C_Disc_D4.3mm_W1.9mm_P5.00mm
H1, H101, H102: MountingHole; MountingHole_3.2mm_M3
J1: Conn_01x06_Female; PinSocket_2x03_P2.54mm_Horizontal
J2: Conn_01x06_Male; PinHeader_2x03_P2.54mm_Horizontal
R1: 100k; R_Axial_DIN0207_L6.3mm_D2.5mm_P7.62mm_Horizontal
RN1: 100k; R_Array_SIP9
SW1, SW2, SW3, SW4, SW5, SW6, SW7, SW8: SW_Push; SW_Cherry_MX_1.00u_PCB
U1: 74HC165; DIP-16_W7.62mm

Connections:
/CLK_IN: J1.3, J2.3, U1.2
/DATA_IN: J1.2, R1.1, U1.10
/DATA_OUT: J2.2, U1.9
/LOAD_IN: J1.4, J2.4, U1.1
GND: C1.2, J1.6, J2.6, SW1.2, SW2.2, SW3.2, SW4.2, SW5.2, SW6.2, SW7.2, SW8.2, U1.8, U1.15
SW1: RN1.5, SW4.1, U1.11
SW2: RN1.4, SW3.1, U1.12
SW3: RN1.3, SW2.1, U1.13
SW4: RN1.2, SW1.1, U1.14
SW5: RN1.9, SW8.1, U1.3
SW6: RN1.8, SW7.1, U1.4
SW7: RN1.7, SW6.1, U1.5
SW8: RN1.6, SW5.1, U1.6
VCC: C1.1, J1.1, J2.1, R1.2, RN1.1, U1.16

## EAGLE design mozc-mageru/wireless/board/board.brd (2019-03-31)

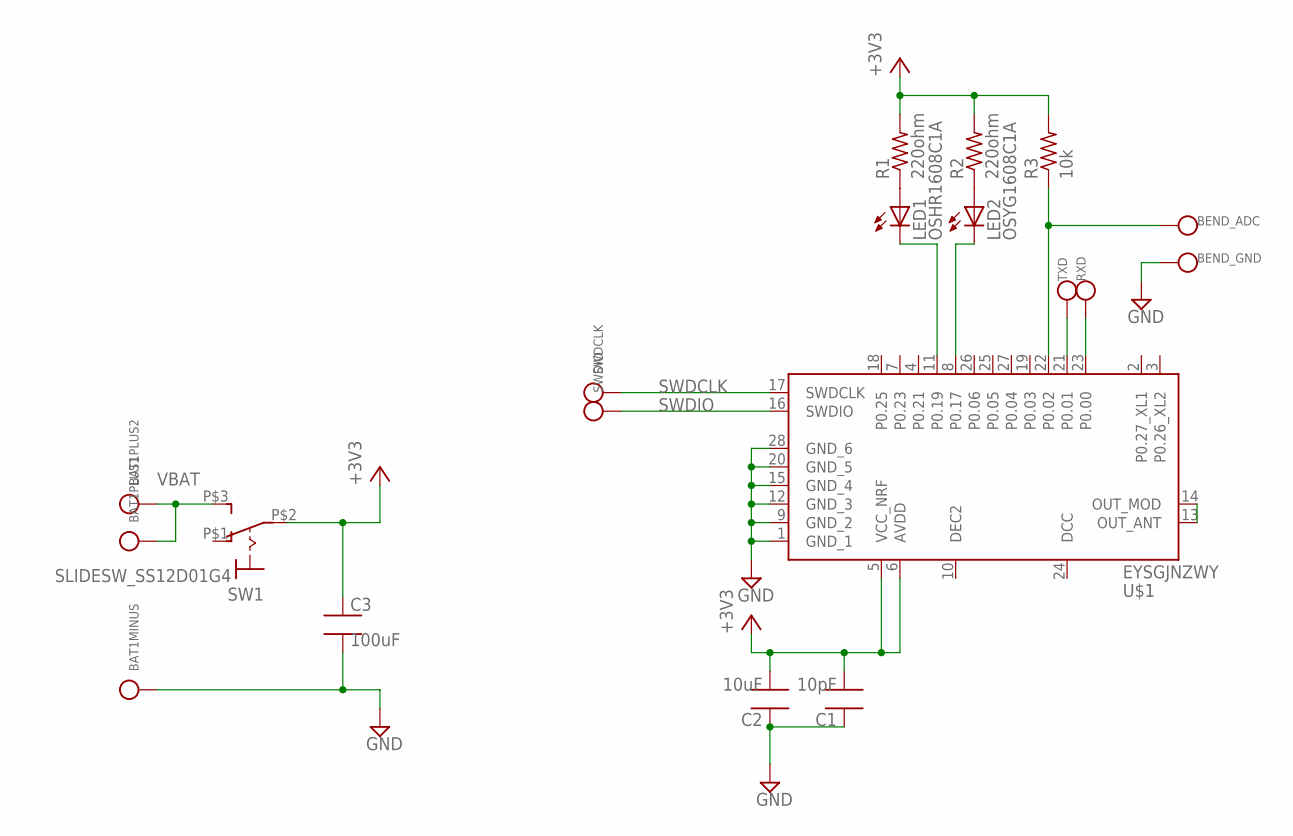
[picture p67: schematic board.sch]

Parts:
BAT1: BATTERY; CR1025
BEND_ADC: CHECK_PIN-SMD_100*60; SMD_100*60
BEND_GND: CHECK_PIN-SMD_100*60; SMD_100*60
C1: 10pF; 1005
C2: 10uF; 1005
C3: 100uF; 3216
LED1: OSHR1608C1A; 1608-LED
LED2: OSYG1608C1A; 1608-LED
R1, R2: 220ohm; 1608
R3: 10k; 1608
RXD: CHECK_PIN-SMD_100*60; SMD_100*60
SW1: SLIDESW_SS12D01G4; SS12D01G4
SWDCLK: CHECK_PIN-SMD_100*60; SMD_100*60
SWDIO: CHECK_PIN-SMD_100*60; SMD_100*60
TXD: CHECK_PIN-SMD_100*60; SMD_100*60
U$1: EYSGJNZWY; TAIYOYUDEN_BT_XXXXJN

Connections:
+3V3: C1.2, C2.2, C3.1, R1.2, R2.2, R3.2, SW1.P$2, U$1.5 (VCC_NRF), U$1.6 (AVDD)
GND: BAT1.-, BEND_GND.SIGNAL, C1.1, C2.1, C3.2, U$1.1 (GND_1), U$1.9 (GND_2), U$1.12 (GND_3), U$1.15 (GND_4), U$1.20 (GND_5), U$1.28 (GND_6)
unnamed: LED1.1 (A), R1.1
unnamed: LED2.1 (A), R2.1
unnamed: LED1.2 (K), U$1.11 (P0.19)
unnamed: U$1.13 (OUT_ANT), U$1.14 (OUT_MOD)
unnamed: LED2.2 (K), U$1.8 (P0.17)
unnamed: BEND_ADC.SIGNAL, R3.1, U$1.22 (P0.02)
RXD: RXD.SIGNAL, U$1.23 (P0.00)
SWDCLK: SWDCLK.SIGNAL, U$1.17 (SWDCLK)
SWDIO: SWDIO.SIGNAL, U$1.16 (SWDIO)
TXD: TXD.SIGNAL, U$1.21 (P0.01)
VBAT: BAT1.+_1, BAT1.+_2, SW1.P$3 (S)

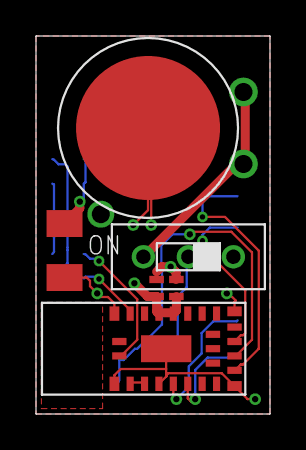
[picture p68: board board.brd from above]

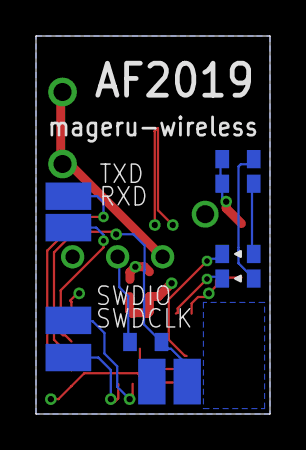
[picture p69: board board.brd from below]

Board: 4 copper layers, 13.0 x 21.0 mm, 17 parts (11 on the bottom side), 13 nets.

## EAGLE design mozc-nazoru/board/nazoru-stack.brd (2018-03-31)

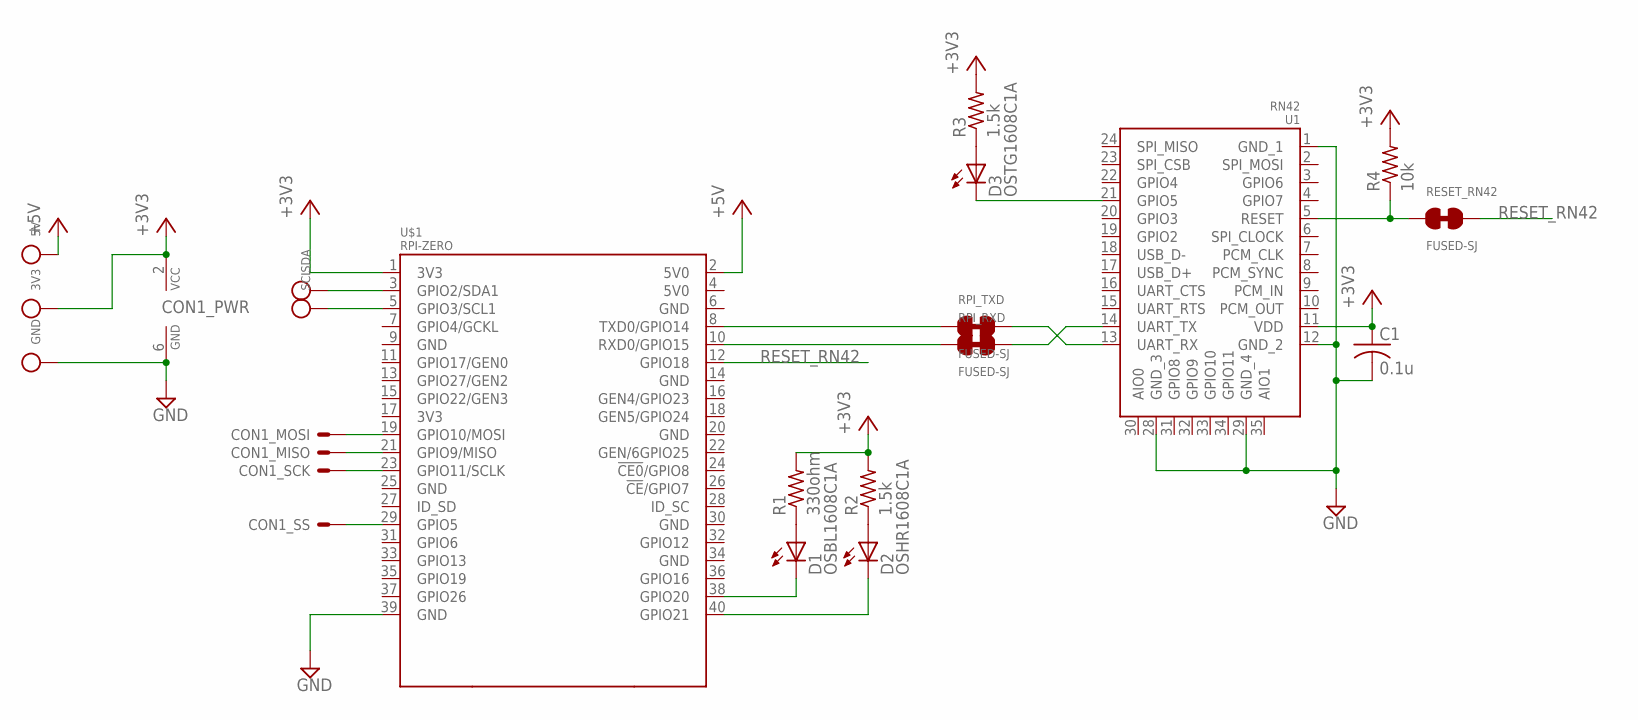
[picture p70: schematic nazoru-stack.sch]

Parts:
3V3, 5V: CHECK_PIN; SLC-22-G
C1: 0.1u; 2012-C
CON1: SPI; ML6
D1: OSBL1608C1A; 1608-LED
D2: OSHR1608C1A; 1608-LED
D3: OSTG1608C1A; 1608-LED
GND: CHECK_PIN; SLC-22-G
R1: 330ohm; 1608
R2, R3: 1.5k; 1608
R4: 10k; 1608
RESET_RN42: FUSED-SJ
RPI_RXD: FUSED-SJ
RPI_TXD: FUSED-SJ
SCL: CHECK_PIN; SLC-22-G
SDA: CHECK_PIN; SLC-22-G
U1: RN42
U$1: RPI-ZERO

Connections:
+3V3: 3V3.SIGNAL, C1.1, CON1.2 (VCC), R1.2, R2.2, R3.2, R4.2, U1.11 (VDD), U$1.1 (3V3)
+5V: 5V.SIGNAL, U$1.2 (5V0)
GND: C1.2, CON1.6 (GND), GND.SIGNAL, U1.1 (GND_1), U1.12 (GND_2), U1.28 (GND_3), U1.29 (GND_4), U$1.39 (GND)
unnamed: D1.1 (A), R1.1
unnamed: RPI_TXD.1, U$1.8 (TXD0/GPIO14)
unnamed: RPI_RXD.1, U$1.10 (RXD0/GPIO15)
unnamed: RPI_TXD.2, U1.13 (UART_RX)
unnamed: RPI_RXD.2, U1.14 (UART_TX)
unnamed: D1.2 (K), U$1.38 (GPIO20)
unnamed: D2.2 (K), U$1.40 (GPIO21)
unnamed: D2.1 (A), R2.1
unnamed: D3.1 (A), R3.1
unnamed: D3.2 (K), U1.21 (GPIO5)
unnamed: R4.1, RESET_RN42.1, U1.5 (RESET)
unnamed: CON1.4 (S), U$1.19 (GPIO10/MOSI)
unnamed: CON1.1 (S), U$1.21 (GPIO9/MISO)
unnamed: CON1.3 (S), U$1.23 (GPIO11/SCLK)
unnamed: CON1.5 (S), U$1.29 (GPIO5)
unnamed: SDA.SIGNAL, U$1.3 (GPIO2/SDA1)
unnamed: SCL.SIGNAL, U$1.5 (GPIO3/SCL1)
RESET_RN42: RESET_RN42.2, U$1.12 (GPIO18)

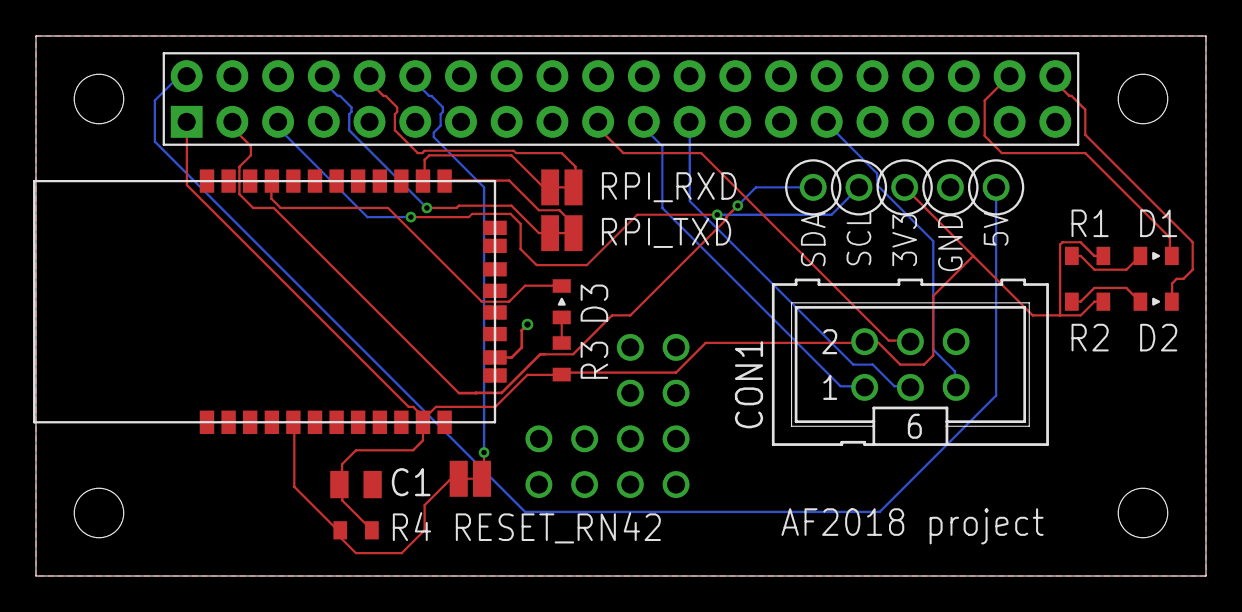
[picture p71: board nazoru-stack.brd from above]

Board: 2 copper layers, 65.0 x 30.0 mm, 19 parts (0 on the bottom side), 21 nets.

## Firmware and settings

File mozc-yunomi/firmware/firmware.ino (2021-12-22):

// Uncomment next line if you use ProMicro
// #define PRO_MICRO

// Uncomment next line if your PC thinks this is US keyboard.
// #define JP_KEYBOARD

#include "Keyboard.h"

#ifdef PRO_MICRO

// COLS = 9,8,7,6,5,4
// ROWS = 18,15,14,16,10

typedef enum {
  C0 = 9,
  C1 = 8,
  C2 = 7,
  C3 = 6,
  C4 = 5,
  C5 = 4,
  R0 = 18,
  R1 = 15,
  R2 = 14,
  R3 = 16,
  R4 = 10,
} Pin;

#define PINS 11
Pin pins[] = {C0, C1, C2, C3, C4, C5, R0, R1, R2, R3, R4};

#else

// COLS = PD0, PD1, PD2, PD3, PD4, PD5
// ROWS = PB0, PB1, PB2, PB3, PB4

#define COL B10000000
#define ROW B00000000

typedef enum {
  C0 = COL + 0,
  C1 = COL + 1,
  C2 = COL + 2,
  C3 = COL + 3,
  C4 = COL + 4,
  C5 = COL + 5,

  R0 = ROW + 0,
  R1 = ROW + 1,
  R2 = ROW + 2,
  R3 = ROW + 3,
  R4 = ROW + 4,
} Pin;

#endif

#define ROWS 5
#define COLS 12

Pin keys[5][12][2] = {
    {
        {C0, R4},
        {C1, R0},
        {C2, R1},
        {C3, R2},
        {C4, R3},
        {C5, R4},
        {R0, C0},
        {R1, C1},
        {R2, C2},
        {R3, C3},
        {R4, C4},
        {R0, C5},
    },
    {
        {C0, R3},
        {C1, R4},
        {C2, R0},
        {C3, R1},
        {C4, R2},
        {C5, R3},
        {R4, C0},
        {R0, C1},
        {R1, C2},
        {R2, C3},
        {R3, C4},
        {R4, C5},
    },
    {
        {C0, R2},
        {C1, R3},
        {C2, R4},
        {C3, R0},
        {C4, R1},
        {C5, R2},
        {R3, C0},
        {R4, C1},
        {R0, C2},
        {R1, C3},
        {R2, C4},
        {R3, C5},
    },
    {
        {C0, R1},
        {C1, R2},
        {C2, R3},
        {C3, R4},
        {C4, R0},
        {C5, R1},
        {R2, C0},
        {R3, C1},
        {R4, C2},
        {R0, C3},
        {R1, C4},
        {R2, C5},
    },
    {
        {C0, R0},
        {C1, R1},
        {C2, R2},
        {C3, R3},
        {C4, R4},
        {C5, R0},
        {R1, C0},
        {R2, C1},
        {R3, C2},
        {R4, C3},
        {R0, C4},
        {R1, C5},
    },
};

uint16_t chars[5][12] = {
    {
        0x0040,  // @
        0x002b,  // +
        0x9c19,  // 鰙
        0x9c73,  // 鱳
        0x9c25,  // 鰥
        0x9baa,  // 鮪
        0x9c30,  // 鰰
        0x9c60,  // 鱠
        0x9bdb,  // 鯛
        0x9bd6,  // 鯖
        0x9c39,  // 鰹
        0x9bf5,  // 鯵
    },
    {
        0x0020,  //
        0x002d,  // -
        0x0021,  // !
        0x9bda,  // 鯚
        0x002c,  // ,
        0x9bab,  // 鮫
        0x9c2d,  // 鰭
        0x9c0a,  // 鰊
        0x9c58,  // 鱘
        0x9bf1,  // 鯱
        0x9c5a,  // 鱚
        0x9c2f,  // 鰯
    },
    {
        0x005f,  // _
        0x002a,  // *
        0x9b5a,  // 魚
        0x9bcd,  // 鯍
        0x9b77,  // 魷
        0x9be5,  // 鯥
        0x9c24,  // 鰤
        0x9c56,  // 鱖
        0x9c41,  // 鱁
        0x9c78,  // 鱸
        0x9be8,  // 鯨
        0x9c3b,  // 鰻
    },
    {
        0x003d,  // =
        0x002f,  // /
        0x003f,  // ?
        0x9c7a,  // 鱺
        0x002e,  // .
        0x9bb4,  // 鮴
        0x9b83,  // 鮃
        0x9bf0,  // 鯰
        0x9bf3,  // 鯳
        0x9bac,  // 鮬
        0x9b5d,  // 魝
        0x9c4f,  // 鱏
    },
    {
        0x9ba8,  // 鮨
        0x8336,  // 茶
        0x9c77,  // 鱷
        0x9b6f,  // 魯
        0x9c29,  // 鰩
        0x9b79,  // 魹
        0x9bd4,  // 鯔
        0x9b76,  // 魶
        0x9c0c,  // 鰌
        0x9bfc,  // 鯼
        0x9bc9,  // 鯉
        0x9c27,  // 鰧
    },
};

void selectRow(Pin p) {
#ifdef PRO_MICRO

  pinMode(p, OUTPUT);
  digitalWrite(p, LOW);

#else

  bool col = !!(COL & p);
  byte mask = 1 << (p & B01111111);
  if (col) {
    DDRD = mask;
    PORTD = ~mask;
  } else {
    DDRB = mask;
    PORTB = ~mask;
  }

#endif
}

void unselectRows() {
#ifdef PRO_MICRO

  for (byte i = 0; i < PINS; i++) {
    pinMode(pins[i], INPUT_PULLUP);
  }

#else

  DDRD = 0;
  PORTD = B00111111;
  DDRB = 0;
  PORTB = B00011111;

#endif
}

bool readCol(Pin p) {
#ifdef PRO_MICRO

  return digitalRead(p) == LOW;

#else

  bool col = !!(COL & p);
  byte mask = 1 << (p & B01111111);
  return ((col ? PIND : PINB) & mask) == 0;

#endif
}

void setup() {
  Keyboard.begin();
  Serial.begin(9600);

  unselectRows();

  delay(100);
}

#define KEYBOARD_REPORT_ID 2

void sendKeyPush(uint8_t code, bool shift) {
  KeyReport keys;
  keys.keys[0] = 0;
  keys.keys[1] = 0;
  keys.keys[2] = 0;
  keys.keys[3] = 0;
  keys.keys[4] = 0;
  keys.keys[5] = 0;
  keys.modifiers = 0x00;
  if (shift) {
    keys.modifiers = 0x02;
    HID().SendReport(KEYBOARD_REPORT_ID, &keys, sizeof(KeyReport));
  }
  keys.keys[0] = code;
  HID().SendReport(KEYBOARD_REPORT_ID, &keys, sizeof(KeyReport));
  keys.keys[0] = 0;
  HID().SendReport(KEYBOARD_REPORT_ID, &keys, sizeof(KeyReport));
  if (shift) {
    keys.modifiers = 0;
    HID().SendReport(KEYBOARD_REPORT_ID, &keys, sizeof(KeyReport));
  }
}

#define KEY_0 0x27
#define KEY_1 0x1e
#define KEY_2 0x1f
#define KEY_3 0x20
#define KEY_4 0x21
#define KEY_5 0x22
#define KEY_6 0x23
#define KEY_7 0x24
#define KEY_8 0x25
#define KEY_9 0x26

#define KEY_A 0x04
#define KEY_B 0x05
#define KEY_C 0x06
#define KEY_D 0x07
#define KEY_E 0x08
#define KEY_F 0x09
#define KEY_U 0x18
#define KEY_EQUAL 0x2e
#define KEY_SEMICOLON 0x33
#define KEY_SPC 0x2c
#define KEY_ENT 0x28

void sendHex(int16_t in) {
  static const uint8_t codes[] = {
      KEY_0, KEY_1, KEY_2, KEY_3, KEY_4, KEY_5, KEY_6, KEY_7,
      KEY_8, KEY_9, KEY_A, KEY_B, KEY_C, KEY_D, KEY_E, KEY_F,
  };
  static const bool shifts[] = {
      false, false, false, false, false, false, false, false,
      false, false, true,  true,  true,  true,  true,  true,
  };
  for (int i = 0; i < 4; i++) {
    byte f = (in >> ((3 - i) * 4)) & 0xf;
    sendKeyPush(codes[f], shifts[f]);
  }
}

int c = 0;

void loop() {
  delay(10);
  Serial.println("--------");
  for (int r = 0; r < ROWS; r++) {
    for (int c = 0; c < COLS; c++) {
      Pin* key = keys[r][c];
      selectRow(key[1]);
      delayMicroseconds(10);
      bool pushed = readCol(key[0]);
      Serial.print(pushed ? "1" : "0");
      if (pushed) {
        sendKeyPush(KEY_U, true);
#ifdef JP_KEYBOARD
        sendKeyPush(KEY_SEMICOLON, true);
#else
        sendKeyPush(KEY_EQUAL, true);
#endif
        sendHex(chars[r][c]);
        sendKeyPush(KEY_SPC, false);
        sendKeyPush(KEY_SPC, false);
        sendKeyPush(KEY_ENT, false);
        delay(100);
      }
      unselectRows();
    }
    Serial.println();
  }
}

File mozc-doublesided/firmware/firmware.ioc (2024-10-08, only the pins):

Mcu.UserName=STM32F042F6Px
PA0.GPIO_Label=SW1
PA0.Signal=GPIO_Input
PA1.GPIO_Label=SW2
PA1.Signal=GPIO_Input
PA11.Signal=USB_DM
PA12.Signal=USB_DP
PA13.Signal=SYS_SWDIO
PA14.Signal=SYS_SWCLK
PA2.GPIO_Label=SW3
PA2.Signal=GPIO_Input
PA3.GPIO_Label=SW4
PA3.Signal=GPIO_Input
PA4.GPIO_Label=RDYin
PA4.Signal=GPIO_Input
PA5.Signal=SPI1_SCK
PA6.GPIO_Label=RDYout
PA6.Signal=GPIO_Output
PA7.Signal=SPI1_MOSI
PB1.GPIO_Label=COM1
PB1.Signal=GPIO_Output
PB8.GPIO_Label=COM2
PB8.Signal=GPIO_Output
PF0-OSC_IN.Signal=I2C1_SDA
PF1-OSC_OUT.Signal=I2C1_SCL

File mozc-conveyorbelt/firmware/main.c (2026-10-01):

// Copyright 2026 Google Inc.
// Use of this source code is governed by an Apache License that can be found
// in the LICENSE file.

#include "ch559.h"
#include "flash.h"
#include "gpio.h"
#include "led.h"
#include "serial.h"
#include "switches.h"
#include "timer3.h"
#include "usb/ble/ble_hid_peripheral.h"
#include "usb/usb_host.h"

#define BLE_PASSKEY 738291
#define FLASH_MAGIC 0x4d5a4331  // "MZC1"
#define FLASH_OFFSET_BOND 4

enum {
  APPEARANCE_KEYBOARD = 0x03c1,
  HID_REPORT_LEN      = 8,
};

// HID Boot Keyboard Report Map (Input only; no LED output report).
static const uint8_t HID_REPORT_MAP[] = {
    0x05, 0x01,  // usage page (desktop)
    0x09, 0x06,  // usage (keyboard)
    0xa1, 0x01,  // collection (application)
    0x05, 0x07,  // usage page (key codes)
    0x19, 0xe0,  // usage minimum (224 / left control)
    0x29, 0xe7,  // usage maximum (231 / right gui)
    0x15, 0x00,  // logical minimum (0)
    0x25, 0x01,  // logical maximum (1)
    0x75, 0x01,  // report size (1)
    0x95, 0x08,  // report count (8)
    0x81, 0x02,  // input (modifiers byte)
    0x95, 0x01,  // report count (1)
    0x75, 0x08,  // report size (8)
    0x81, 0x03,  // input constant (reserved byte)
    0x95, 0x06,  // report count (6)
    0x75, 0x08,  // report size (8)
    0x15, 0x00,  // logical minimum (0)
    0x25, 0x65,  // logical maximum (101)
    0x05, 0x07,  // usage page (key codes)
    0x19, 0x00,  // usage minimum (0)
    0x29, 0x65,  // usage maximum (101)
    0x81, 0x00,  // input (key array)
    0xc0,        // end collection
};

static void on_ready(void) {
  Serial.println("advertising");
}

static void on_connected(void) {
  Serial.println("connected");
}

static bool notify_on;
static uint8_t last_report[HID_REPORT_LEN];

static void on_disconnected(void) {
  Serial.println("disconnected, re-advertising");
  notify_on = false;
  for (uint8_t i = 0; i < HID_REPORT_LEN; ++i) {
    last_report[i] = 0;
  }
}

static void on_notify_enabled(bool on) {
  Serial.println(on ? "notify: ON" : "notify: OFF");
  notify_on = on;
}

static uint8_t on_battery_level(void) {
  // No real battery on a USB-powered CH559 demo; report a fixed level so
  // the host shows a plausible value.
  return 100;
}

static void on_sent(void) {
}

static bool on_load_bond(struct smp_bond_info* bond) {
  if (!flash_read(FLASH_OFFSET_BOND, (uint8_t*)bond, sizeof(*bond))) {
    return false;
  }
  bool all_zero = true;
  bool all_ff = true;
  for (uint8_t i = 0; i < sizeof(*bond); i++) {
    uint8_t b = ((const uint8_t*)bond)[i];
    if (b != 0) {
      all_zero = false;
    }
    if (b != 0xff) {
      all_ff = false;
    }
  }
  if (all_zero || all_ff) {
    return false;
  }
  Serial.println("Bonding info loaded from flash");
  return true;
}

static void on_save_bond(const struct smp_bond_info* bond) {
  Serial.println("Saving bonding info to flash...");
  if (flash_write(FLASH_OFFSET_BOND, (const uint8_t*)bond, sizeof(*bond))) {
    Serial.println("Saved!");
  } else {
    Serial.println("Flash write failed!");
  }
}

void main(void) {
  initialize();

  // Initialize serial and print boot message.
  serial_init();
  Serial.println("Booting mozc...");

  // Initialize Data Flash.
  flash_init(FLASH_MAGIC, true);

  // Initialize LED on Port 1, Pin 4 (P1.4, standard for CH559 EVT), Active HIGH.
  led_init(1, 4, HIGH);
  led_mode(L_BLINK);

  // Initialize key switches.
  switches_init();

  // Initialize USB host stack to implement BLE HID over USB-BLE dongle.
  static const struct ble_hid_peripheral hid = {
      .local_name = "Gboard DIY Device",
      .appearance = APPEARANCE_KEYBOARD,
      .manufacturer = "Gboard DIY team",
      .model = "Gboard DIY Device",
      .pnp_id = {BLE_VID_SOURCE_USB_IF, 0xffff, 0x0001, 0x0100},
      .report_map = HID_REPORT_MAP,
      .report_map_len = sizeof(HID_REPORT_MAP),
      .report_len = HID_REPORT_LEN,
      .passkey = BLE_PASSKEY,
      .battery_level = on_battery_level,
      .ready = on_ready,
      .connected = on_connected,
      .disconnected = on_disconnected,
      .notify_enabled = on_notify_enabled,
      .sent = on_sent,
      .load_bond = on_load_bond,
      .save_bond = on_save_bond,
  };
  ble_hid_peripheral_init(&hid, USE_HUB0);
  // TODO: the library sometimes fails to recognize a dongle plugged in at
  // power-on; force a bus reset as a workaround until that's fixed.
  usb_host_reset();

  for (;;) {
    led_poll();
    uint8_t report[HID_REPORT_LEN];
    switches_poll(report, HID_REPORT_LEN);
    if (notify_on) {
      bool changed = false;
      for (uint8_t i = 0; i < HID_REPORT_LEN; ++i) {
        if (report[i] != last_report[i]) {
          changed = true;
          break;
        }
      }
      if (changed && ble_hid_peripheral_send_report(report, HID_REPORT_LEN)) {
        for (uint8_t i = 0; i < HID_REPORT_LEN; ++i) {
          last_report[i] = report[i];
        }
        Serial.printf("Report: mod=%02x keys=[", report[0]);
        for (uint8_t i = 2; i < HID_REPORT_LEN; ++i) {
          Serial.printf("%02x ", report[i]);
        }
        Serial.println("]");
      }
    }
    ble_hid_peripheral_poll();
  }
}

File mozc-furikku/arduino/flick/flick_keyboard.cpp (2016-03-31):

#include "flick_keyboard.h"
#include <stdint.h>

#define ADC_BITS 12

void FlickKeyboard::ProcessSensorData(const SensorData& data, size_t maxKeyNum,
    const char** outputStrings, int* nOutputs) {
  const char* characters[COLS][ROWS] = {
    {"a", "i", "u", "e", "o"},
    {"ka", "ki", "ku", "ke", "ko"},
    {"sa", "si", "su", "se", "so"},
    {"ta", "ti", "tu", "te", "to"},
    {"na", "ni", "nu", "ne", "no"},
    {"ha", "hi", "hu", "he", "ho"},
    {"ma", "mi", "mu", "me", "mo"},
    {"ya", "(", "yu", ")", "yo"},
    {"ra", "ri", "ru", "re", "ro"},
    {"\n", "\b", "", " ", ""},
    {"wa", "wo", "nn", "-", "~"},
    {",", ".", "?", "!", "..."}
  };
  *nOutputs = 0;
  for (size_t i = 0; i < COLS; i++) {
    Direction s = ConvertToFlickState(data.axes[i * 2 + 1],
        data.axes[i * 2], data.button[i]);
    if (lastState[i] == NONE && s != NONE) {
      if (*nOutputs < maxKeyNum) {
        outputStrings[(*nOutputs)++] = characters[i][s];
      }
    }
    lastState[i] = s;
  }
}

FlickKeyboard::FlickKeyboard() {
  for (size_t i = 0; i < COLS; i++) {
    lastState[i] = NONE;
  }
}

Direction FlickKeyboard::ConvertToFlickState(
    int16_t x, int16_t y, bool buttonPressed) {
  const int16_t adScale = 1 << ADC_BITS;
  const int16_t adCenter = adScale / 2;
  const int16_t threshold = adScale * 0.4;

  int16_t diffX = x - adCenter;
  int16_t diffY = y - adCenter;
  if (buttonPressed) {
    return CENTER;
  }
  if (abs(diffX) > abs(diffY)) {
    if (diffX < -threshold) {
      return LEFT;
    } else if (diffX > threshold) {
      return RIGHT;
    }
  } else {
    if (diffY < -threshold) {
      return UP;
    } else if (diffY > threshold) {
      return DOWN;
    }
  }
  return NONE;
}

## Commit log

2013-04-19 Initial upload of the Patapata input device firmware. Moving Morse key files to mozc-morse/ directory.
2015-03-31 Initial checkin of piropiro version.
    [arm.stl, base.stl, holder1.stl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]
2015-04-03 Revise README to remove some redundancy. Add a photo of example device for assembly reference.
2015-08-10 Update STL files. - mesh density adjustment to improve precision - re-orientation to facilitate 3D printing - removal of unnecessary faces to prevent non-manifold errors
    [arm.stl, base.stl, holder1.stl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]
2016-04-01 Add some photos of an example device for reference.
2018-03-31 Add nazoru-input in mozc-nazoru/
    [nazoru-stack.brd, nazoru-stack.sch]
2018-03-31 Update the path to the schematic
2018-06-26 Shorten the wait time.
    [keyboard_recorder.py]
2018-08-03 Shorten the waiting time until inference
    [keyboard_recorder.py]
2018-08-03 Add a LED in chassis (#18)
    LED was equipped in the chassis. This patch turns it on.
    SlowLED changes the brightness gradually. wiringpi is used for it to leverage the hardware PWA equipped by Raspberry Pi.
2018-09-11 Move filterwarnings to the top and surpress FutureWarning too
2019-03-31 Add mozc-mageru/ for Gboard Spoon Bending Version
    [board.brd, board.sch]
2019-04-07 Remove wiringpi from OSX dependency
2021-09-30 Add mozc-yunomi for Gboard Yunomi Version.
    [base.kicad_pcb, base.sch, jig.stl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]
2021-10-04 Rename board directories and add mount hole in base-pcb.
    [base.kicad_pcb, base.sch, yunomi.kicad_pcb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]
2021-10-08 Add silk-screen for USB connector pin assignment.
    [base.kicad_pcb]
2021-12-22 Add yunomi base board for promicro.
    [base-promicro.kicad_pcb, base-promicro.sch]
2021-12-22 Fix key mapping for osakana.
    [firmware.ino]
2021-12-22 Add README for Pro Micro
    [platform_promicro.stl]
2022-06-06 Remove Kicad cache files
2022-10-01 Add mozc-bar for Gboard bar version.
    [controller.kicad_pcb, controller.sch, controller.stl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]
2022-10-08 mozc-bar: Remove PCB shape from type-D case shape data.
    The shape of the PCB was merged into the STL data for type-D case by
    mistake.
    [typeD.stl]
2023-03-28 Update README.md
    PCB及びcaseの準備数がキーマップング画像とファームウェアと差異があったため修正
2023-03-28 [Mozc-bar] Fix length of the frame. (See #46 for details)
2023-10-01 Add mozc-caps.
    [bump_cap_insert_mount.stl, sliding_plate.stl, switch_mount.stl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]
2024-10-08 Add mozc double sided version.
    Reviewed-by: Eliot Courtney <edcourtney@google.com>
    [case00.stl, case01.stl, case02.stl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]
2024-10-08 Add command to enable/disable key output. (#29)
    This function is needed for preventing the device from submitting serial
    commands by itself during calibration.
    [firmware.ino]
2026-10-01 Add mozc conveyorbelt version.
    [BaseCoverL.stl, BaseCoverR.stl, Base_Roller.stl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]
